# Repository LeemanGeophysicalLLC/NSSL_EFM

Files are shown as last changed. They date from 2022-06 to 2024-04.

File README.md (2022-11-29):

# Balloon Borne Electric Field Meter

This repository contains all files and relevant information for the electric field meter
(EFM) designed for NSSL. This instrument has been in existance for many years, but beginning
in approximatley 2019/2020 Leeman Geophysical was contracted to help design and implement the
next generation of the device. This README should be a living document keeping the most
current and relevant information on the assembly, operation, and programming of the
instrument.

Where there are other system components that are not directly part of the instrument (such as
the cutdown system), we will link to the relevant documentation.

## Mechanical Parts

A current version of the Fusion 360 project is [here](Mechanical/EFM%20v92.f3z), but be
careful as it is quite a bear with lots of older artifacts from previous revisions and
the assembly isn't completed as that just wasn't necessary to machine the parts.
Please update any changes made!

### Fiberglass Body and Spheres
These are provided by NSSL and we believed to be made by the OU Physics machine shop at some
time in the past. When more are needed we can evaluate the design and manufacturing options
at that time.

### Foams
The electronics for the EFM are protected from the environment (water, wind, and cold) by the
foam paddles that also serve to direct airflow to make the instrument rotate about the Earth
perpendicular axis. The foams are machined from 1" thick blue insulation foam such as
[item 14615](https://www.lowes.com/pd/Dow-Common-1-in-x-4-ft-x-8-ft-Actual-1-in-x-4-ft-x-8-ft-SCOREBOARD-1-R-5-Faced-Polystyrene-Garage-Door-Foam-Board-Insulation-with-Sound-Barr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) from Lowe's. We machine these on a
large format router and find that screwing the foam down to the base with drywall screws and
using a downcutting bit result in the best cuts. The foams are still difficult to machine well
as they still try to slide around, pull up, and generate massive amounts of static which can
sometimes cause false trips of the router's limit switch system.

Each end of the instrument has four foam plates. The solid models for the control end foams are
[here](Mechanical/Control_Foam/). The solid models for the motor end foams are
[here](Mechanical/Motor_Foam/).

### Machined Parts
We have tried to keep the number of custom machined parts to a minimum to make field repairs
as easy as possible, but there are a few necessary parts. Namely the "hub" which inserts into
the fiberglass tube body and provides driving force and a place for the fiber optic cable to
exit the tube. This hub is made from 6061 Aluminium and has as much material as possible
removed to make it light. This is very similar to the original design from the machine shop,
but with a much simplified bearing setup. A 2D drawing of the hub is available
[here](Mechanical/Machined_Parts/Hub%20Drawing.pdf).

An aluminium shaft screws into the hubs and passes through bearings to provide a low friction
suspension for the tube. The hub shaft 2D drawing is
[here](Mechanical/Machined_Parts/Hub%20Shaft%20Drawing.pdf). This should be secured into the
hubs with Loctite 242 blue thread locker. The other end has M8 washers (like McMaster
[98689A116](https://www.mcmaster.com/98689A116/)) and nuts (like McMaster
[90592A022](https://www.mcmaster.com/90592A022/)). Use Locktite 272 on the nuts.

The motor driver is a socket-like device that turns the rotating assembly by driving the
nut on the end of the hub shaft. It is secured to the motor shaft with #4 set screws such
as McMaster [98637A105](https://www.mcmaster.com/98637A105/). Use Locktite 272 on the set
screws. A drawing of the part is [here](Mechanical/Machined_Parts/Motor%20Driver%20Drawing.pdf).

### End Caps and Bearings
The end caps that support the rotating load are 3D printed for weight, cost, and simplicity.
The original sets were printed in PLA, but those have proven to be somewhat brittle and NSSL
is testing alternatives. The STL file to print the caps is
[here](Mechanical/3D_Prints/endcap.stl). Be sure to print with supports so that the bearing
pockets on the bottom accept the bearing nicely!

We chose easy to find skateboard bearings (8x22x7 size) such as [these](https://amzn.to/3GVvaEM)
and press them in gently with a socket on the outer bearing race and small hammer. There are
two bearings per endcap. End caps are bolted through the foam to either the fiber optic or
motor plates with nylon hardware #6 size.

* Screws McMaster [95868A312](https://www.mcmaster.com/catalog/128/3430/)
* Washers McMaster [90295A380](https://www.mcmaster.com/catalog/128/3546)
* Nuts McMaster [94812A300](https://www.mcmaster.com/catalog/128/3502/)

### Fiber Optic Plate
The [fiber optic coupler (PN 51 0241)](https://i-fiberoptics.com/connector-detail-mating.php?id=825&cat=mating) is inserted through this plate (use the threaded side and included nut).
The coupler is then cutoff flush with the nut, clearnace drilled, and chambered to allow the
fiberoptic cable to slip and turn in the coupler, but still be aligned with the pigtail
running to the control PCBA.

### Motor Mount Plate
The [motor](https://www.digikey.com/en/products/detail/dfrobot/FIT0441/6588579) mounts
to this simple 3D printed plate and is held onto the foam. The motor mounts
with M3 screws that are 5mm long, such as McMaster
[92000A114](https://www.mcmaster.com/92000a114/). The STL file is
[here](Mechanical/3D_Prints/motor_mount_plate.stl).

### Fiber Optic Cable
We use the plastic cable from Industrial Fiberoptics, part [GH4001](https://www.digikey.com/en/products/detail/industrial-fiber-optics/GH4001/1855657) or similar.

## Circuit Boards
### Analog PCBA
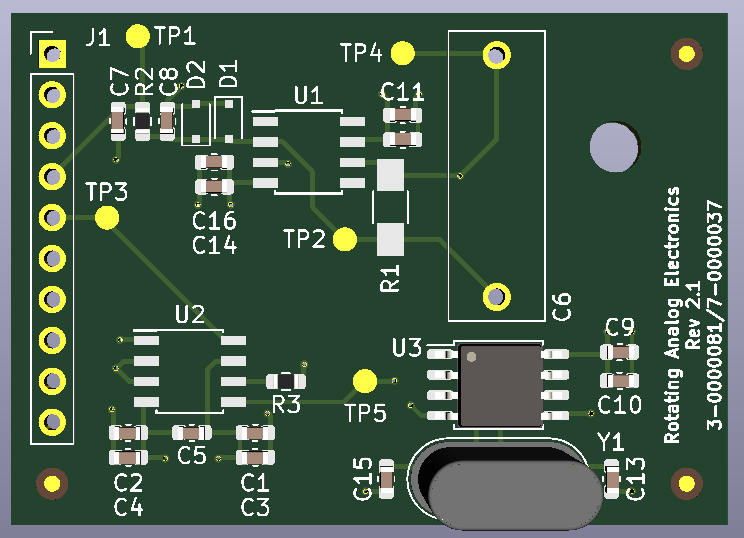
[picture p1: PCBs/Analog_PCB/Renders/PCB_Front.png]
Analog PCBA


The analog PCBA is really the heart of the EFM and what everything else is in service of. It is
a simple charge amplifier and filter. This design is basically a direct copy of the old EFM
as the charge amplifeir and filter were working just fine. We did some pretty extensive
comparisons between the old and new charge amps as well as testing for any temperature
dependence of the amplifier and filter. 

* [KiCAD Project](PCBs/Analog_PCB/KiCAD_Project)
* [PDF schematic](PCBs/Analog_PCB/PDFs/schematic.pdf)
* [Mechancial Drawing](PCBs/Analog_PCB/PDFs/pcb.pdf)

### Control PCBA
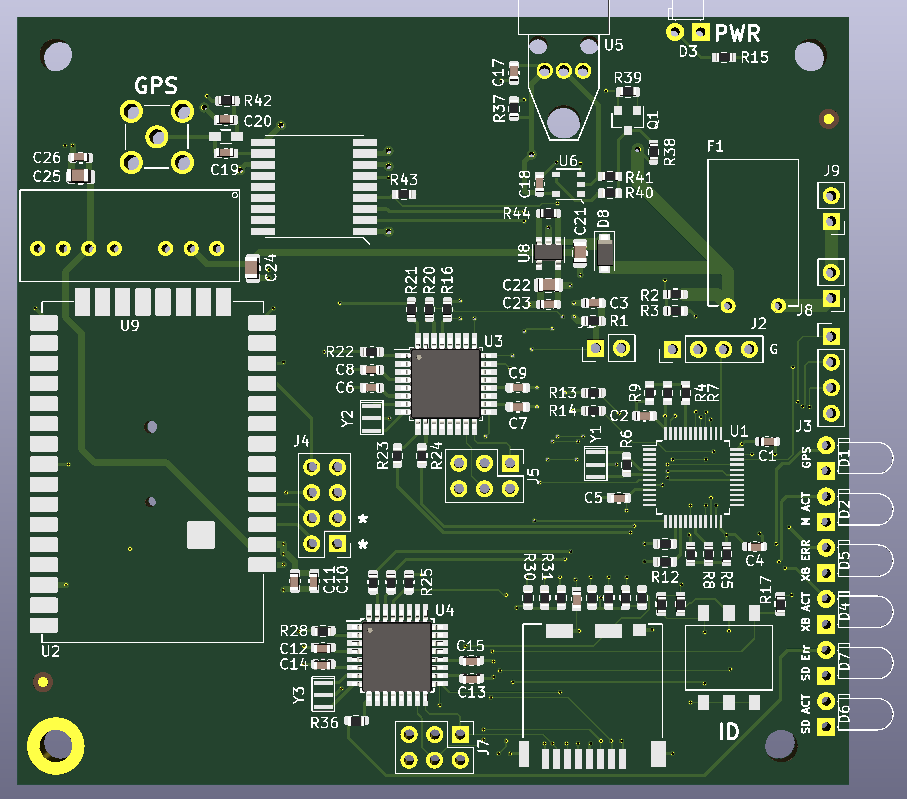
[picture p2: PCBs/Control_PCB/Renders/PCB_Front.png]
Control PCBA


The control PCBA manages the GPS, data logging, and transmitter. This board is easily the most
complex and expensive of the entire unit. There are three processors on the board. While this
is gross overkill, it allows us to easily modify the behavior, move workload, and change
functionality with three relatively simple bits of firmware instead of one more complex bit
that deals with a scheduler. The three functions are receiving fiber/GPS data, writing to the
SD card, and transmitting data. We do plan on moving transmit off the board to its own board
in the future so we can more easily change transmitters. We also need a transmitter evaluation
from NSSL to decide if we stay with XBee, go back to the 433MHz system, or do something
entirely different.

There are indicator lights for the status of the board along the edge
* SD ACT (green) - indicates write activity to the SD Card
* SD Err (red) - blinks at boot, then indicates problems with the SD card system
* XB ACT (green) - indicates write activity to the SD Card
* XB Err (red) - blinks at boot, then indicates problems with the XBee system. It also indicates
when the radio is locked out at startup waiting for the GPS to lock (it is on a timer)
* M ACT (green) - blinks with received data over the fiberoptic link
* GPS (green) - toggles on/off with the receiption of NMEA packets
* PWR (green) - On when battery power is applied

Note, we do not enable the transmitter for some time after boot to allow the GPS to get a lock.
We observed the XBee being active before the GPS locks can greatly increase lock times or in
a few cases even prevent lock.

The two sets of pins with * by the on J4 should be jumpered for the XBee radio to transmit.
You can un-jumper and connect a USB to 3.3V logic cable here to program the XBee radio.

* [KiCAD Project](PCBs/Control_PCB/KiCAD_Project)
* [PDF schematic](PCBs/Control_PCB/PDFs/schematic.pdf)
* [Mechancial Drawing](PCBs/Control_PCB/PDFs/pcb.pdf)

### CR123 Battery PCBA
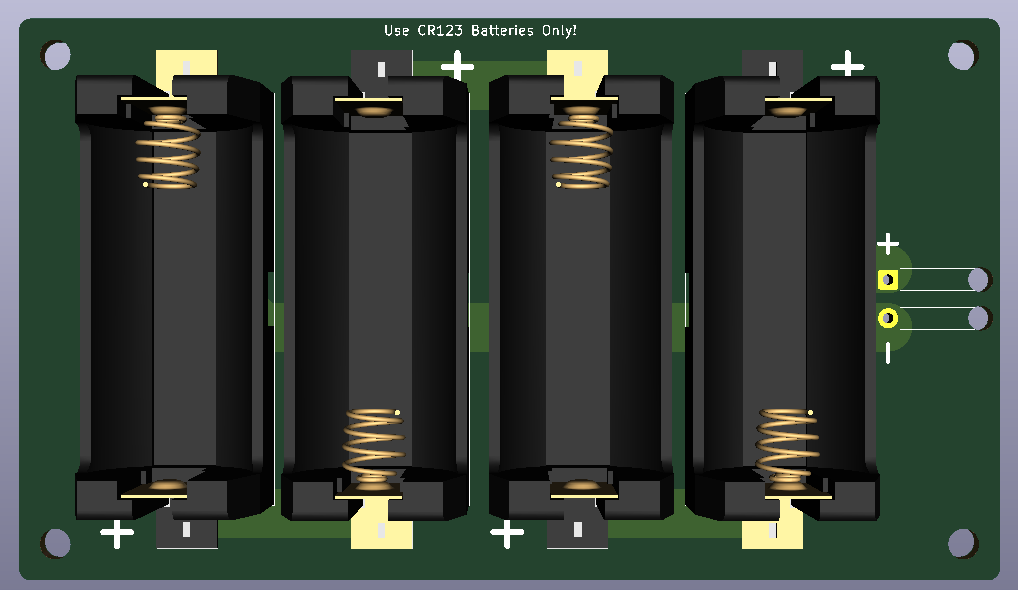
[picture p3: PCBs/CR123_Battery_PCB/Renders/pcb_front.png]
CR123 PCBA


This PCB is used for power of most items in the EFM for convenience. We tried CR2 batteries
and there is a CR2 board in the repository history, but they didn't have the capacity for all
applications and we didn't want to have yet another battery type on-board. There isn't much
to this board.

* [KiCAD Project](PCBs/CR123_Battery_PCB/KiCAD_Project)
* [PDF schematic](PCBs/CR123_Battery_PCB/PDFs/schematic.pdf)
* [Mechancial Drawing](PCBs/CR123_Battery_PCB/PDFs/pcb.pdf)

### Digital PCBA
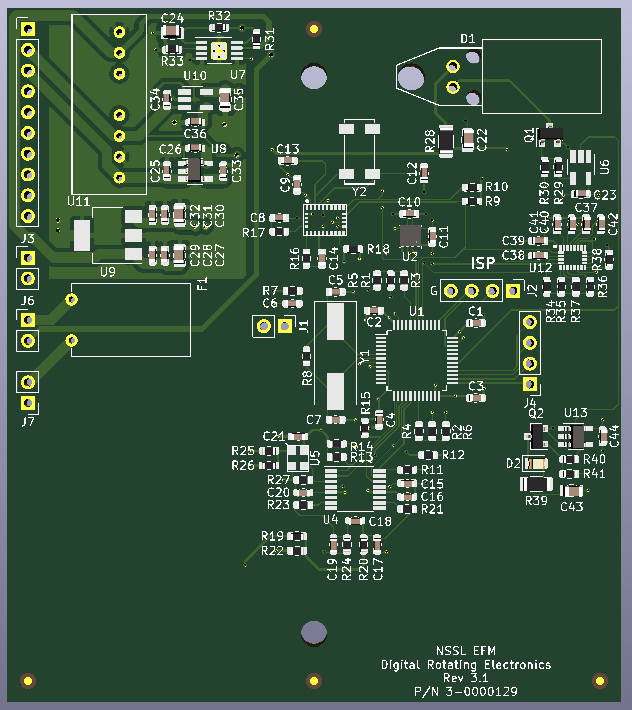
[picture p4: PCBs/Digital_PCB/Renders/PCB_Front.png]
Digital PCBA


The digital PCBA provides power to the analog PCBA, digitizes the charge amplifier, collects
IMU data, temperature, pressure, humidity, and sends it all down the fiber to the control
PCBA in the end foam. This PCB is relatively complex and has multiple IMU footprints as
the supply chain in 2022 has made it difficult to get any IMU, much less the same one over
and over. There is also a delay turn on circuit to help debounce the switch, but it was not
populated in the November 2022 batch as the parts were not available. Performance did not
appear to be impacted. There is an LED (D2) that mirrors the fiber sender for easy visual
confirmatino that data are being sent.

* [KiCAD Project](PCBs/Digital_PCB/KiCAD_Project)
* [PDF schematic](PCBs/Digital_PCB/PDFs/schematic.pdf)
* [Mechancial Drawing](PCBs/Digital_PCB/PDFs/pcb.pdf)

### Motor Control PCBA
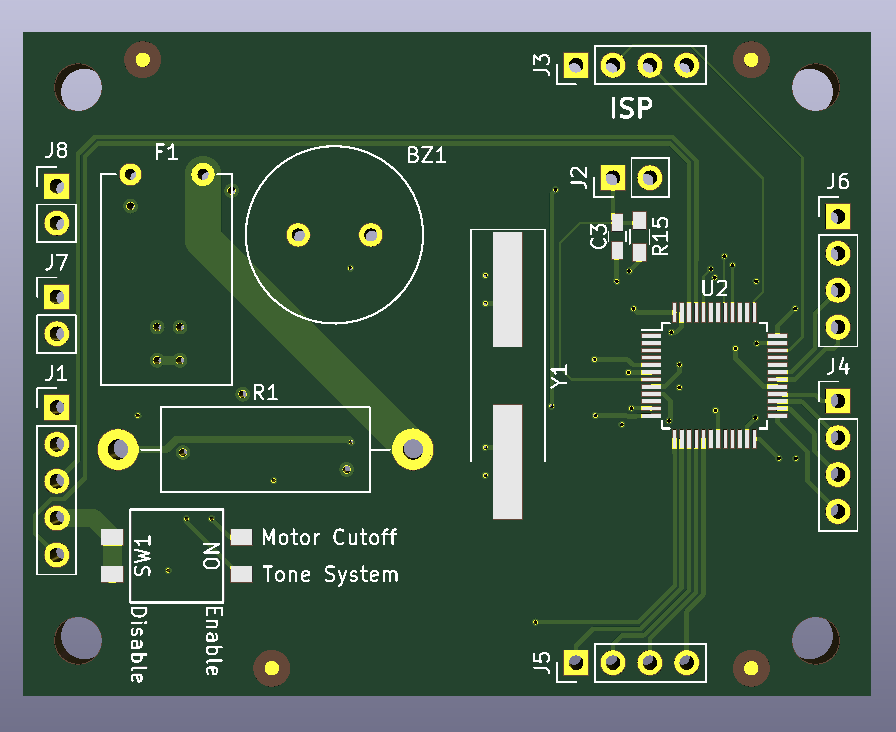
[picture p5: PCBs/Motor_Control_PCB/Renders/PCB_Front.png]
Motor Control PCBA


The motor control PCBA controls the PWM speed signal to the motor, which is a [DFRobot
FIT0441](https://www.digikey.com/en/products/detail/dfrobot/FIT0441/6588579), by reading
the motor's built in encoder. We target 120 RPM for the motor speed. In the November 2022
run we had to modify the PID coefficients with the newest motors and NSSL reports a slower
rotation rate, making meaning they changed the encoders in the motors. This requires further
investigation.

This board also houses a tone system which can be turned on to play a series of tones after
the motor has been detected as stalled. The motor cutoff on stall can be enabled or disabled.
At NSSL's request, if enabled, the motor will attempt to restart after approximately 1 minute.

* [KiCAD Project](PCBs/Motor_Control_PCB/KiCAD_Project)
* [PDF schematic](PCBs/Motor_Control_PCB/PDFs/schematic.pdf)
* [Mechancial Drawing](PCBs/Motor_Control_PCB/PDFs/pcb.pdf)

### Tracker PCBA
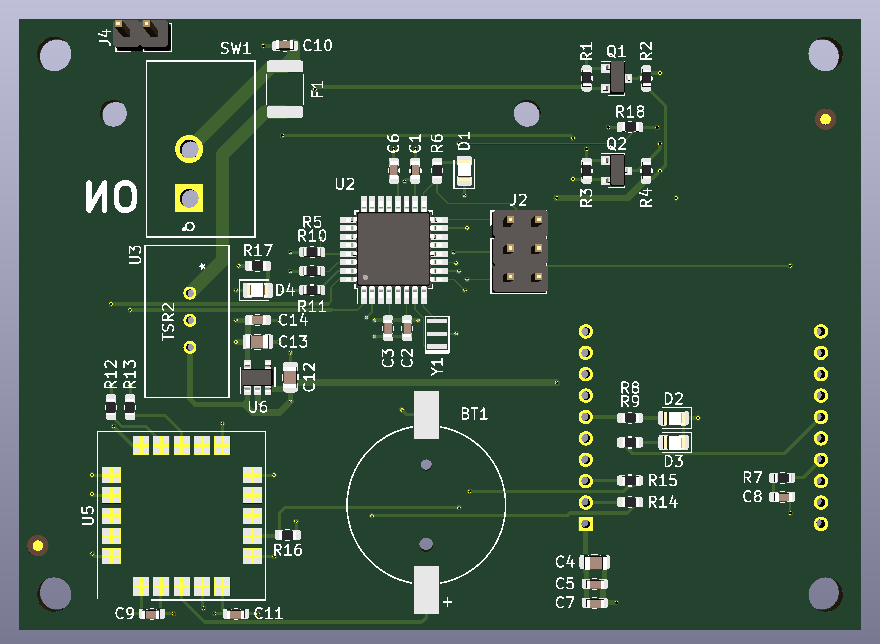
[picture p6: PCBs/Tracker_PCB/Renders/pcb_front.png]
Tracker PCBA


The tracker is designed to radio a GPS position and altitude to the Rock7 satellite network
to help with getting the instrument back. It also passes cutdown messages to the cutdown
module from satellite via a short-range XBee link.

* [KiCAD Project](PCBs/Tracker_PCB/KiCAD_Project)
* [PDF schematic](PCBs/Tracker_PCB/PDFs/schematic.pdf)
* [Mechancial Drawing](PCBs/Tracker_PCB/PDFs/pcb.pdf)

# Design Decisions Captured
* NSSL requested the tracker be independent from the rest of the instrument to allow it to be
used on other instruments and as a fully independent system.
* NSSL requested the cutdown be entire sepearte and as low cost as possible as these are not
always retreived. Hence the decision to NOT put a sat modem on it and/or combine it with the
tracker. There were also concerns of the train becoming seperated and not having a tracker
directly embedded with the expensive EFM or other instrument.

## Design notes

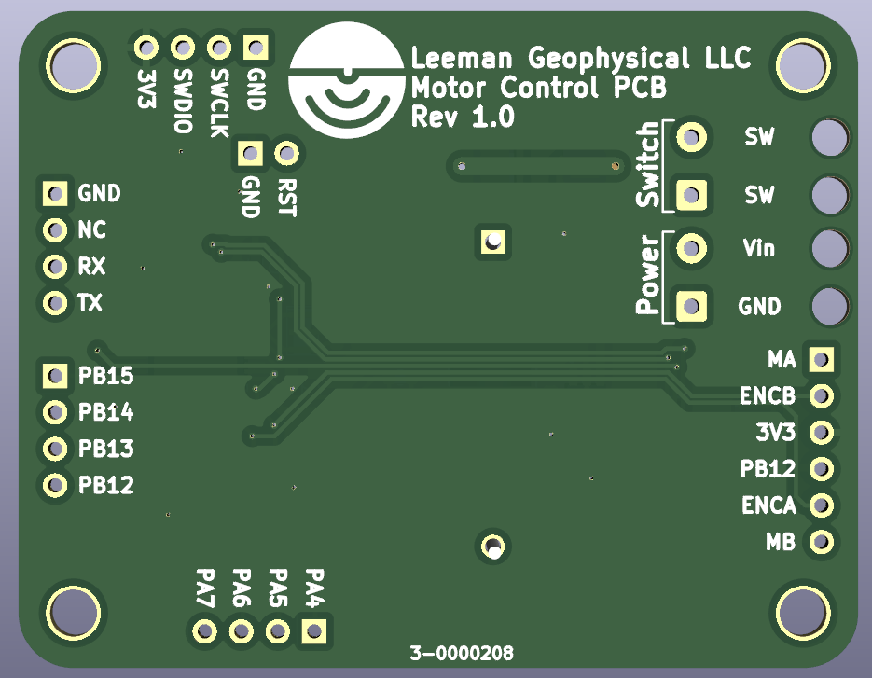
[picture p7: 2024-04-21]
PCBs/Motor_Control_PCB/Renders/pcb_back.png

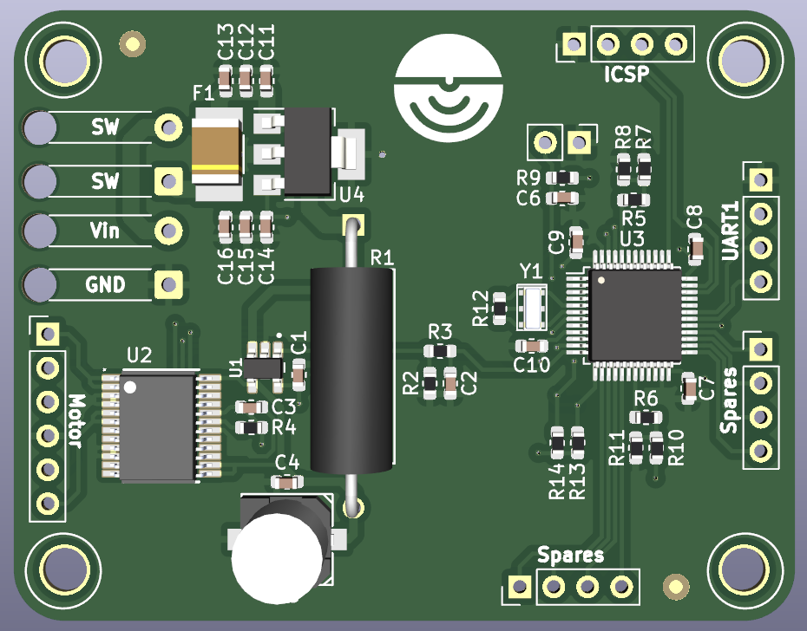
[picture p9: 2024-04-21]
PCBs/Motor_Control_PCB/Renders/pcb_front.png

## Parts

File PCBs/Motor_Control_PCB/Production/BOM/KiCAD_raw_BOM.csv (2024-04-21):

Reference | Value | Datasheet | Footprint | Qty | Internal Part Number | PValue | Populated
C1 | 1-0000007 | ~ | capacitors_0603:1-0000007 | 1 | 1-0000007 | 0.1uF | 1
C2 | 1-0000007 | ~ | capacitors_0603:1-0000007 | 1 | 1-0000007 | 0.1uF | 1
C3 | 1-0000007 | ~ | capacitors_0603:1-0000007 | 1 | 1-0000007 | 0.1uF | 1
C4 | 1-0000007 | ~ | capacitors_0603:1-0000007 | 1 | 1-0000007 | 0.1uF | 1
C5 | 1-0000176 | ~ | capacitors:1-0000176 | 1 | 1-0000176 | 10µF | 1
C6 | 1-0000018 | ~ | capacitors_0603:1-0000018 | 1 | 1-0000018 | 1uF | 1
C7 | 1-0000007 | ~ | capacitors_0603:1-0000007 | 1 | 1-0000007 | 0.1uF | 1
C8 | 1-0000007 | ~ | capacitors_0603:1-0000007 | 1 | 1-0000007 | 0.1uF | 1
C9 | 1-0000007 | ~ | capacitors_0603:1-0000007 | 1 | 1-0000007 | 0.1uF | 1
C10 | 1-0000007 | ~ | capacitors_0603:1-0000007 | 1 | 1-0000007 | 0.1uF | 1
C11 | 1-0000005 | ~ | capacitors_0603:1-0000005 | 1 | 1-0000005 | 10uF | 1
C12 | 1-0000018 | ~ | capacitors_0603:1-0000018 | 1 | 1-0000018 | 1uF | 1
C13 | 1-0000007 | ~ | capacitors_0603:1-0000007 | 1 | 1-0000007 | 0.1uF | 1
C14 | 1-0000007 | ~ | capacitors_0603:1-0000007 | 1 | 1-0000007 | 0.1uF | 1
C15 | 1-0000018 | ~ | capacitors_0603:1-0000018 | 1 | 1-0000018 | 1uF | 1
C16 | 1-0000005 | ~ | capacitors_0603:1-0000005 | 1 | 1-0000005 | 10uF | 1
F1 | 1-0001547 | ~ | fuses:1-0001547 | 1 | 1-0001547 | 5A | 1
FID1 | Fiducial_1mm_2mm | ~ | mechanical:Fiducial_1mm_Mask2mm | 1 | 0-0000000 | Fiducial | 0
FID2 | Fiducial_1mm_2mm | ~ | mechanical:Fiducial_1mm_Mask2mm | 1 | 0-0000000 | Fiducial | 0
H1 | Imperial4 | None | mechanical:MountingHole_imperial4 | 1 | 0-0000000 | #4 | 0
H2 | Imperial4 | None | mechanical:MountingHole_imperial4 | 1 | 0-0000000 | #4 | 0
H3 | Imperial4 | None | mechanical:MountingHole_imperial4 | 1 | 0-0000000 | #4 | 0
H4 | Imperial4 | None | mechanical:MountingHole_imperial4 | 1 | 0-0000000 | #4 | 0
J1 | NP_Conn_01x06 | ~ | np_connectors:PinHeader_1x06_P2.54mm_Vertical | 1 | 0-0000000 | 01x06 | 0
J2 | NP_Conn_01x02 | ~ | np_connectors:PinHeader_1x02_P2.54mm_Vertical | 1 | 0-0000000 | NP_Conn_01x02 | 0
J3 | NP_Conn_01x04 | ~ | np_connectors:PinHeader_1x04_P2.54mm_Vertical | 1 | 0-0000000 | NP_Conn_01x04 | 0
J4 | NP_Conn_01x04 | ~ | np_connectors:PinHeader_1x04_P2.54mm_Vertical | 1 | 0-0000000 | NP_Conn_01x04 | 0
J5 | NP_Conn_01x04 | ~ | np_connectors:PinHeader_1x04_P2.54mm_Vertical | 1 | 0-0000000 | NP_Conn_01x04 | 0
J6 | NP_Conn_01x04 | ~ | np_connectors:PinHeader_1x04_P2.54mm_Vertical | 1 | 0-0000000 | NP_Conn_01x04 | 0
J7 | NP_Conn_01x02_Relief | ~ | np_connectors:SolderWire_1x02_Relief | 1 | 0-0000000 | NP_Conn_01x02 | 0
J8 | NP_Conn_01x02_Relief | ~ | np_connectors:SolderWire_1x02_Relief | 1 | 0-0000000 | NP_Conn_01x02 | 0
PCB1 | barepcb |  | misc:barepcb | 1 | 3-0000208 | Bare PCB | 1
R1 | 1-0001546 | ~ | resistors:1-0001546 | 1 | 1-0001546 | 100m | 1
R2 | 1-0000010 | ~ | resistors_0603:1-0000010 | 1 | 1-0000010 | 10k | 1
R3 | 1-0000009 | ~ | resistors_0603:1-0000009 | 1 | 1-0000009 | 1M | 1
R4 | 1-0000010 | ~ | resistors_0603:1-0000010 | 1 | 1-0000010 | 10k | 1
R5 | 1-0000174 | ~ | resistors_0603:1-0000174 | 1 | 1-0000174 | 100k | 1
R6 | 1-0000174 | ~ | resistors_0603:1-0000174 | 1 | 1-0000174 | 100k | 1
R7 | 1-0000006 | ~ | resistors_0603:1-0000006 | 1 | 1-0000006 | NP | 0
R8 | 1-0000006 | ~ | resistors_0603:1-0000006 | 1 | 1-0000006 | 0R0 | 1
R9 | 1-0000010 | ~ | resistors_0603:1-0000010 | 1 | 1-0000010 | 10k | 1
R10 | 1-0000006 | ~ | resistors_0603:1-0000006 | 1 | 1-0000006 | NP | 0
R11 | 1-0000006 | ~ | resistors_0603:1-0000006 | 1 | 1-0000006 | 0R0 | 1
R12 | 1-0000006 | ~ | resistors_0603:1-0000006 | 1 | 1-0000006 | NP | 0
R13 | 1-0000010 | ~ | resistors_0603:1-0000010 | 1 | 1-0000010 | 10k | 1
R14 | 1-0000010 | ~ | resistors_0603:1-0000010 | 1 | 1-0000010 | 10k | 1
U1 | 1-0000452 |  | others:1-0000452 | 1 | 1-0000452 | INA169 | 1
U2 | 1-0001532 |  | motor_drivers:1-0001532 | 1 | 1-0001532 | TB6612 | 1
U3 | 1-0000207 |  | microcontrollers:1-0000207 | 1 | 1-0000207 | STM32F103 | 1
U4 | 1-0000196 |  | regulators:1-0000196 | 1 | 1-0000196 | LT1521 | 1
Y1 | 1-0000721 | ~ | crystals_resonators:1-0000721 | 1 | 1-0000721 | 8MHz | 1

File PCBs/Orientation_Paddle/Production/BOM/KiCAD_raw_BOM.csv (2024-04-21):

Reference | Value | Datasheet | Footprint | Qty | Internal Part Number | PValue | Populated
BT1 | 1-0000246 |  | batteries:1-0000246 | 1 | 1-0000246 | CR1220 | 1
C1 | 1-0000007 | ~ | capacitors_0603:1-0000007 | 1 | 1-0000007 | 0.1uF | 1
C2 | 1-0000136 | ~ | capacitors_1206:1-0000136 | 1 | 1-0000136 | 4.7uF | 1
C3 | 1-0000018 | ~ | capacitors_0603:1-0000018 | 1 | 1-0000018 | 1uF | 1
C4 | 1-0000136 | ~ | capacitors_1206:1-0000136 | 1 | 1-0000136 | 4.7uF | 1
C5 | 1-0000019 | ~ | capacitors_0603:1-0000019 | 1 | 1-0000019 | 4.7uF | 1
C6 | 1-0000007 | ~ | capacitors_0603:1-0000007 | 1 | 1-0000007 | 0.1uF | 1
C7 | 1-0000018 | ~ | capacitors_0603:1-0000018 | 1 | 1-0000018 | 1uF | 1
C8 | 1-0000007 | ~ | capacitors_0603:1-0000007 | 1 | 1-0000007 | 0.1uF | 1
C9 | 1-0000007 | ~ | capacitors_0603:1-0000007 | 1 | 1-0000007 | 0.1uF | 1
C10 | 1-0000007 | ~ | capacitors_0603:1-0000007 | 1 | 1-0000007 | 0.1uF | 1
C11 | 1-0000007 | ~ | capacitors_0603:1-0000007 | 1 | 1-0000007 | 0.1uF | 1
C12 | 1-0000007 | ~ | capacitors_0603:1-0000007 | 1 | 1-0000007 | 0.1uF | 1
C13 | 1-0000007 | ~ | capacitors_0603:1-0000007 | 1 | 1-0000007 | 0.1uF | 1
C14 | 1-0000075 | ~ | capacitors_0805:1-0000075 | 1 | 1-0000075 | 10uF | 1
C15 | 1-0000018 | ~ | capacitors_0603:1-0000018 | 1 | 1-0000018 | 1uF | 1
C16 | 1-0000007 | ~ | capacitors_0603:1-0000007 | 1 | 1-0000007 | 0.1uF | 1
C17 | 1-0000007 | ~ | capacitors_0603:1-0000007 | 1 | 1-0000007 | 0.1uF | 1
C18 | 1-0000007 | ~ | capacitors_0603:1-0000007 | 1 | 1-0000007 | 0.1uF | 1
C19 | 1-0000007 | ~ | capacitors_0603:1-0000007 | 1 | 1-0000007 | 0.1uF | 0
C20 | 1-0000007 | ~ | capacitors_0603:1-0000007 | 1 | 1-0000007 | 0.1uF | 1
D1 | 1-0000399 |  | leds_other:1-0000399 | 1 | 1-0000399 | 1655 | 1
D2 | 1-0000599 | ~ | leds_0805:1-0000599 | 1 | 1-0000599 | Blue | 1
D3 | 1-0000601 | ~ | leds_0805:1-0000601 | 1 | 1-0000601 | Yellow | 1
F1 | 1-0001517 | ~ | fuses:1-0001517 | 1 | 1-0001517 | 1A | 1
FID1 | Fiducial_1mm_2mm | ~ | mechanical:Fiducial_1mm_Mask2mm | 1 | 0-0000000 | Fiducial | 0
FID2 | Fiducial_1mm_2mm | ~ | mechanical:Fiducial_1mm_Mask2mm | 1 | 0-0000000 | Fiducial | 0
H1 | Imperial6 | None | mechanical:MountingHole_imperial6 | 1 | 0-0000000 | M3 | 0
H2 | Imperial6 | None | mechanical:MountingHole_imperial6 | 1 | 0-0000000 | M3 | 0
H3 | Imperial6 | None | mechanical:MountingHole_imperial6 | 1 | 0-0000000 | M3 | 0
H4 | Imperial6 | None | mechanical:MountingHole_imperial6 | 1 | 0-0000000 | M3 | 0
J1 | NP_Conn_01x04_Relief | ~ | np_connectors:SolderWire_1x04_Relief | 1 | 0-0000000 | Encoder | 0
J2 | 1-0001205 | ~ | connectors:1-0001205 | 1 | 1-0001205 | Qwiic | 1
J3 | NP_Conn_01x03_Relief | ~ | np_connectors:SolderWire_1x03_Relief | 1 | 0-0000000 | AH1815 (1-1545) | 0
J4 | NP_Conn_01x02_Relief | ~ | np_connectors:SolderWire_1x02_Relief | 1 | 0-0000000 | NP_Conn_01x02 | 0
J5 | NP_Conn_01x02_Relief | ~ | np_connectors:SolderWire_1x02_Relief | 1 | 0-0000000 | NP_Conn_01x02 | 0
J6 | NP_Conn_01x04 | ~ | np_connectors:PinHeader_1x04_P2.54mm_Vertical | 1 | 0-0000000 | Debug | 0
J7 | NP_Conn_01x04 | ~ | np_connectors:PinHeader_1x04_P2.54mm_Vertical | 1 | 0-0000000 | ISP | 0
J8 | NP_Conn_01x02 | ~ | np_connectors:PinHeader_1x02_P2.54mm_Vertical | 1 | 0-0000000 | Reset | 0
J9 | 1-0000050 | ~ | connectors:1-0000050 | 1 | 1-0000050 | XBee Socket | 1
J10 | 1-0000190 |  | connectors:1-0000190 | 1 | 1-0000190 | DM3CS | 1
JP1 | SolderJumper_3_Open | ~ | Jumper:SolderJumper-3_P1.3mm_Open_RoundedPad1.0x1.5mm_NumberLabels | 1
JP2 | SolderJumper_3_Open | ~ | Jumper:SolderJumper-3_P1.3mm_Open_RoundedPad1.0x1.5mm_NumberLabels | 1
JP5 | SolderJumper_3_Open | ~ | Jumper:SolderJumper-3_P1.3mm_Open_RoundedPad1.0x1.5mm_NumberLabels | 1
JP6 | SolderJumper_3_Open | ~ | Jumper:SolderJumper-3_P1.3mm_Open_RoundedPad1.0x1.5mm_NumberLabels | 1
L1 | 1-0000931 |  | inductors:1-0000931 | 1 | 1-0000931 | 3.3uH | 1
PCB1 | barepcb |  | misc:barepcb | 1 | 3-0000205 | Bare PCB | 1
PS1 | 1-0000727 |  | dc_dc_converters:1-0000727 | 1 | 1-0000727 | TSR 0.5 | 1
R1 | 1-0000679 | ~ | resistors_0603:1-0000679 | 1 | 1-0000679 | 470 | 1
R2 | 1-0000009 | ~ | resistors_0603:1-0000009 | 1 | 1-0000009 | NP | 0
R3 | 1-0000010 | ~ | resistors_0603:1-0000010 | 1 | 1-0000010 | 10k | 1
R4 | 1-0000010 | ~ | resistors_0603:1-0000010 | 1 | 1-0000010 | 10k | 1
R5 | 1-0000010 | ~ | resistors_0603:1-0000010 | 1 | 1-0000010 | 10k | 1
R6 | 1-0000010 | ~ | resistors_0603:1-0000010 | 1 | 1-0000010 | 10k | 1
R7 | 1-0000010 | ~ | resistors_0603:1-0000010 | 1 | 1-0000010 | 10k | 1
R8 | 1-0000010 | ~ | resistors_0603:1-0000010 | 1 | 1-0000010 | 10k | 1
R9 | 1-0000006 | ~ | resistors_0603:1-0000006 | 1 | 1-0000006 | NP | 0
R10 | 1-0000174 | ~ | resistors_0603:1-0000174 | 1 | 1-0000174 | 100k | 1
R11 | 1-0000010 | ~ | resistors_0603:1-0000010 | 1 | 1-0000010 | 10k | 1
R12 | 1-0000006 | ~ | resistors_0603:1-0000006 | 1 | 1-0000006 | NP | 0
R13 | 1-0000174 | ~ | resistors_0603:1-0000174 | 1 | 1-0000174 | 100k | 1
R14 | 1-0000010 | ~ | resistors_0603:1-0000010 | 1 | 1-0000010 | 10k | 1
R15 | 1-0000008 | ~ | resistors_0603:1-0000008 | 1 | 1-0000008 | 150 | 1
R16 | 1-0000006 | ~ | resistors_0603:1-0000006 | 1 | 1-0000006 | NP | 0
R17 | 1-0000008 | ~ | resistors_0603:1-0000008 | 1 | 1-0000008 | 150 | 1
R18 | 1-0000174 | ~ | resistors_0603:1-0000174 | 1 | 1-0000174 | 100k | 1
R19 | 1-0000174 | ~ | resistors_0603:1-0000174 | 1 | 1-0000174 | 100k | 1
U1 | 1-0001232 |  | regulators:1-0001232 | 1 | 1-0001232 | LDL1117 | 1
U2 | 1-0001471 |  | sensors:1-0001471 | 1 | 1-0001471 | BME688 | 1
U3 | 1-0000207 |  | microcontrollers:1-0000207 | 1 | 1-0000207 | STM32F103 | 1
U4 | 1-0000446 |  | others:1-0000446 | 1 | 1-0000446 | SAM-M8Q-0-10 | 1
U5 | 1-0000785 |  | others:1-0000785 | 1 | 1-0000785 | XB3-24 | 1
Y1 | 1-0000721 | ~ | crystals_resonators:1-0000721 | 1 | 1-0000721 | 8MHz | 1

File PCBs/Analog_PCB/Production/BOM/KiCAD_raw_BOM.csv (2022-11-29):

Reference | Value | Footprint | Datasheet | Internal Part Number | Populated
C7 | 0.39nF | Capacitor_SMD:C_0603_1608Metric | ~ | 1-0000418 | 1
C8 | 0.39nF | Capacitor_SMD:C_0603_1608Metric | ~ | 1-0000418 | 1
R2 | 100 | Resistor_SMD:R_0603_1608Metric | ~ | 1-0000180 | 1
D1 | 1N4148 | Diodes_SMD:D_SOD-323F | ~ | 1-0000417 | 1
D2 | 1N4148 | Diodes_SMD:D_SOD-323F | ~ | 1-0000417 | 1
C6 | 0.1u | lib_fp:1-0000787 | ~ | 1-0000787 | 1
R1 | 100M | Resistors_SMD:R_1206_HandSoldering | ~ | 1-0000416 | 1
U1 | LF356 | Housings_SOIC:SOIC-8_3.9x4.9mm_Pitch1.27mm |  | 1-0000419 | 1
U2 | LTC1569-6 | Housings_SOIC:SOIC-8_3.9x4.9mm_Pitch1.27mm |  | 1-0000414 | 1
R3 | 10k | Resistor_SMD:R_0603_1608Metric | ~ | 1-0000010 | 1
C5 | 1u | Capacitor_SMD:C_0603_1608Metric | ~ | 1-0000018 | 1
C3 | 0.1u | Capacitor_SMD:C_0603_1608Metric | ~ | 1-0000007 | 1
C4 | 0.1u | Capacitor_SMD:C_0603_1608Metric | ~ | 1-0000007 | 1
C12 | 0.1u | Capacitor_SMD:C_0603_1608Metric | ~ | 1-0000007 | 1
C14 | 0.1u | Capacitor_SMD:C_0603_1608Metric | ~ | 1-0000007 | 1
C11 | 1u | Capacitor_SMD:C_0603_1608Metric | ~ | 1-0000018 | 1
C16 | 1u | Capacitor_SMD:C_0603_1608Metric | ~ | 1-0000018 | 1
C2 | 1u | Capacitor_SMD:C_0603_1608Metric | ~ | 1-0000018 | 1
C1 | 1u | Capacitor_SMD:C_0603_1608Metric | ~ | 1-0000018 | 1
J1 | Board to Board | Pin_Headers:Pin_Header_Straight_1x10_Pitch2.54mm | ~ | 0-0000000 | 1
TP3 | TestPoint | Measurement_Points:Measurement_Point_Round-SMD-Pad_Small | ~ | 0-0000000 | 0
TP4 | TestPoint | Measurement_Points:Measurement_Point_Round-SMD-Pad_Small | ~ | 0-0000000 | 0
TP2 | TestPoint | Measurement_Points:Measurement_Point_Round-SMD-Pad_Small | ~ | 0-0000000 | 0
TP1 | TestPoint | Measurement_Points:Measurement_Point_Round-SMD-Pad_Small | ~ | 0-0000000 | 0
TP5 | TestPoint | Measurement_Points:Measurement_Point_Round-SMD-Pad_Small | ~ | 0-0000000 | 0
H1 | MountingHole | Mounting_Holes:MountingHole_3.2mm_M3_ISO7380 | ~ | 0-0000000 | 0
FID1 | Fiducial | Fiducials:Fiducial_1mm_Dia_2mm_Outer | ~ | 0-0000000 | 0
FID2 | Fiducial | Fiducials:Fiducial_1mm_Dia_2mm_Outer | ~ | 0-0000000 | 0
FID3 | Fiducial | Fiducials:Fiducial_1mm_Dia_2mm_Outer | ~ | 0-0000000 | 0
U3 | ATtiny45-20SU | Package_SO:SOIC-8_5.275x5.275mm_P1.27mm | http://ww1.microchip.com/downloads/en/DeviceDoc/atmel-2586-avr-8-bit-microcontroller-attiny25-attiny45-attiny85_datasheet.pdf | 1-0000758 | 1
C9 | 1u | Capacitor_SMD:C_0603_1608Metric | ~ | 1-0000018 | 1
C10 | 0.1u | Capacitor_SMD:C_0603_1608Metric | ~ | 1-0000007 | 1
Y1 | 20MHz | Crystal:Crystal_HC49-U_Vertical | ~ | 1-0000723 | 1
C13 | 20p | Capacitor_SMD:C_0603_1608Metric | ~ | 1-0000204 | 1
C15 | 20p | Capacitor_SMD:C_0603_1608Metric | ~ | 1-0000204 | 1
PCB1 | barepcb | misc:barepcb |  | 3-0000081 | 1

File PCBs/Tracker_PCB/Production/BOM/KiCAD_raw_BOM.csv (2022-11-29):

Reference | Value | Footprint | Datasheet | Internal Part Number | Populated | PValue
J1 | RockBlock9603 | lib_fp:picoblade | ~ | 1-0000790 | 1
U5 | ublox_SAM-M8Q | RF_GPS:ublox_SAM-M8Q | https://www.u-blox.com/sites/default/files/SAM-M8Q_DataSheet_%28UBX-16012619%29.pdf | 1-0000446 | 1
BT1 | CR1220 | lib_fp:S8411-45R | ~ | 1-0000246 | 1
C11 | 1-0000007 | capacitors_0603:1-0000007 | ~ | 1-0000007 | 1 | 0.1uF
C9 | 1-0000007 | capacitors_0603:1-0000007 | ~ | 1-0000007 | 1 | 0.1uF
U1 | XBee | lib_fp:XBee |  | 1-0000785 | 1
U3 | TSR2 | lib_fp:TSR 2-2450 |  | 1-0000748 | 1
J4 | Battery | Connector_PinHeader_2.54mm:PinHeader_1x02_P2.54mm_Vertical | ~ | 0-0000000 | 0
SW1 | SW_SPST | lib_fp:SW_GF-123-0054 | ~ | 1-0000786 | 1
J3 | Switch | Connector_PinHeader_2.54mm:PinHeader_1x02_P2.54mm_Vertical | ~ | 0-0000000 | 0
U6 | MIC5219-3.3YM5 | Package_TO_SOT_SMD:SOT-23-5 | http://ww1.microchip.com/downloads/en/DeviceDoc/MIC5219-500mA-Peak-Output-LDO-Regulator-DS20006021A.pdf | 1-0000658 | 1
F1 | Polyfuse | Fuse:Fuse_1812_4532Metric | ~ | 1-0000002 | 1
C10 | 1-0000007 | capacitors_0603:1-0000007 | ~ | 1-0000007 | 1 | 0.1uF
C14 | 1-0000007 | capacitors_0603:1-0000007 | ~ | 1-0000007 | 1 | 0.1uF
J2 | ICSP | Connector_PinHeader_2.54mm:PinHeader_2x03_P2.54mm_Vertical | ~ | 0-0000000 | 0
C5 | 1-0000018 | capacitors_0603:1-0000018 | ~ | 1-0000018 | 1 | 1uF
C7 | 1-0000007 | capacitors_0603:1-0000007 | ~ | 1-0000007 | 1 | 0.1uF
U2 | ATmega328P-AU | Package_QFP:TQFP-32_7x7mm_P0.8mm |  | 1-0000566 | 1
C6 | 1-0000007 | capacitors_0603:1-0000007 | ~ | 1-0000007 | 1 | 0.1uF
Y1 | 16MHz | lib_fp:Resonator | ~ | 1-0000569 | 1
R5 | 1-0000010 | resistors_0603:1-0000010 | ~ | 1-0000010 | 1 | 10k
C1 | 1-0000007 | capacitors_0603:1-0000007 | ~ | 1-0000007 | 1 | 0.1uF
C2 | 1-0000007 | capacitors_0603:1-0000007 | ~ | 1-0000007 | 1 | 0.1uF
C3 | 1-0000007 | capacitors_0603:1-0000007 | ~ | 1-0000007 | 1 | 0.1uF
R10 | 1-0000006 | resistors_0603:1-0000006 | ~ | 1-0000006 | 1 | 0R0
R11 | 1-0000006 | resistors_0603:1-0000006 | ~ | 1-0000006 | 1 | 0R0
R12 | 1-0000006 | resistors_0603:1-0000006 | ~ | 1-0000006 | 1 | 0R0
R13 | 1-0000006 | resistors_0603:1-0000006 | ~ | 1-0000006 | 1 | 0R0
R14 | 1-0000006 | resistors_0603:1-0000006 | ~ | 1-0000006 | 1 | 0R0
R15 | 1-0000006 | resistors_0603:1-0000006 | ~ | 1-0000006 | 1 | 0R0
R8 | 1-0000008 | resistors_0603:1-0000008 | ~ | 1-0000008 | 1 | 150
D2 | Blue | LED_SMD:LED_0805_2012Metric | ~ | 1-0000599 | 1
R9 | 1-0000008 | resistors_0603:1-0000008 | ~ | 1-0000008 | 1 | 150
D3 | Yellow | LED_SMD:LED_0805_2012Metric | ~ | 1-0000601 | 1
R7 | 1-0000006 | resistors_0603:1-0000006 | ~ | 1-0000006 | 0 | NP
C8 | 1-0000007 | capacitors_0603:1-0000007 | ~ | 1-0000007 | 0 | 0.1uF
R16 | 1-0000010 | resistors_0603:1-0000010 | ~ | 1-0000010 | 0 | NP
R18 | 1-0000010 | resistors_0603:1-0000010 | ~ | 1-0000010 | 0 | NP
R17 | 1-0000008 | resistors_0603:1-0000008 | ~ | 1-0000008 | 1 | 150
D4 | Green | LED_SMD:LED_0805_2012Metric | ~ | 1-0000598 | 1
R6 | 1-0000008 | resistors_0603:1-0000008 | ~ | 1-0000008 | 1 | 150
D1 | Blue | LED_SMD:LED_0805_2012Metric | ~ | 1-0000599 | 1
Q1 | BSS138 | Package_TO_SOT_SMD:SOT-23 | https://www.onsemi.com/pub/Collateral/BSS138-D.PDF | 1-0000340 | 1
R1 | 1-0000013 | resistors_0603:1-0000013 | ~ | 1-0000013 | 1 | 1k
R2 | 1-0000013 | resistors_0603:1-0000013 | ~ | 1-0000013 | 1 | 1k
Q2 | BSS138 | Package_TO_SOT_SMD:SOT-23 | https://www.onsemi.com/pub/Collateral/BSS138-D.PDF | 1-0000340 | 1
R3 | 1-0000013 | resistors_0603:1-0000013 | ~ | 1-0000013 | 1 | 1k
R4 | 1-0000013 | resistors_0603:1-0000013 | ~ | 1-0000013 | 1 | 1k
U4 | RockBlockMechanical | lib_fp:RockBlock_Mechanical |  | 1-0000789 | 1
FID1 | Fiducial | Fiducial:Fiducial_1mm_Mask2mm | ~ | 0-0000000 | 0
FID2 | Fiducial | Fiducial:Fiducial_1mm_Mask2mm | ~ | 0-0000000 | 0
H1 | MountingHole | MountingHole:MountingHole_3.2mm_M3_DIN965 | ~ | 0-0000000 | 0
H2 | MountingHole | MountingHole:MountingHole_3.2mm_M3_DIN965 | ~ | 0-0000000 | 0
H3 | MountingHole | MountingHole:MountingHole_3.2mm_M3_DIN965 | ~ | 0-0000000 | 0
H4 | MountingHole | MountingHole:MountingHole_3.2mm_M3_DIN965 | ~ | 0-0000000 | 0
C13 | 1-0000075 | capacitors_0805:1-0000075 | ~ | 1-0000075 | 1 | 10uF
C12 | 1-0000075 | capacitors_0805:1-0000075 | ~ | 1-0000075 | 1 | 10uF
C4 | 1-0000075 | capacitors_0805:1-0000075 | ~ | 1-0000075 | 1 | 10uF
PCB1 | barepcb | lib_fp:BarePCB |  | 3-0000068 | 1

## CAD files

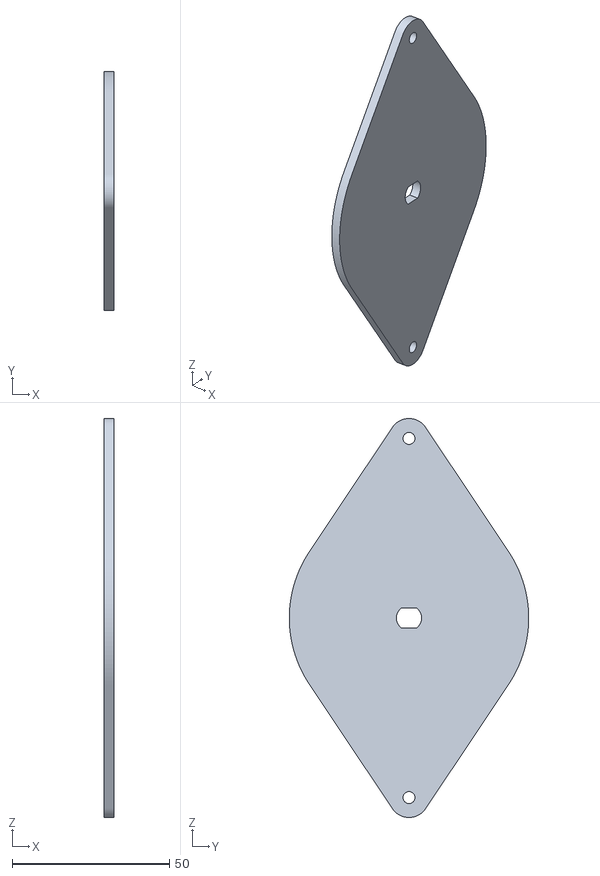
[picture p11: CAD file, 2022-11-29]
Mechanical/3D_Prints/fiber_mount_plate.stl
3.17 x 76.2 x 127.0

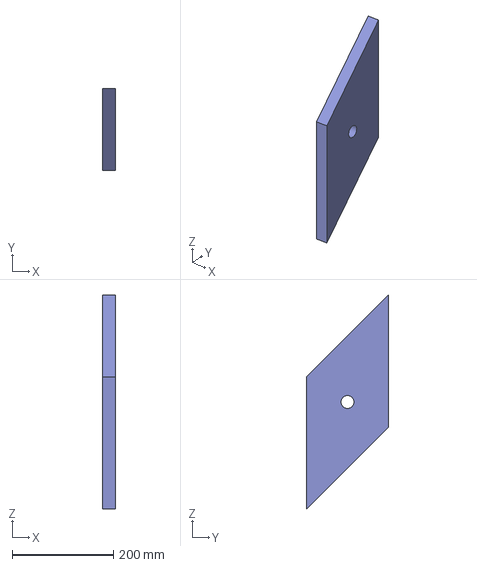
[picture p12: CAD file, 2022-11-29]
Mechanical/Control_Foam/Control Foam 3.step
25.4 x 161.6 x 422.0 mm

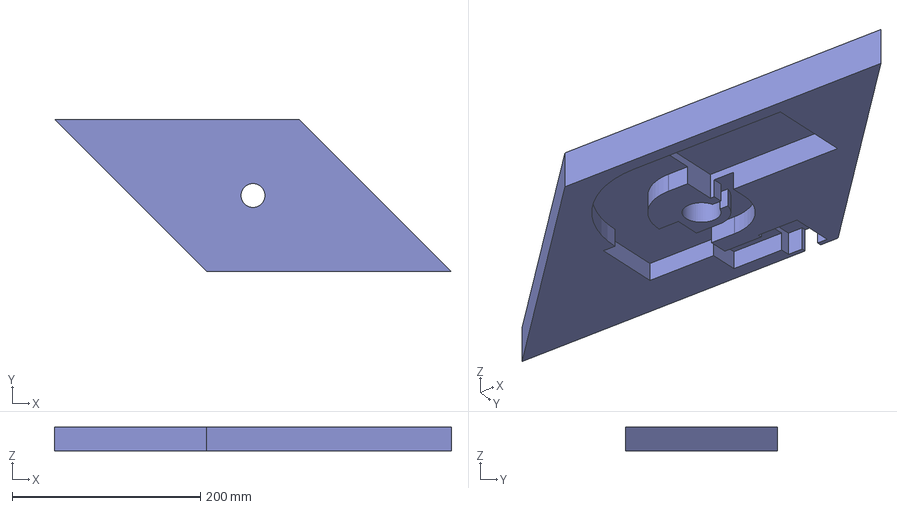
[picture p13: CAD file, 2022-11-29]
Mechanical/Motor_Foam/foam motor 2.step
422.0 x 161.6 x 25.4 mm

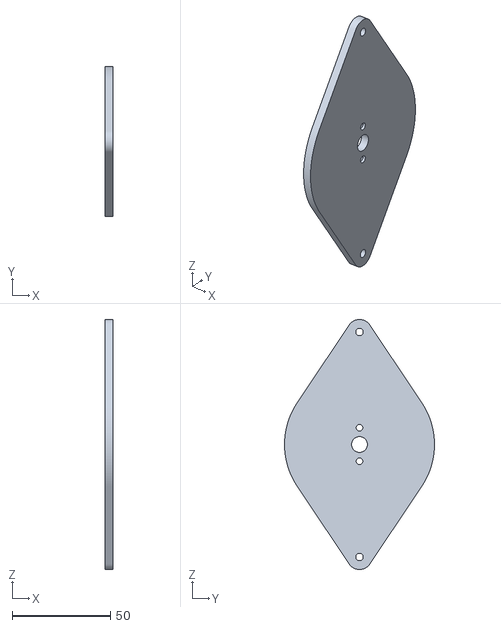
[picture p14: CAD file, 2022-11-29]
Mechanical/3D_Prints/motor_mount_plate.stl
3.94 x 76.2 x 127.0

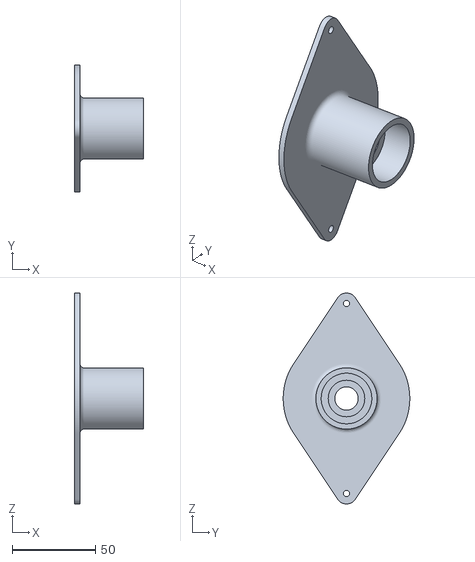
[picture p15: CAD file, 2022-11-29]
Mechanical/3D_Prints/endcap.stl
41.3 x 76.2 x 127.0

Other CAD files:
Mechanical/Control_Foam/Control Foam 4.step
Mechanical/Motor_Foam/foam motor 1.step
Mechanical/Control_Foam/Control Foam 1.step
Mechanical/Motor_Foam/foam motor 3.step
Mechanical/Control_Foam/Control Foam 2.step
Mechanical/Motor_Foam/foam motor 4.step
Mechanical/EFM v92.f3z

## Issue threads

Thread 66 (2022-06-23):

Remove Testpoints from Cutdown

jrleeman, 2022-06-23:
Test points 1-0000952 didn't work to hold the cable, so we can remove them.

jrleeman, 2022-11-29:
Moved issue to the cutdown repo

Closed 2022-11-29.

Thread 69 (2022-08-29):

Rotating Firmware Circular Buffer

jrleeman, 2022-08-29:
I thought we may need to implement a buffered setup for the rotating firmware. Turns out we didn't need it, but here is a draft incase it becomes useful. NOTE THIS STILL HAS AN IMU ERROR WE HAVE SINCE FIXED.

```c

/*
 * NSSL EFM Rotating Module Firmware
 *
 * This board and firmware read the electric field, temperature/humidity,
 * and orientation information and reports it via the fiber optic link to
 * the control paddle electronics.
 */

#include <Arduino.h>
#include <Wire.h>
#include "Adafruit_Sensor.h"
#include <Adafruit_LSM9DS1.h>
#include <Adafruit_BME280.h>
#include "ADS1220.h"
#include "pins.h"
#include "utility/imumaths.h"
#include <CircularBuffer.h>
//#include <SoftwareSerial.h>

#define CIRCULAR_BUFFER_INT_SAFE

struct DataPacket {
  uint8_t start_byte;
  uint32_t adc_millis;
  uint32_t adc;
  int16_t mag_x;
  int16_t mag_y;
  int16_t mag_z;
  int16_t gyro_x;
  int16_t gyro_y;
  int16_t gyro_z;
  int16_t acc_x;
  int16_t acc_y;
  int16_t acc_z;
  int16_t temperature;
  int16_t rel_hum;
  int16_t pressure;
  uint8_t end_byte;
};

Adafruit_BME280 bme;
Adafruit_LSM9DS1 lsm = Adafruit_LSM9DS1();
ADS1220 adc;
CircularBuffer<DataPacket, 40> DataBuffer;
//SoftwareSerial debugSerial(PB12, PB13); // RX, TX

volatile int16_t temperature;
volatile int16_t humidity;
volatile int16_t pressure;

void adc_isr()
{
  /*
   * ISR for the ADC DRDY pin
   */
  DataPacket dp;
  dp.adc_millis = millis();
  lsm.read(); // Read as close to millis as possible
  dp.start_byte = 0xBE;
  dp.adc = adc.readADC();
  dp.mag_x = (int16_t)lsm.magData.x;
  dp.mag_y = (int16_t)lsm.magData.y;
  dp.mag_z = (int16_t)lsm.magData.z;
  dp.acc_x = (int16_t)lsm.accelData.x;
  dp.acc_y = (int16_t)lsm.accelData.y;
  dp.acc_z = (int16_t)lsm.accelData.z;
  dp.gyro_x = (int16_t)lsm.gyroData.x;
  dp.gyro_y = (int16_t)lsm.gyroData.y;
  dp.gyro_z = (int16_t)lsm.gyroData.z;
  dp.temperature = temperature;
  dp.rel_hum = humidity;
  dp.pressure = pressure;
  dp.end_byte = 0xEF;
  DataBuffer.push(dp);
}

void setup()
{
  // Setup serial communications
  Serial.begin(38400);
  while(1)
  {
    Serial.println("HELLO WORLD!");
    delay(5);
  }
  //debugSerial.begin(19200);

  //debugSerial.println("NSSL Rotating Electronics");

  // Setup the IMU
  lsm.setupAccel(lsm.LSM9DS1_ACCELRANGE_4G);
  lsm.setupMag(lsm.LSM9DS1_MAGGAIN_4GAUSS);
  lsm.setupGyro(lsm.LSM9DS1_GYROSCALE_2000DPS);
  if(!lsm.begin())
  {
    //debugSerial.println("Error starting IMU.");
  }

  // Setup the Temperature/Humidity sensor
  if(!bme.begin(0x76, &Wire))
  {
    //debugSerial.println("Error starting BME280 sensor.");
  }

  // Setup the ADC
  adc.begin(PIN_ADC_CS, PIN_ADC_DRDY);
  // Set to normal operating mode
  adc.setOpMode(0);
  // Set to continuous conversion mode
  adc.setConversionMode(1);
  // Set to 20 Hz data rate
  adc.setDataRate(0x00);
  // Set 45 Hz data rate
  //adc.setDataRate(0x01);
  // Use the internal 2.048V reference
  adc.setVoltageRef(0);
  // Turn off the FIR filters
  adc.setFIR(0);
  // Set gain to 1 (000)
  adc.setGain(1);
  // AIN1 is positive signal, AIN2 is negative signal
  adc.setMultiplexer(0x03);
  // Disable the PGA
  adc.setPGAbypass(1);

  attachInterrupt(digitalPinToInterrupt(PIN_ADC_DRDY), adc_isr, FALLING);
}

void serialWrite32(uint32_t data)
{
  byte buf[4];
  buf[0] = data & 255;
  buf[1] = (data >> 8) & 255;
  buf[2] = (data >> 16) & 255;
  buf[3] = (data >> 24) & 255;
  Serial.write(buf, sizeof(buf));
}

void serialWriteint16(int16_t data)
{
  byte buf[2];
  buf[0] = data & 255;
  buf[1] = (data >> 8) & 255;
  Serial.write(buf, sizeof(buf));
}

void loop()
{
  static uint8_t loop_counter = 0;

  // Read the temperature or humidity - this is a very primitive scheduler that keeps things
  // fast enough that we can sample as fast as we want.
  if (loop_counter == 0)
  {
    humidity = (int16_t)bme.readHumidity();
  }

  if (loop_counter == 25)
  {
    pressure = (int16_t)(bme.readPressure() / 10);
  }

  if (loop_counter == 50)
  {
    temperature = (int16_t)(bme.readTemperature() * 10);
    //debugSerial.println(temperature);
    //debugSerial.println(bme.readTemperature());
  }

  loop_counter += 1;
  if (loop_counter == 100)
  {
    loop_counter = 0;
  }

  // Send data
  while (!DataBuffer.isEmpty())
  {
    DataPacket packet = DataBuffer.pop();

    // Thought this would work, but compiler optimization didn't help
    //Serial.write((byte*)&packet, sizeof(packet));

    Serial.write(packet.start_byte);
    serialWrite32(packet.adc_millis);
    serialWrite32(packet.adc);
    serialWriteint16(packet.mag_x);
    serialWriteint16(packet.mag_y);
    serialWriteint16(packet.mag_z);
    serialWriteint16(packet.gyro_x);
    serialWriteint16(packet.gyro_y);
    serialWriteint16(packet.gyro_z);
    serialWriteint16(packet.acc_x);
    serialWriteint16(packet.acc_y);
    serialWriteint16(packet.acc_z);
    serialWriteint16(packet.temperature);
    serialWriteint16(packet.rel_hum);
    serialWriteint16(packet.pressure);
    Serial.write(packet.end_byte);
  }
}

```

Closed 2022-08-29.

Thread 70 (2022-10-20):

Tracker PCB Crystal

Jdbailey7, 2022-10-20:
Schematic IPN Is correct but the Ibom is incorrect

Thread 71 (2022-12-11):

Coordinate convention for IMU

deeplycloudy, 2022-12-11:
The LSM9DS1 has a right-handed convention for the magnetometer coordinate system and left-handed for the accelerometer and gyro. This results in x pointing in different directions, while
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

If I’m locating pin one correctly, it looks like -y always points to the top of the card for all three sensors.
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

Is this common to all IMUs? I’d like to put the right cautionary language in the signal processing code should the IMU change some day.

Suggest noting these facts in the readme or another doc location.

jrleeman, 2023-01-08:
Based on other IMU datasheets (I just picked a few) I don't think it is universal. It appears to be pseudo-random. Goodie.

## BNO08X
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

## ISM330DHCX, MMC5983MA Combo
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

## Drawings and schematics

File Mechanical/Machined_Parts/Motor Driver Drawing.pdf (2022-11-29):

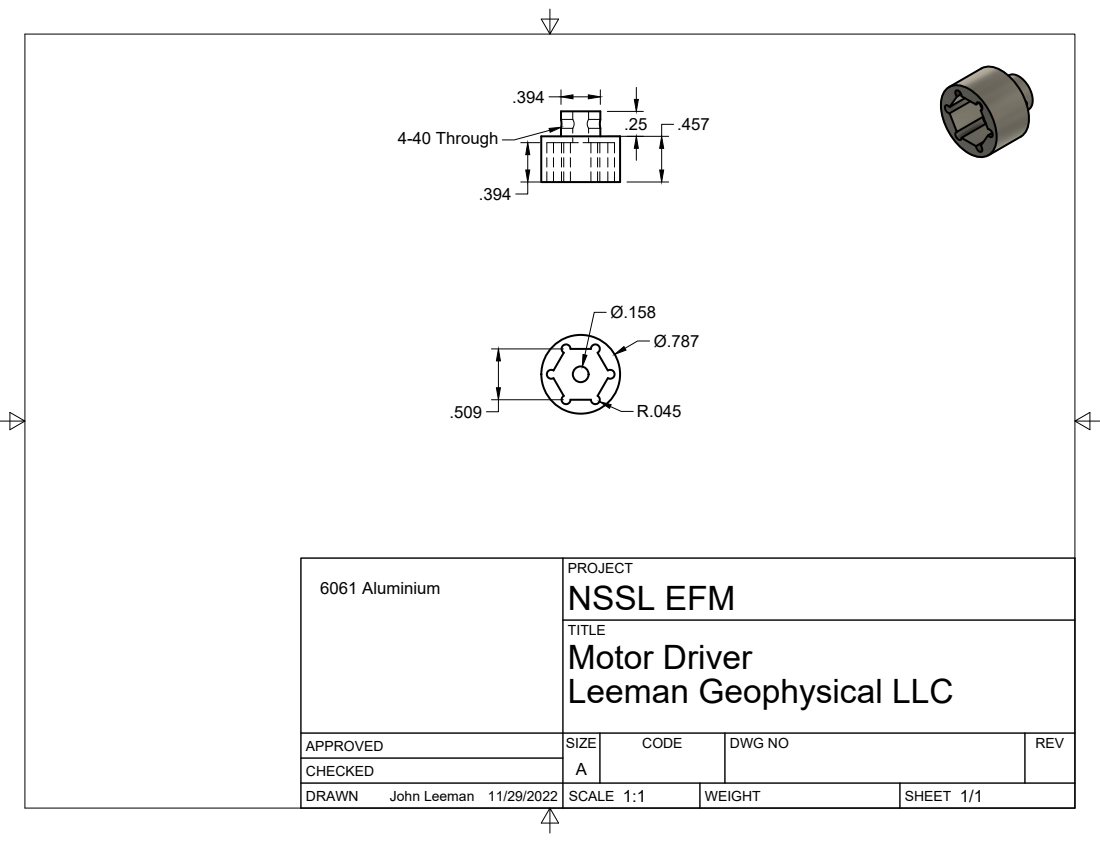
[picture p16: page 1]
SIZE; CODE; DWG NO; REV; John Leeman 11/29/2022; 6061 Aluminium; 4-40 Through

PROJECT
NSSL EFM
Motor Driver
Leeman Geophysical LLC

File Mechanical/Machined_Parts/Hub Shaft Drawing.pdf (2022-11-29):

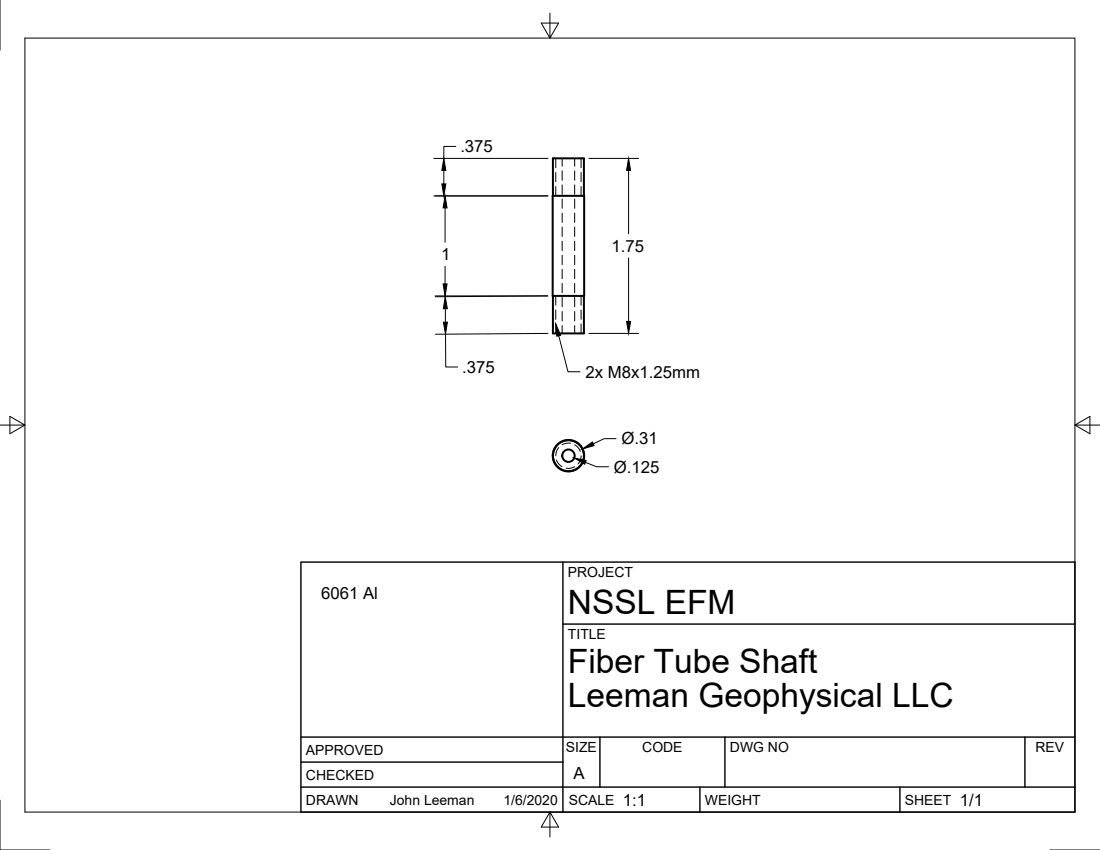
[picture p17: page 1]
SIZE; CODE; DWG NO; REV; John Leeman

PROJECT
NSSL EFM
Fiber Tube Shaft
Leeman Geophysical LLC

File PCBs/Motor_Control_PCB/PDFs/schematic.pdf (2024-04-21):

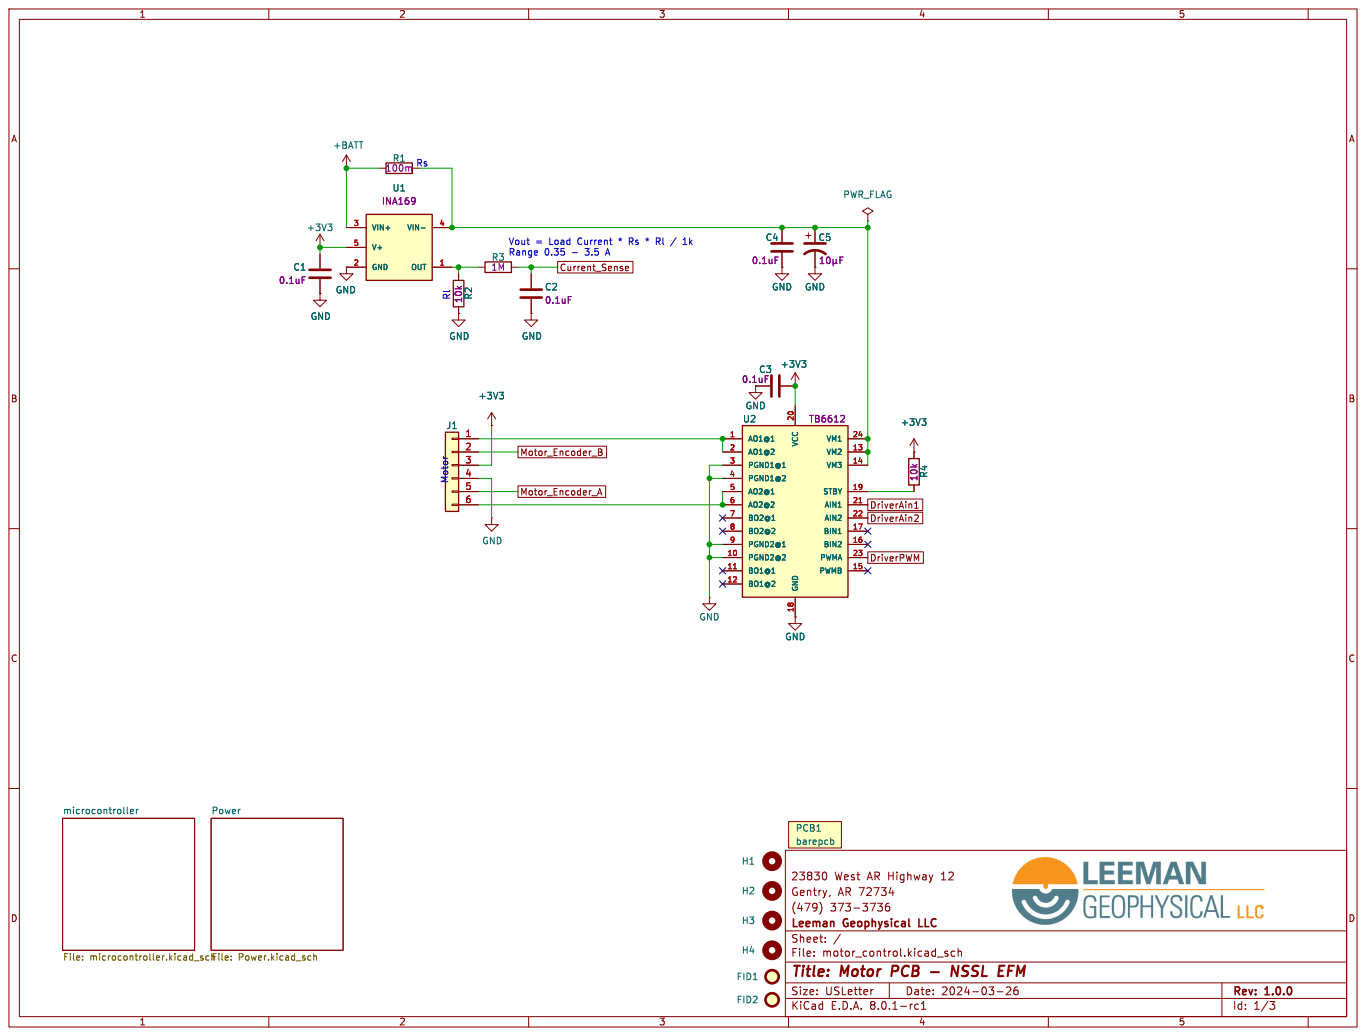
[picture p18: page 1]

Id: 1/3 Title: Motor PCB - NSSL EFM

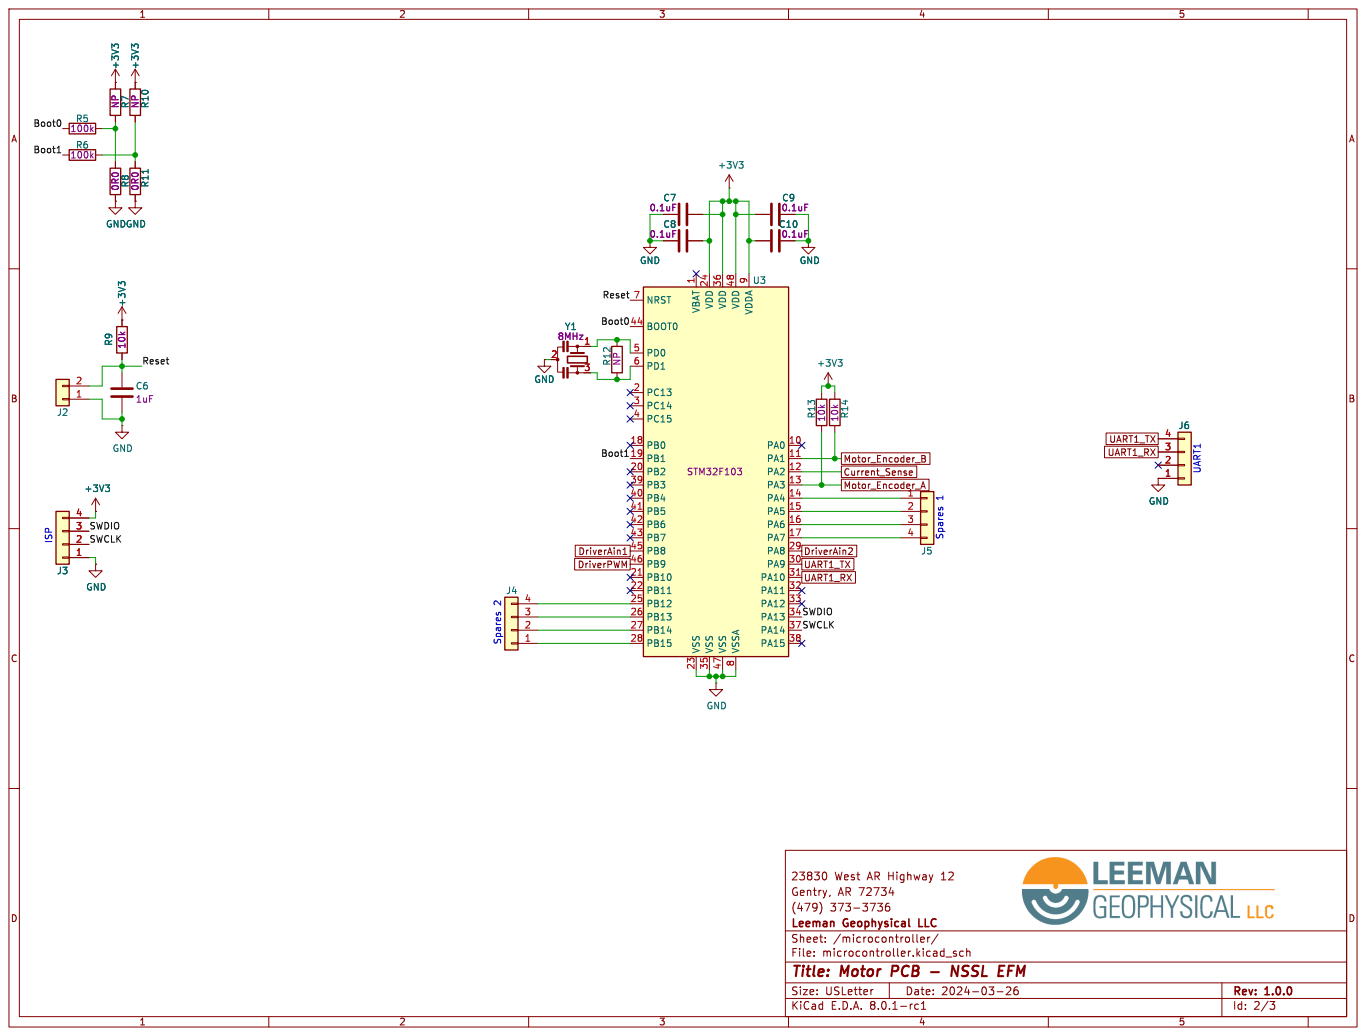
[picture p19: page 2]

Id: 2/3 Title: Motor PCB - NSSL EFM

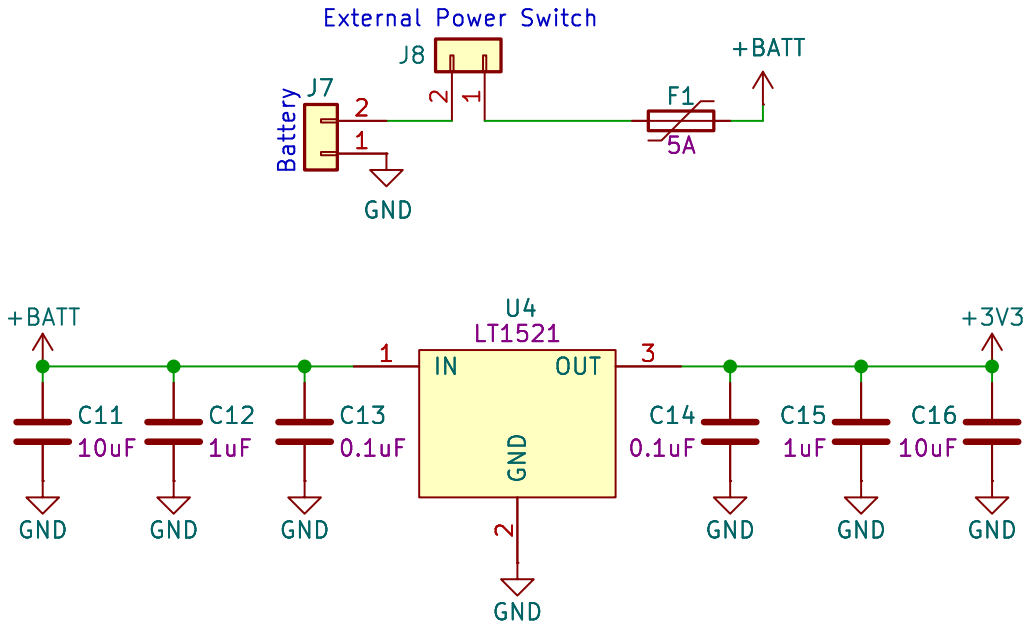
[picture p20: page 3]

0.1uF External Power Switch Battery C11

Id: 3/3 Title: Motor PCB - NSSL EFM

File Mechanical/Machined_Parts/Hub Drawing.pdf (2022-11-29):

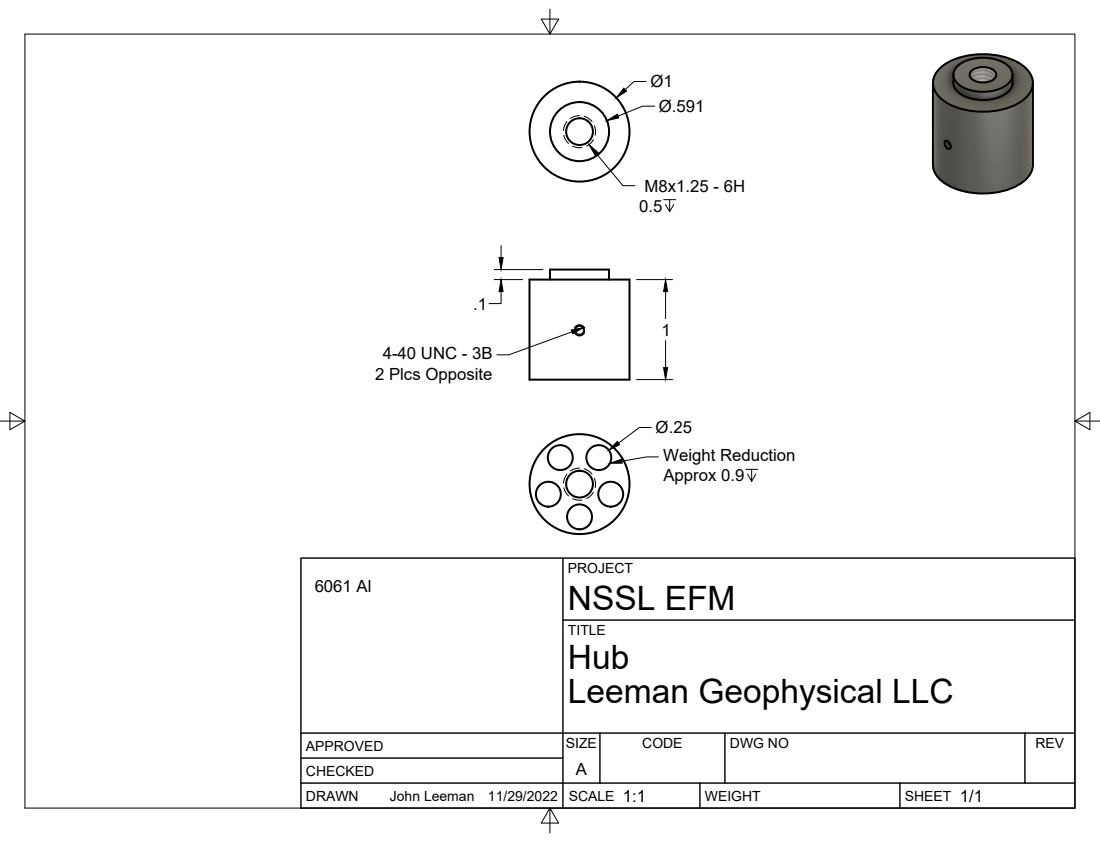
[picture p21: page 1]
SIZE; CODE; DWG NO; REV; John Leeman 11/29/2022; Weight Reduction Approx 0.9; 4-40 UNC - 3B 2 Plcs Opposite

PROJECT
NSSL EFM
Hub
Leeman Geophysical LLC

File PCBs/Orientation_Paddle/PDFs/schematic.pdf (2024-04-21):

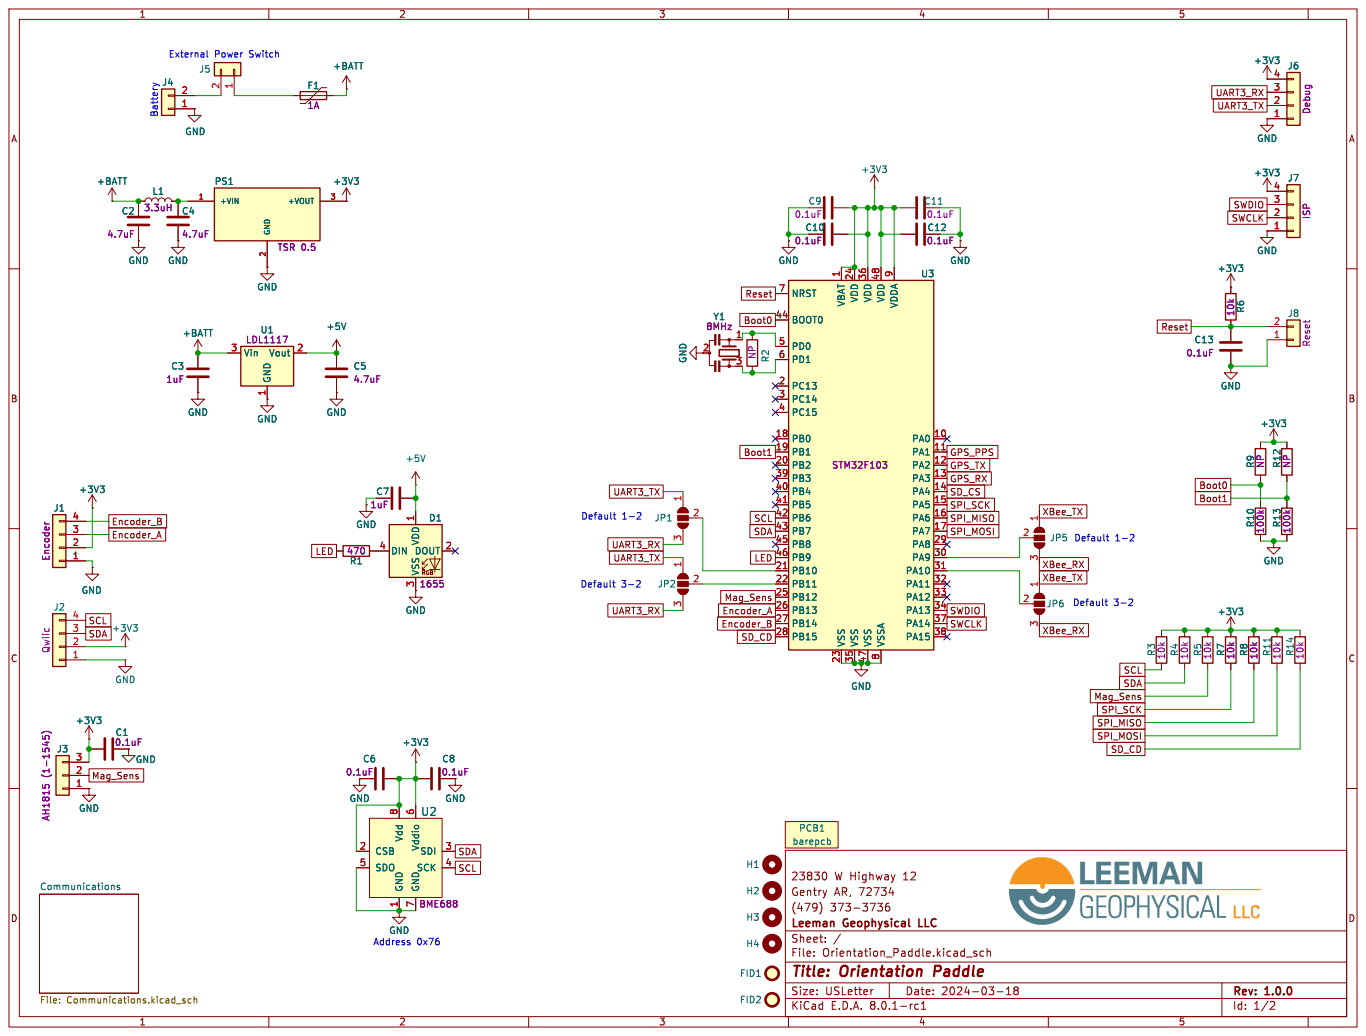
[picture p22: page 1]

1 PA0 10 PA1 11 PA2 12 PA3 13 PA4 14 PA5 15 PA6 16 PA7 17 PB0 18 PB1 19 PC13 2 PB2 20 PB10 21 PB11 22 VSS 23 VDD 24 PB12 25 PB13 26 PB14 27 PB15 28 PA8 29 PC14 3 PA9 30 PA10 31 PA11 32 PA12 33 PA13 34 VSS 35 VDD 36 PA14 37 PA15 38 PB3 39 PC15 4 PB4 40 PB5 41 PB6 42 PB7 43 BOOT0 44 PB8 45 PB9 46 VSS 47 VDD 48 PD0 5 PD1 6 NRST 7 VSSA

1 CSB 2 SDI 3 SCK 4 SDO 5 Vddio

Id: 1/2 Title: Orientation Paddle

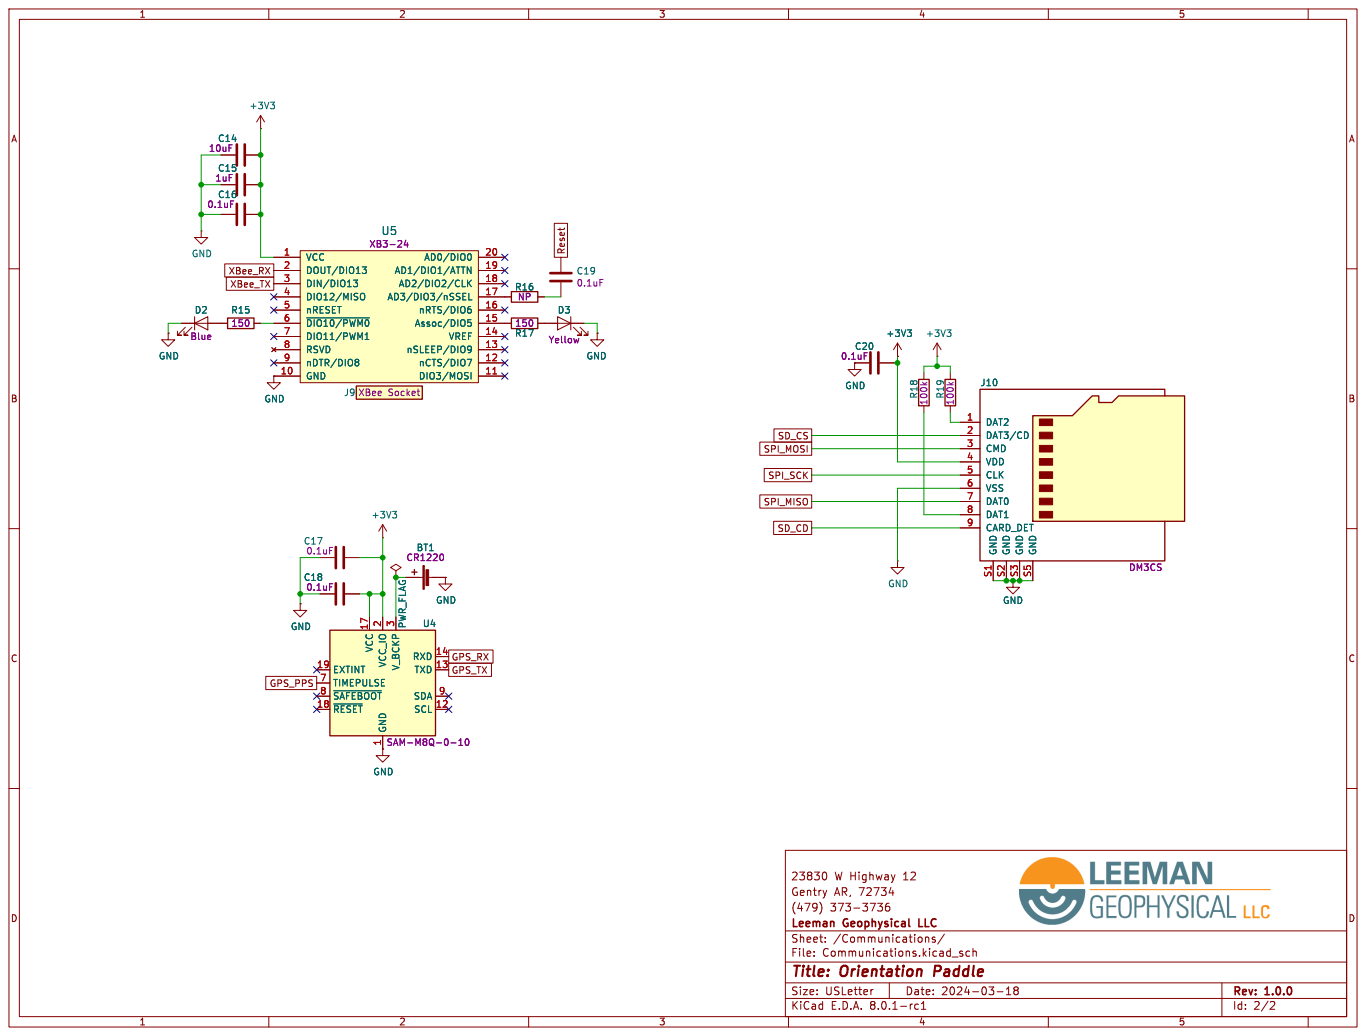
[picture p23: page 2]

Id: 2/2 Title: Orientation Paddle

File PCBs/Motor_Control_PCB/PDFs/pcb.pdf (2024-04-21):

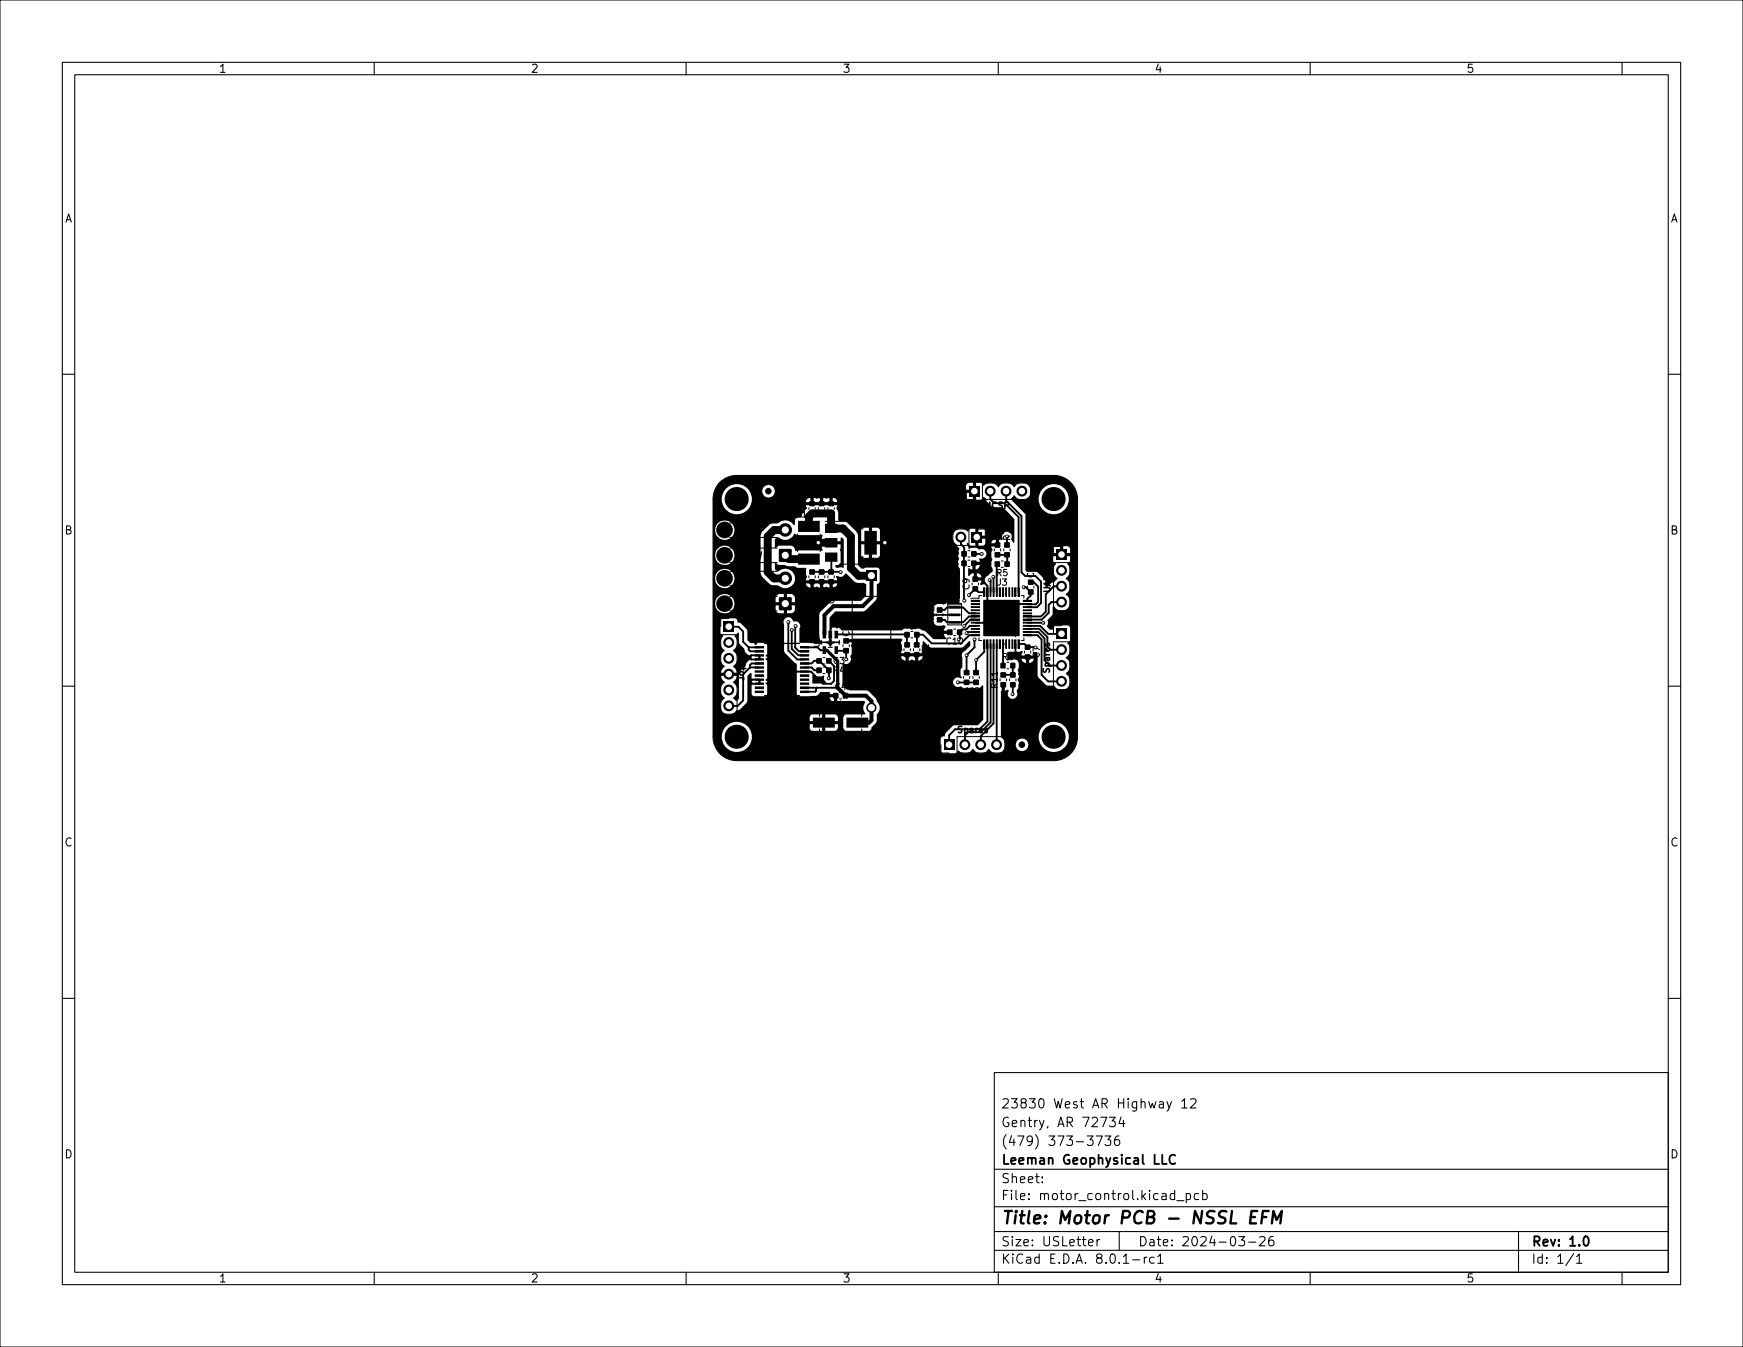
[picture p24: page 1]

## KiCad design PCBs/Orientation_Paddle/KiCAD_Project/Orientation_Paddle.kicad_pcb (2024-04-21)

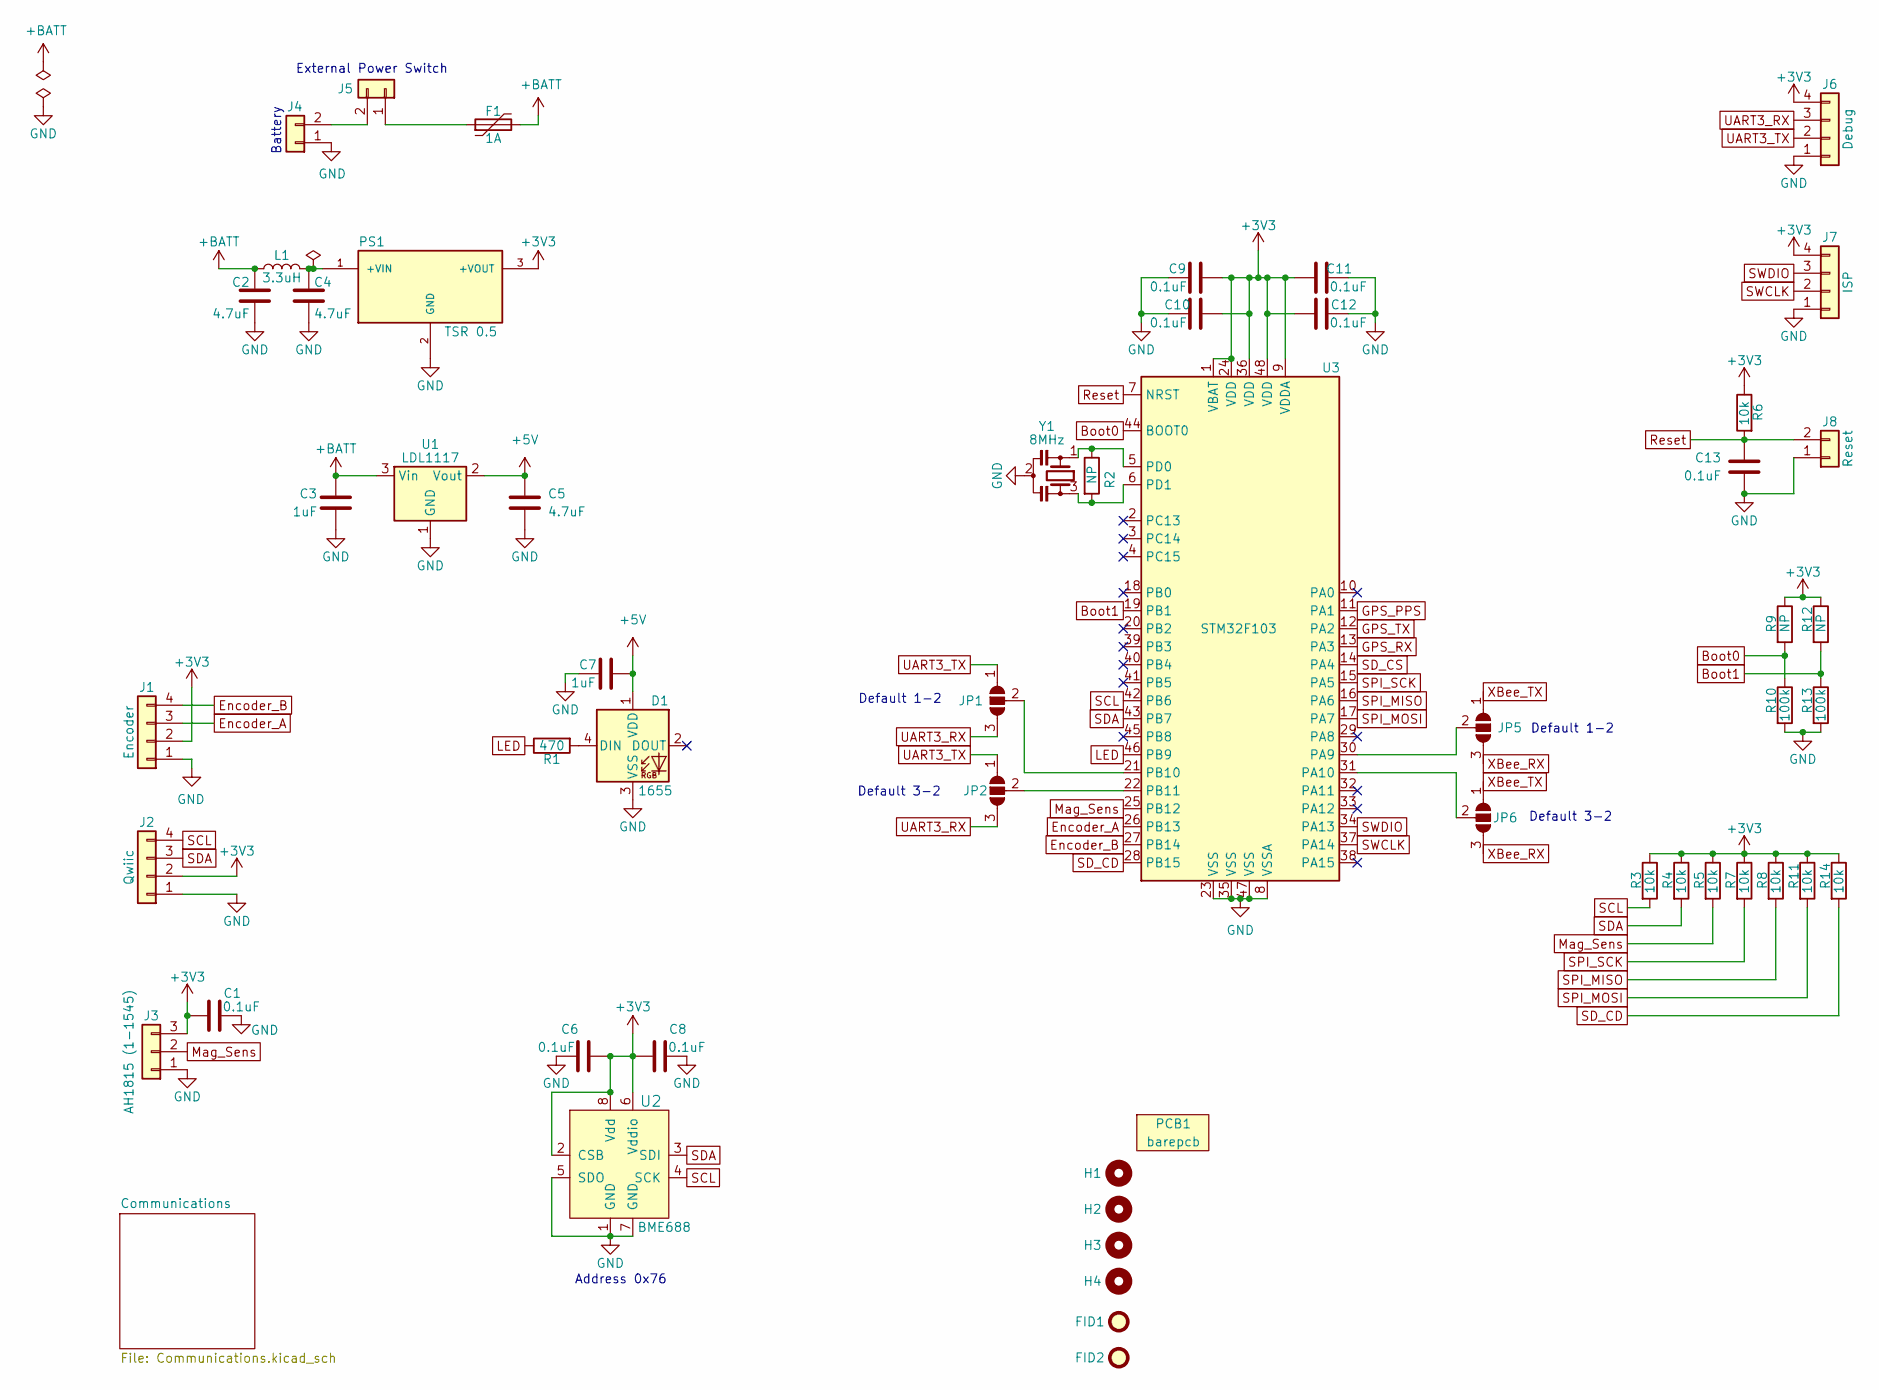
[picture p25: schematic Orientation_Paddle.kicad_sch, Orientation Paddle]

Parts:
C1, C6, C8, C9, C10, C11, C12, C13: 1-0000007
C2, C4: 1-0000136
C3, C7: 1-0000018
C5: 1-0000019
D1: 1-0000399
F1: 1-0001517
FID1, FID2: Fiducial_1mm_2mm; Fiducial_1mm_Mask2mm
H1, H2, H3, H4: Imperial6; MountingHole_imperial6
J1: NP_Conn_01x04_Relief; SolderWire_1x04_Relief
J2: 1-0001205
J3: NP_Conn_01x03_Relief; SolderWire_1x03_Relief
J4, J5: NP_Conn_01x02_Relief; SolderWire_1x02_Relief
J6, J7: NP_Conn_01x04; PinHeader_1x04_P2.54mm_Vertical
J8: NP_Conn_01x02; PinHeader_1x02_P2.54mm_Vertical
JP1, JP2, JP5, JP6: SolderJumper_3_Open; SolderJumper-3_P1.3mm_Open_RoundedPad1.0x1.5mm_NumberLabels
L1: 1-0000931
PCB1: barepcb
PS1: 1-0000727
R1: 1-0000679
R2: 1-0000009
R3, R4, R5, R6, R7, R8, R11, R14: 1-0000010
R9, R12: 1-0000006
R10, R13: 1-0000174
U1: 1-0001232
U2: 1-0001471
U3: 1-0000207
Y1: 1-0000721

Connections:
+3V3: C1.1, C6.2, C8.1, C9.1, C10.1, C11.1, C12.1, J1.2, J2.2, J3.3, J6.4, J7.4, PS1.3 (+VOUT), R3.1, R4.1, R5.1, R6.1, R7.1, R8.1, R9.1, R11.1, R12.1, R14.1, U2.2 (CSB), U2.6 (Vddio), U2.8 (Vdd), U3.1 (VBAT), U3.9 (VDDA), U3.24 (VDD), U3.36 (VDD), U3.48 (VDD); also elsewhere on the board
+5V: C5.1, C7.1, D1.1 (VDD), U1.2 (Vout)
+BATT: C2.1, C3.1, F1.2, L1.1, U1.3 (Vin)
Boot0: R9.2, R10.1, U3.44 (BOOT0)
Boot1: R12.2, R13.1, U3.19 (PB1)
Encoder_A: J1.3, U3.26 (PB13)
Encoder_B: J1.4, U3.27 (PB14)
GND: C1.2, C2.2, C3.2, C4.2, C5.2, C6.1, C7.2, C8.2, C9.2, C10.2, C11.2, C12.2, C13.2, D1.3 (VSS), J1.1, J2.1, J3.1, J4.1, J6.1, J7.1, J8.1, PS1.2 (GND), R10.2, R13.2, U1.1 (GND), U2.1 (GND), U2.5 (SDO), U2.7 (GND), U3.8 (VSSA), U3.23 (VSS), U3.35 (VSS), U3.47 (VSS), Y1.2; also elsewhere on the board
GPS_PPS: U3.11 (PA1); also elsewhere on the board
GPS_RX: U3.13 (PA3); also elsewhere on the board
GPS_TX: U3.12 (PA2); also elsewhere on the board
LED: R1.1, U3.46 (PB9)
Mag_Sens: J3.2, R5.2, U3.25 (PB12)
unnamed: D1.4 (DIN), R1.2
unnamed: J4.2, J5.2
unnamed: F1.1, J5.1
unnamed: JP1.2 (C), U3.21 (PB10)
unnamed: JP2.2 (C), U3.22 (PB11)
unnamed: JP5.2 (C), U3.30 (PA9)
unnamed: JP6.2 (C), U3.31 (PA10)
unnamed: C4.1, L1.2, PS1.1 (+VIN)
unnamed: R2.1, U3.5 (PD0), Y1.1
unnamed: R2.2, U3.6 (PD1), Y1.3
Reset: C13.1, J8.2, R6.2, U3.7 (NRST); also elsewhere on the board
SCL: J2.4, R3.2, U2.4 (SCK), U3.42 (PB6)
SDA: J2.3, R4.2, U2.3 (SDI), U3.43 (PB7)
SD_CD: R14.2, U3.28 (PB15); also elsewhere on the board
SD_CS: U3.14 (PA4); also elsewhere on the board
SPI_MISO: R8.2, U3.16 (PA6); also elsewhere on the board
SPI_MOSI: R11.2, U3.17 (PA7); also elsewhere on the board
SPI_SCK: R7.2, U3.15 (PA5); also elsewhere on the board
SWCLK: J7.2, U3.37 (PA14)
SWDIO: J7.3, U3.34 (PA13)
UART3_RX: J6.3, JP1.3 (B), JP2.3 (B)
UART3_TX: J6.2, JP1.1 (A), JP2.1 (A)
XBee_RX: JP5.3 (B), JP6.3 (B); also elsewhere on the board
XBee_TX: JP5.1 (A), JP6.1 (A); also elsewhere on the board

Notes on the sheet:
Default 1-2
Battery
Address 0x76
External Power Switch
Default 3-2

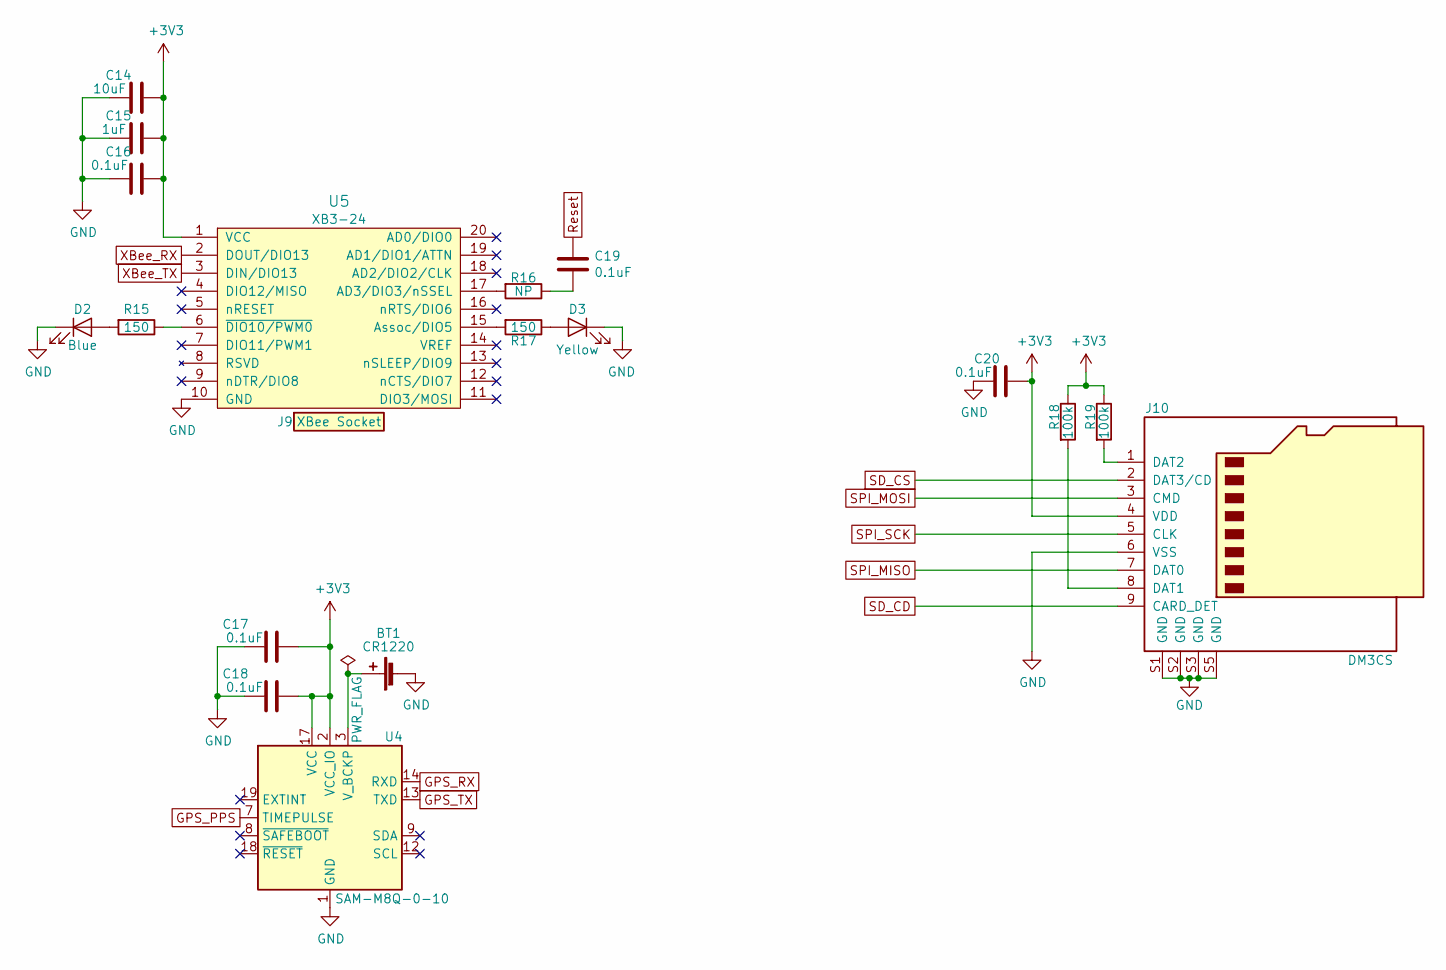
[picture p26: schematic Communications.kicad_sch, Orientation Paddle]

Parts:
BT1: 1-0000246
C14: 1-0000075
C15: 1-0000018
C16, C17, C18, C19, C20: 1-0000007
D2: 1-0000599
D3: 1-0000601
J9: 1-0000050
J10: 1-0000190
R15, R17: 1-0000008
R16: 1-0000006
R18, R19: 1-0000174
U4: 1-0000446
U5: 1-0000785

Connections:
+3V3: C14.1, C15.1, C16.1, C17.1, C18.1, C20.2, J10.4 (VDD), R18.1, R19.1, U4.2 (VCC_IO), U4.17 (VCC), U5.1 (VCC); also elsewhere on the board
GND: BT1.2 (-), C14.2, C15.2, C16.2, C17.2, C18.2, C20.1, D2.1 (K), D3.1 (K), J10.6 (VSS), J10.S1 (GND), J10.S2 (GND), J10.S3 (GND), J10.S5 (GND), U4.1 (GND), U4.4 (GND), U4.5 (GND), U4.6 (GND), U4.10 (GND), U4.11 (GND), U4.15 (GND), U4.16 (GND), U4.20 (GND), U5.10 (GND); also elsewhere on the board
GPS_PPS: U4.7 (TIMEPULSE); also elsewhere on the board
GPS_RX: U4.14 (RXD); also elsewhere on the board
GPS_TX: U4.13 (TXD); also elsewhere on the board
unnamed: BT1.1 (+), U4.3 (V_BCKP)
unnamed: C19.2, R16.1
unnamed: D2.2 (A), R15.2
unnamed: D3.2 (A), R17.1
unnamed: J10.8 (DAT1), R18.2
unnamed: J10.1 (DAT2), R19.2
unnamed: R16.2, U5.17 (AD3/DIO3/nSSEL)
unnamed: R17.2, U5.15 (Assoc/DIO5)
unnamed: R15.1, U5.6 (~DIO10/PWM0)
Reset: C19.1; also elsewhere on the board
SD_CD: J10.9 (CARD_DET); also elsewhere on the board
SD_CS: J10.2 (DAT3/CD); also elsewhere on the board
SPI_MISO: J10.7 (DAT0); also elsewhere on the board
SPI_MOSI: J10.3 (CMD); also elsewhere on the board
SPI_SCK: J10.5 (CLK); also elsewhere on the board
XBee_RX: U5.2 (DOUT/DIO13); also elsewhere on the board
XBee_TX: U5.3 (DIN/DIO13); also elsewhere on the board

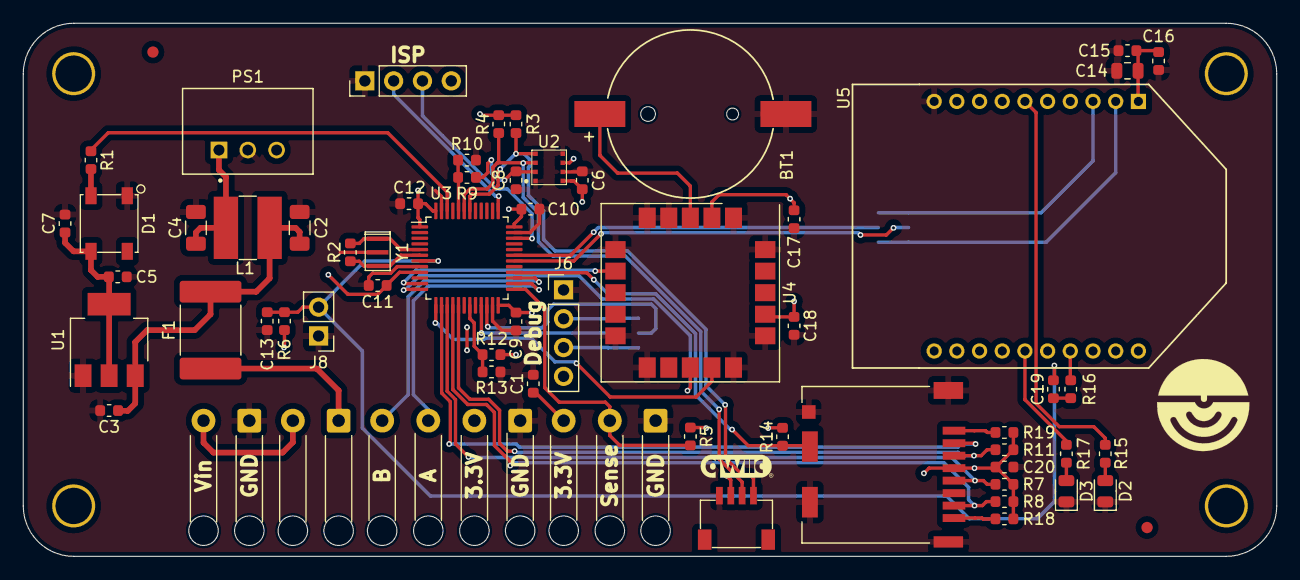
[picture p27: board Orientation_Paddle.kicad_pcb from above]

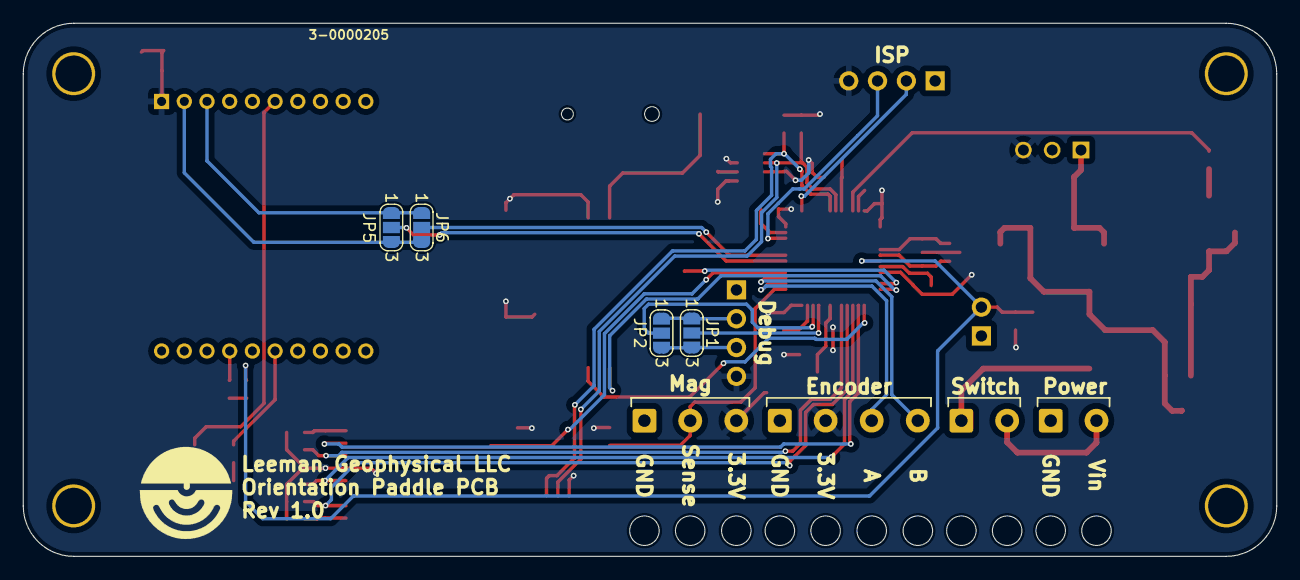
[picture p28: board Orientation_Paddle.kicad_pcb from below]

Board: 2 copper layers, 110.5 x 47.0 mm, 73 parts (4 on the bottom side), 46 nets.

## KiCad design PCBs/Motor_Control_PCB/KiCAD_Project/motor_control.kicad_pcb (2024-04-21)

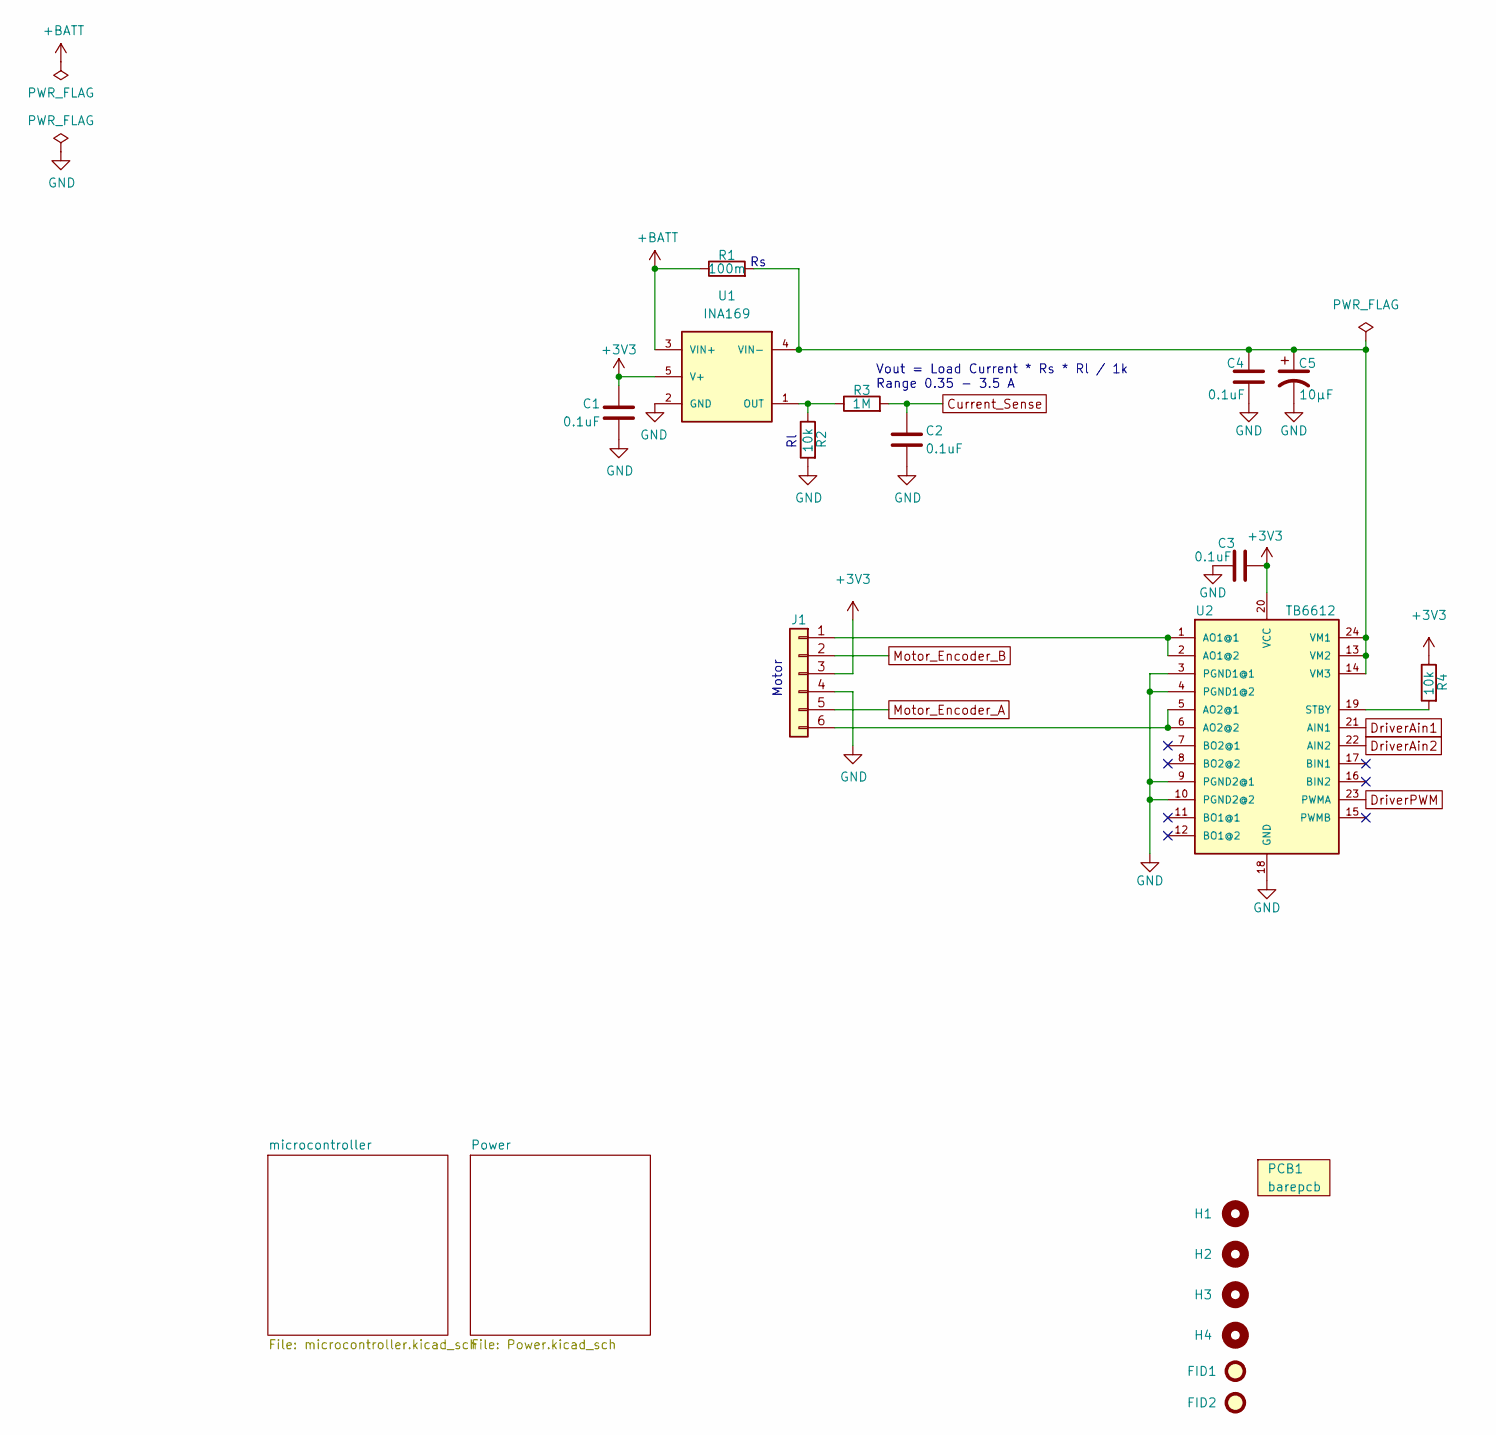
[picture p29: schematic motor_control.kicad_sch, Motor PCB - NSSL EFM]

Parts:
C1, C2, C3, C4: 1-0000007
C5: 1-0000176
FID1, FID2: Fiducial_1mm_2mm; Fiducial_1mm_Mask2mm
H1, H2, H3, H4: Imperial4; MountingHole_imperial4
J1: NP_Conn_01x06; PinHeader_1x06_P2.54mm_Vertical
PCB1: barepcb
R1: 1-0001546
R2, R4: 1-0000010
R3: 1-0000009
U1: 1-0000452
U2: 1-0001532

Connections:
+3V3: C1.1, C3.2, J1.3, R4.1, U1.5 (V+), U2.20 (VCC); also elsewhere on the board
+BATT: R1.1, U1.3 (VIN+); also elsewhere on the board
Current_Sense: C2.1, R3.2; also elsewhere on the board
DriverAin1: U2.21 (AIN1); also elsewhere on the board
DriverAin2: U2.22 (AIN2); also elsewhere on the board
DriverPWM: U2.23 (PWMA); also elsewhere on the board
GND: C1.2, C2.2, C3.1, C4.1, C5.2, J1.4, R2.2, U1.2 (GND), U2.3 (PGND1@1), U2.4 (PGND1@2), U2.9 (PGND2@1), U2.10 (PGND2@2), U2.18 (GND); also elsewhere on the board
Motor_Encoder_A: J1.5; also elsewhere on the board
Motor_Encoder_B: J1.2; also elsewhere on the board
unnamed: J1.1, U2.1 (AO1@1), U2.2 (AO1@2)
unnamed: J1.6, U2.5 (AO2@1), U2.6 (AO2@2)
unnamed: R2.1, R3.1, U1.1 (OUT)
unnamed: C4.2, C5.1, R1.2, U1.4 (VIN-), U2.13 (VM2), U2.14 (VM3), U2.24 (VM1)
unnamed: R4.2, U2.19 (STBY)

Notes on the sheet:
Motor
Vout = Load Current * Rs * Rl / 1k Range 0.35 - 3.5 A

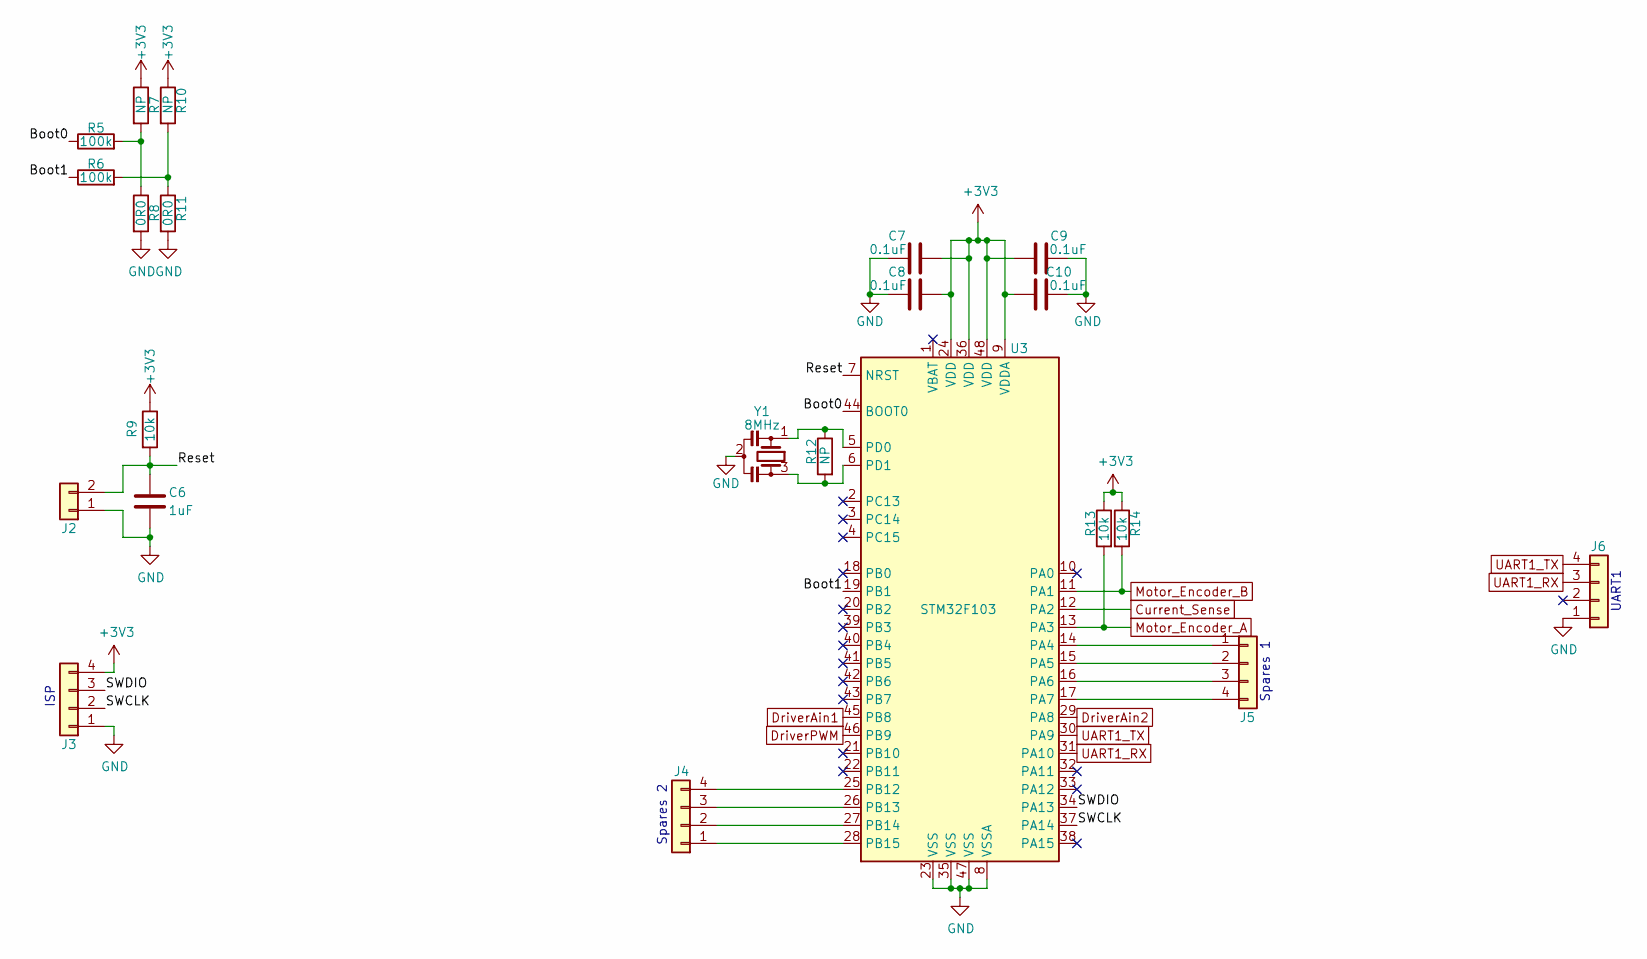
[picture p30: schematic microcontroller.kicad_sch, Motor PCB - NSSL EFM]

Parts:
C6: 1-0000018
C7, C8, C9, C10: 1-0000007
J2: NP_Conn_01x02; PinHeader_1x02_P2.54mm_Vertical
J3, J4, J5, J6: NP_Conn_01x04; PinHeader_1x04_P2.54mm_Vertical
R5, R6: 1-0000174
R7, R8, R10, R11, R12: 1-0000006
R9, R13, R14: 1-0000010
U3: 1-0000207
Y1: 1-0000721

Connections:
+3V3: C7.1, C8.1, C9.1, C10.1, J3.4, R7.1, R9.1, R10.1, R13.1, R14.1, U3.9 (VDDA), U3.24 (VDD), U3.36 (VDD), U3.48 (VDD); also elsewhere on the board
/microcontroller/Boot0: R5.1, U3.44 (BOOT0)
/microcontroller/Boot1: R6.1, U3.19 (PB1)
/microcontroller/Reset: C6.1, J2.2, R9.2, U3.7 (NRST)
/microcontroller/SWCLK: J3.2, U3.37 (PA14)
/microcontroller/SWDIO: J3.3, U3.34 (PA13)
Current_Sense: U3.12 (PA2); also elsewhere on the board
DriverAin1: U3.45 (PB8); also elsewhere on the board
DriverAin2: U3.29 (PA8); also elsewhere on the board
DriverPWM: U3.46 (PB9); also elsewhere on the board
GND: C6.2, C7.2, C8.2, C9.2, C10.2, J2.1, J3.1, J6.1, R8.2, R11.2, U3.8 (VSSA), U3.23 (VSS), U3.35 (VSS), U3.47 (VSS), Y1.2; also elsewhere on the board
Motor_Encoder_A: R13.2, U3.13 (PA3); also elsewhere on the board
Motor_Encoder_B: R14.2, U3.11 (PA1); also elsewhere on the board
unnamed: J4.1, U3.28 (PB15)
unnamed: J4.2, U3.27 (PB14)
unnamed: J4.3, U3.26 (PB13)
unnamed: J4.4, U3.25 (PB12)
unnamed: J5.1, U3.14 (PA4)
unnamed: J5.2, U3.15 (PA5)
unnamed: J5.3, U3.16 (PA6)
unnamed: J5.4, U3.17 (PA7)
unnamed: R5.2, R7.2, R8.1
unnamed: R6.2, R10.2, R11.1
unnamed: R12.1, U3.5 (PD0), Y1.1
unnamed: R12.2, U3.6 (PD1), Y1.3
UART1_RX: J6.3, U3.31 (PA10)
UART1_TX: J6.4, U3.30 (PA9)

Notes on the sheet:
Spares 1
UART1
Spares 2
ISP

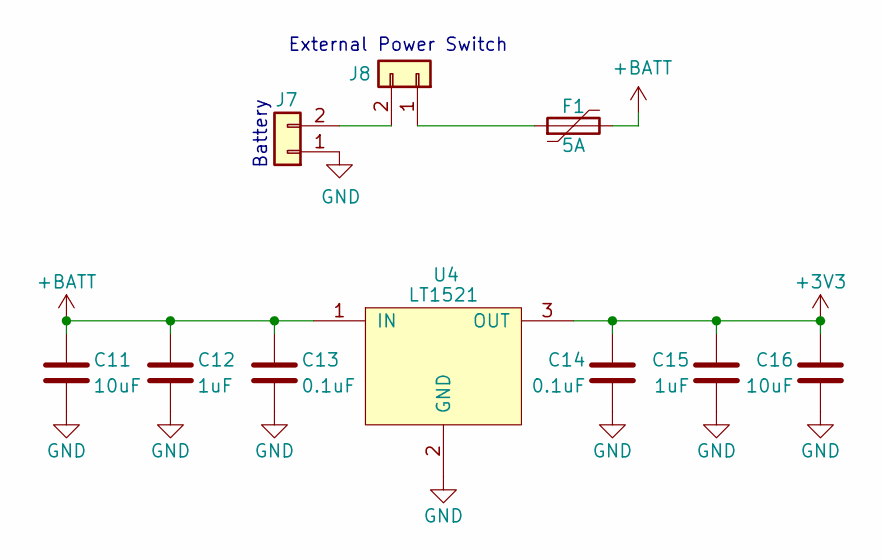
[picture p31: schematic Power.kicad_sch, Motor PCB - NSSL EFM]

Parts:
C11, C16: 1-0000005
C12, C15: 1-0000018
C13, C14: 1-0000007
F1: 1-0001547
J7, J8: NP_Conn_01x02_Relief; SolderWire_1x02_Relief
U4: 1-0000196

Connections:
+3V3: C14.1, C15.1, C16.1, U4.3 (OUT); also elsewhere on the board
+BATT: C11.1, C12.1, C13.1, F1.2, U4.1 (IN); also elsewhere on the board
GND: C11.2, C12.2, C13.2, C14.2, C15.2, C16.2, J7.1, U4.2 (GND); also elsewhere on the board
unnamed: J7.2, J8.2
unnamed: F1.1, J8.1

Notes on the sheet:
Battery
External Power Switch

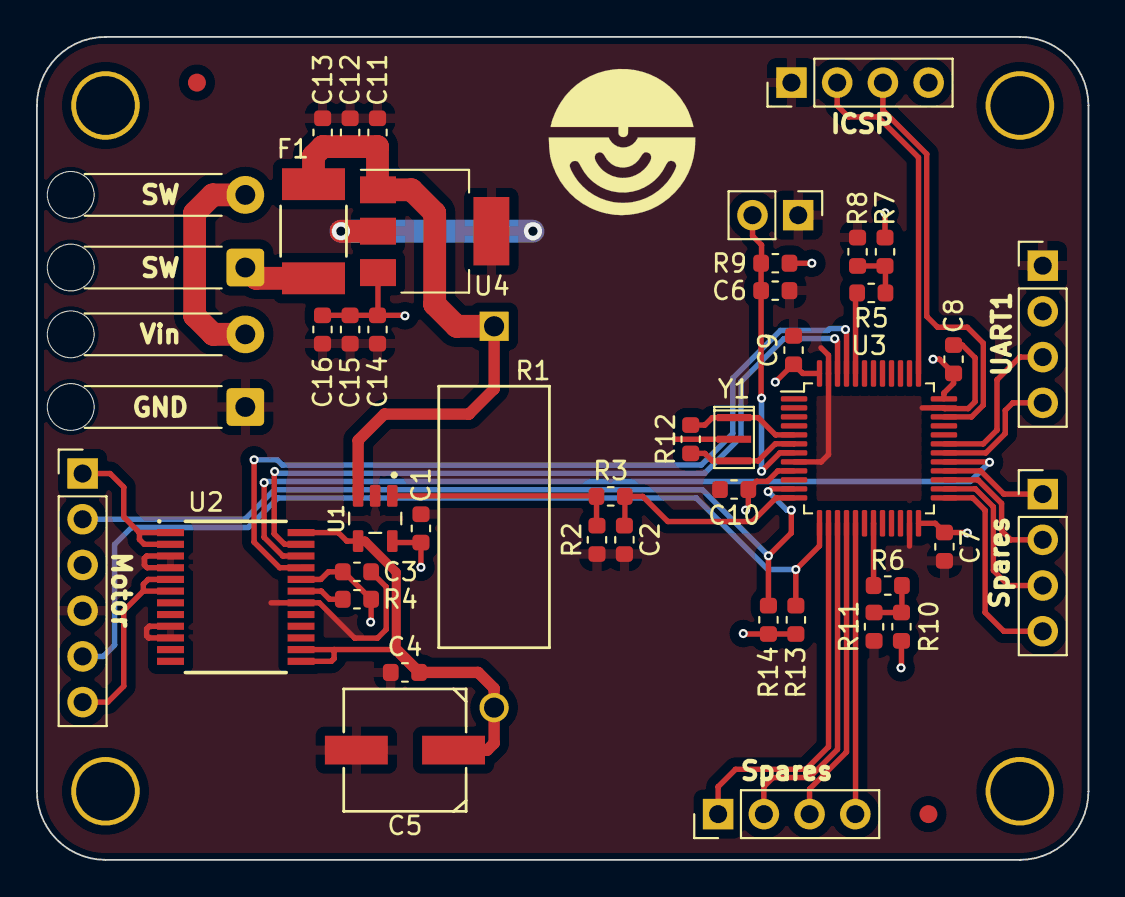
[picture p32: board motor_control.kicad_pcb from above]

Board: 4 copper layers, 58.4 x 45.7 mm, 51 parts (0 on the bottom side), 35 nets.

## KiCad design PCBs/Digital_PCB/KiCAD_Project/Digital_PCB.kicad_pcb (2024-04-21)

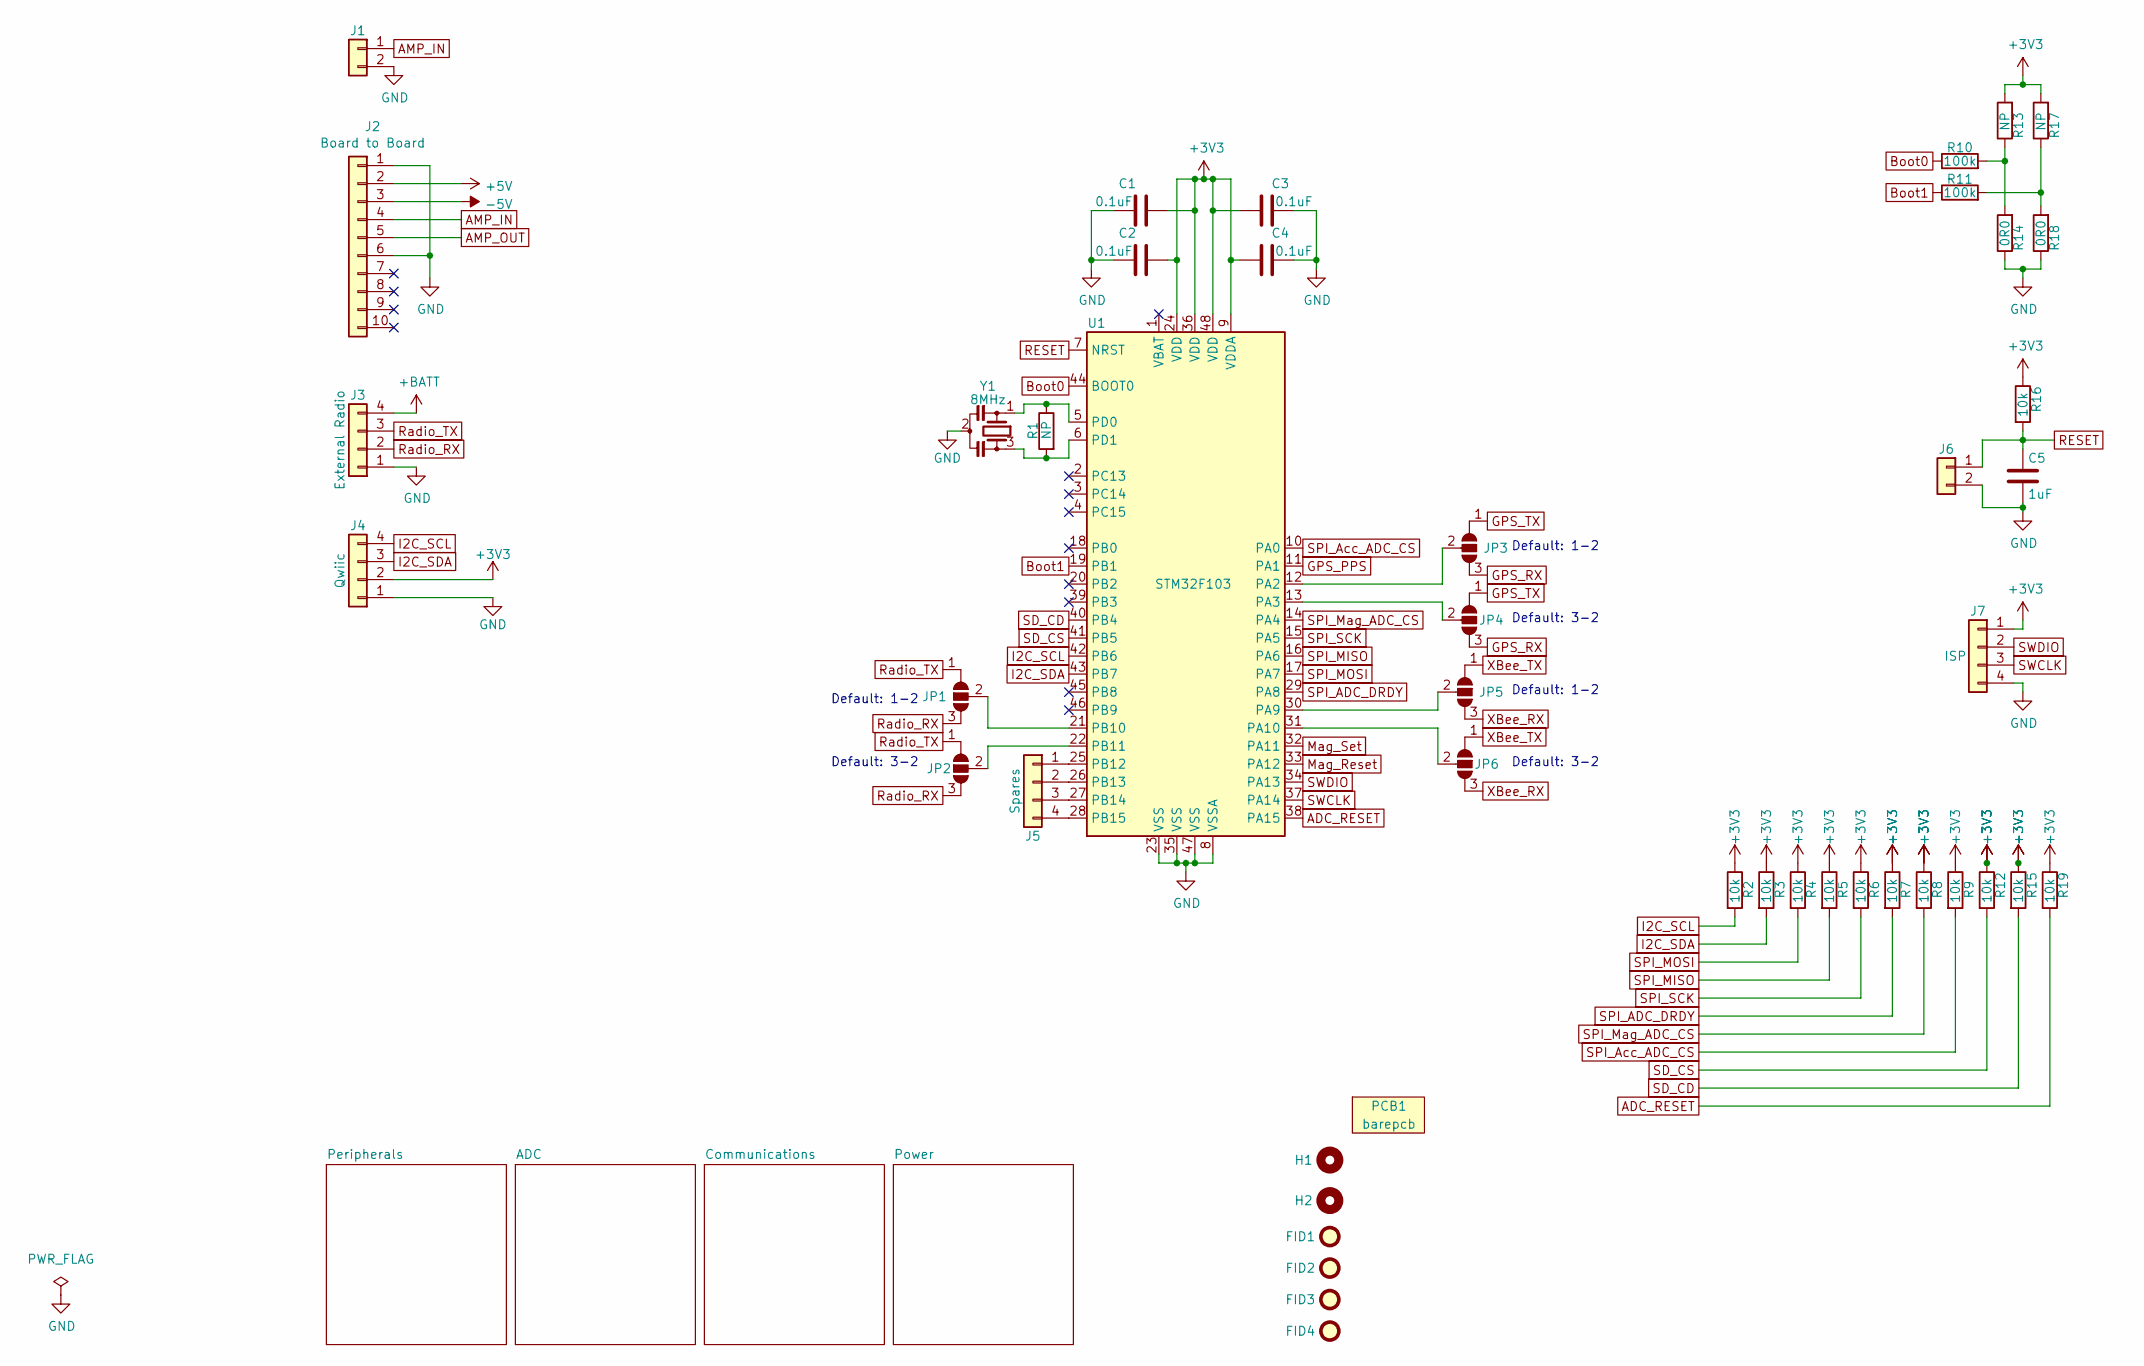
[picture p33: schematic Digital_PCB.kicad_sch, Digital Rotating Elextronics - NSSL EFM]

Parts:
C1, C2, C3, C4: 1-0000007
C5: 1-0000018
FID1, FID2, FID3, FID4: Fiducial_1mm_2mm; Fiducial_1mm_Mask2mm
H1, H2: Imperial6; MountingHole_imperial6
J1: NP_Conn_01x02_Relief; SolderWire_1x02_Relief
J2: Board to Board; PinHeader_1x10_P2.54mm_Vertical
J3: NP_Conn_01x04_Relief; SolderWire_1x04_Relief
J4: 1-0001205
J5, J7: NP_Conn_01x04; PinHeader_1x04_P2.54mm_Vertical
J6: NP_Conn_01x02_Relief; PinHeader_1x02_P2.54mm_Vertical
JP1, JP2, JP3, JP4, JP5, JP6: SolderJumper_3_Open; SolderJumper-3_P1.3mm_Open_RoundedPad1.0x1.5mm_NumberLabels
PCB1: barepcb
R1, R13, R14, R17, R18: 1-0000006
R2, R3, R4, R5, R6, R7, R8, R9, R12, R15, R16, R19: 1-0000010
R10, R11: 1-0000174
U1: 1-0000207
Y1: 1-0000721

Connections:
+3V3: C1.2, C2.2, C3.2, C4.2, J4.2, J7.1, R2.1, R3.1, R4.1, R5.1, R6.1, R7.1, R8.1, R9.1, R12.1, R13.2, R15.1, R16.1, R17.2, R19.1, U1.9 (VDDA), U1.24 (VDD), U1.36 (VDD), U1.48 (VDD); also elsewhere on the board
+5V: J2.2; also elsewhere on the board
+BATT: J3.4; also elsewhere on the board
-5V: J2.3; also elsewhere on the board
ADC_RESET: R19.2, U1.38 (PA15); also elsewhere on the board
AMP_IN: J1.1, J2.4
AMP_OUT: J2.5; also elsewhere on the board
Boot0: R10.1, U1.44 (BOOT0)
Boot1: R11.1, U1.19 (PB1)
GND: C1.1, C2.1, C3.1, C4.1, C5.2, J1.2, J2.1, J2.6, J3.1, J4.1, J6.2, J7.4, R14.1, R18.1, U1.8 (VSSA), U1.23 (VSS), U1.35 (VSS), U1.47 (VSS), Y1.2; also elsewhere on the board
GPS_PPS: U1.11 (PA1); also elsewhere on the board
GPS_RX: JP3.3 (B), JP4.3 (B); also elsewhere on the board
GPS_TX: JP3.1 (A), JP4.1 (A); also elsewhere on the board
I2C_SCL: J4.4, R2.2, U1.42 (PB6); also elsewhere on the board
I2C_SDA: J4.3, R3.2, U1.43 (PB7); also elsewhere on the board
Mag_Reset: U1.33 (PA12); also elsewhere on the board
Mag_Set: U1.32 (PA11); also elsewhere on the board
unnamed: J5.1, U1.25 (PB12)
unnamed: J5.2, U1.26 (PB13)
unnamed: J5.3, U1.27 (PB14)
unnamed: J5.4, U1.28 (PB15)
unnamed: JP1.2 (C), U1.21 (PB10)
unnamed: JP2.2 (C), U1.22 (PB11)
unnamed: JP3.2 (C), U1.12 (PA2)
unnamed: JP4.2 (C), U1.13 (PA3)
unnamed: JP5.2 (C), U1.30 (PA9)
unnamed: JP6.2 (C), U1.31 (PA10)
unnamed: R10.2, R13.1, R14.2
unnamed: R11.2, R17.1, R18.2
unnamed: R1.1, U1.5 (PD0), Y1.1
unnamed: R1.2, U1.6 (PD1), Y1.3
RESET: C5.1, J6.1, R16.2, U1.7 (NRST); also elsewhere on the board
Radio_RX: J3.2, JP1.3 (B), JP2.3 (B)
Radio_TX: J3.3, JP1.1 (A), JP2.1 (A)
SD_CD: R15.2, U1.40 (PB4); also elsewhere on the board
SD_CS: R12.2, U1.41 (PB5); also elsewhere on the board
SPI_ADC_DRDY: R7.2, U1.29 (PA8); also elsewhere on the board
SPI_Acc_ADC_CS: R9.2, U1.10 (PA0); also elsewhere on the board
SPI_MISO: R5.2, U1.16 (PA6); also elsewhere on the board
SPI_MOSI: R4.2, U1.17 (PA7); also elsewhere on the board
SPI_Mag_ADC_CS: R8.2, U1.14 (PA4); also elsewhere on the board
SPI_SCK: R6.2, U1.15 (PA5); also elsewhere on the board
SWCLK: J7.3, U1.37 (PA14)
SWDIO: J7.2, U1.34 (PA13)
XBee_RX: JP5.3 (B), JP6.3 (B); also elsewhere on the board
XBee_TX: JP5.1 (A), JP6.1 (A); also elsewhere on the board

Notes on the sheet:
Default: 3-2
Default: 1-2

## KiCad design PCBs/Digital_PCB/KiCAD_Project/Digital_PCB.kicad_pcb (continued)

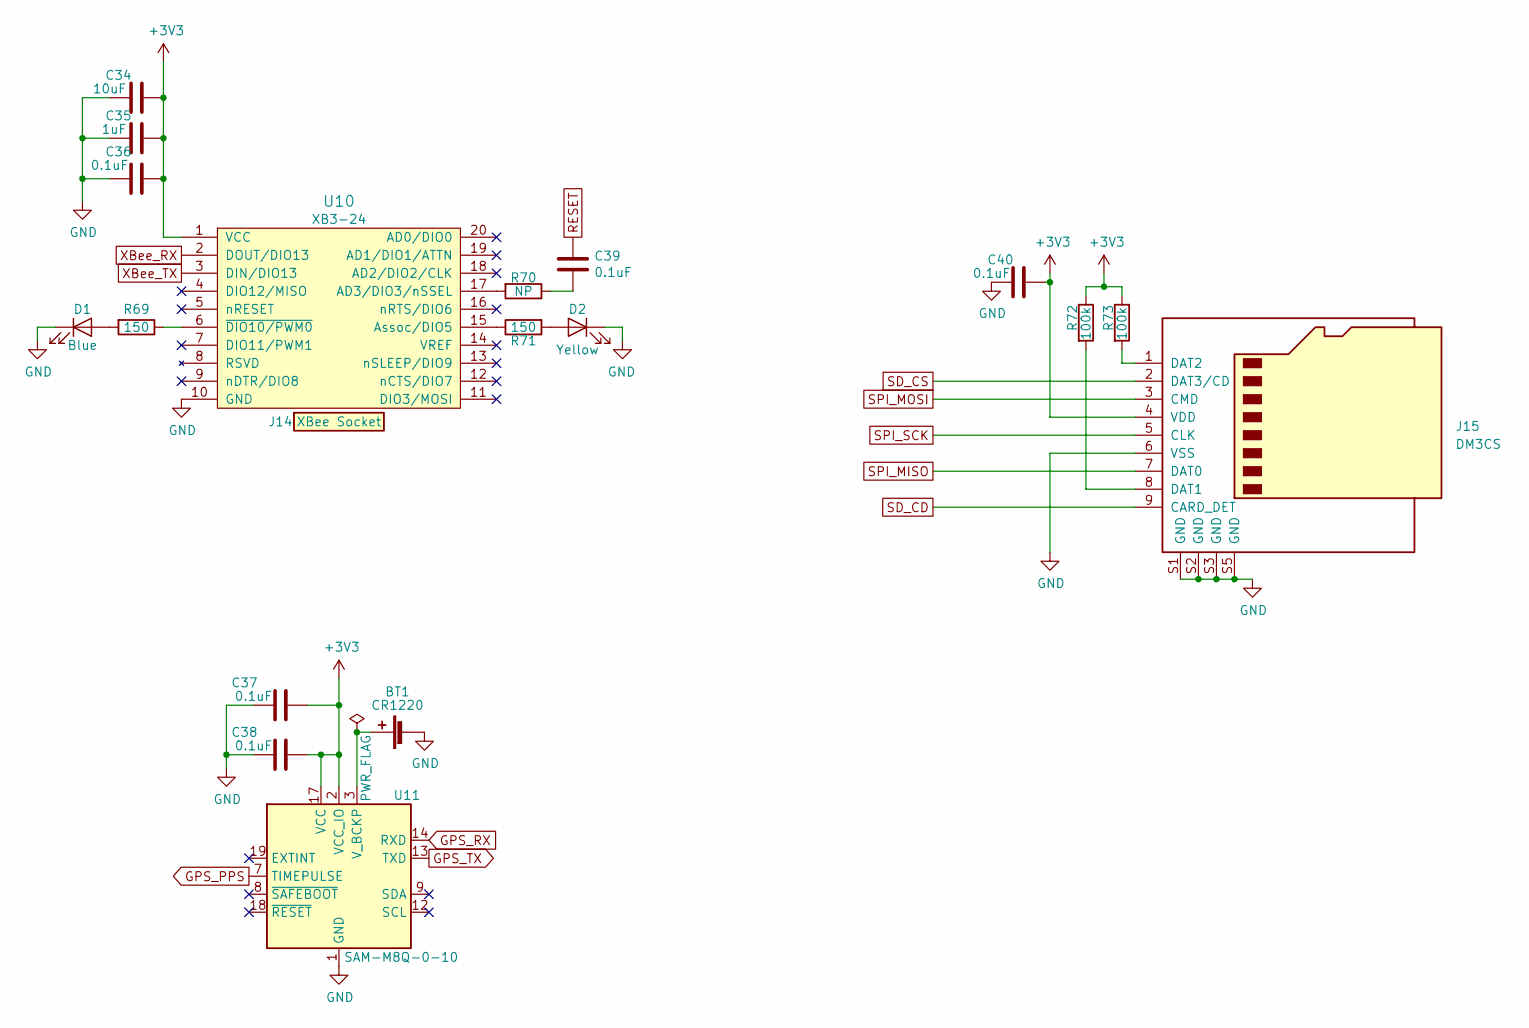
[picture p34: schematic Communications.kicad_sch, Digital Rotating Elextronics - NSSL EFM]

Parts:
BT1: 1-0000246
C34: 1-0000075
C35: 1-0000018
C36, C37, C38, C39, C40: 1-0000007
D1: 1-0000599
D2: 1-0000601
J14: 1-0000050
J15: 1-0000190
R69, R71: 1-0000008
R70: 1-0000006
R72, R73: 1-0000174
U10: 1-0000785
U11: 1-0000446

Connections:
+3V3: C34.1, C35.1, C36.1, C37.1, C38.1, C40.2, J15.4 (VDD), R72.1, R73.1, U10.1 (VCC), U11.2 (VCC_IO), U11.17 (VCC); also elsewhere on the board
GND: BT1.2 (-), C34.2, C35.2, C36.2, C37.2, C38.2, C40.1, D1.1 (K), D2.1 (K), J15.6 (VSS), J15.S1 (GND), J15.S2 (GND), J15.S3 (GND), J15.S5 (GND), U10.10 (GND), U11.1 (GND), U11.4 (GND), U11.5 (GND), U11.6 (GND), U11.10 (GND), U11.11 (GND), U11.15 (GND), U11.16 (GND), U11.20 (GND); also elsewhere on the board
GPS_PPS: U11.7 (TIMEPULSE); also elsewhere on the board
GPS_RX: U11.14 (RXD); also elsewhere on the board
GPS_TX: U11.13 (TXD); also elsewhere on the board
unnamed: BT1.1 (+), U11.3 (V_BCKP)
unnamed: C39.2, R70.1
unnamed: D1.2 (A), R69.2
unnamed: D2.2 (A), R71.2
unnamed: J15.8 (DAT1), R72.2
unnamed: J15.1 (DAT2), R73.2
unnamed: R70.2, U10.17 (AD3/DIO3/nSSEL)
unnamed: R71.1, U10.15 (Assoc/DIO5)
unnamed: R69.1, U10.6 (~DIO10/PWM0)
RESET: C39.1; also elsewhere on the board
SD_CD: J15.9 (CARD_DET); also elsewhere on the board
SD_CS: J15.2 (DAT3/CD); also elsewhere on the board
SPI_MISO: J15.7 (DAT0); also elsewhere on the board
SPI_MOSI: J15.3 (CMD); also elsewhere on the board
SPI_SCK: J15.5 (CLK); also elsewhere on the board
XBee_RX: U10.2 (DOUT/DIO13); also elsewhere on the board
XBee_TX: U10.3 (DIN/DIO13); also elsewhere on the board

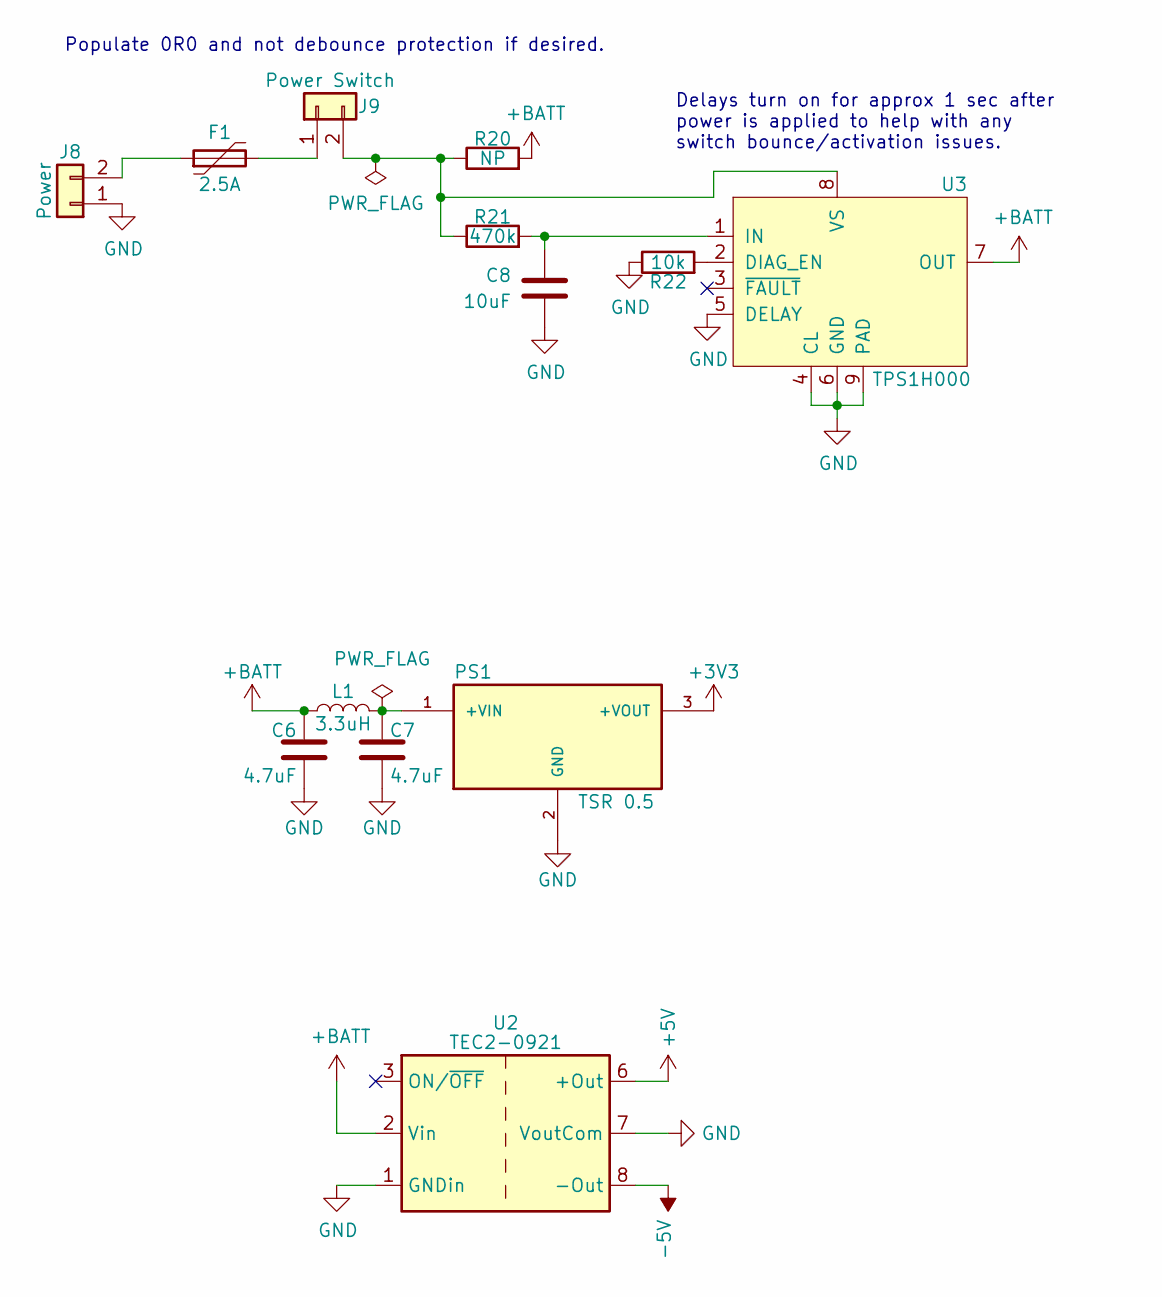
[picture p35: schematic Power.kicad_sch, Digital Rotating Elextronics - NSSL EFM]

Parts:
C6, C7: 1-0000136
C8: 1-0000075
F1: 1-0000269
J8, J9: NP_Conn_01x02_Relief; SolderWire_1x02_Relief
L1: 1-0000931
PS1: 1-0000727
R20: 1-0000006
R21: 1-0000068
R22: 1-0000010
U2: 1-0000465
U3: 1-0000576

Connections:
+3V3: PS1.3 (+VOUT); also elsewhere on the board
+5V: U2.6 (+Out); also elsewhere on the board
+BATT: C6.1, L1.1, R20.2, U2.2 (Vin), U3.7 (OUT); also elsewhere on the board
-5V: U2.8 (-Out); also elsewhere on the board
GND: C6.2, C7.2, C8.1, J8.1, PS1.2 (GND), R22.1, U2.1 (GNDin), U2.7 (VoutCom), U3.4 (CL), U3.5 (DELAY), U3.6 (GND), U3.9 (PAD); also elsewhere on the board
unnamed: F1.1, J8.2
unnamed: F1.2, J9.1
unnamed: J9.2, R20.1, R21.1, U3.8 (VS)
unnamed: C7.1, L1.2, PS1.1 (+VIN)
unnamed: R22.2, U3.2 (DIAG_EN)
unnamed: C8.2, R21.2, U3.1 (IN)

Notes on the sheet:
Populate 0R0 and not debounce protection if desired.
Delays turn on for approx 1 sec after power is applied to help with any switch bounce/activation issues.

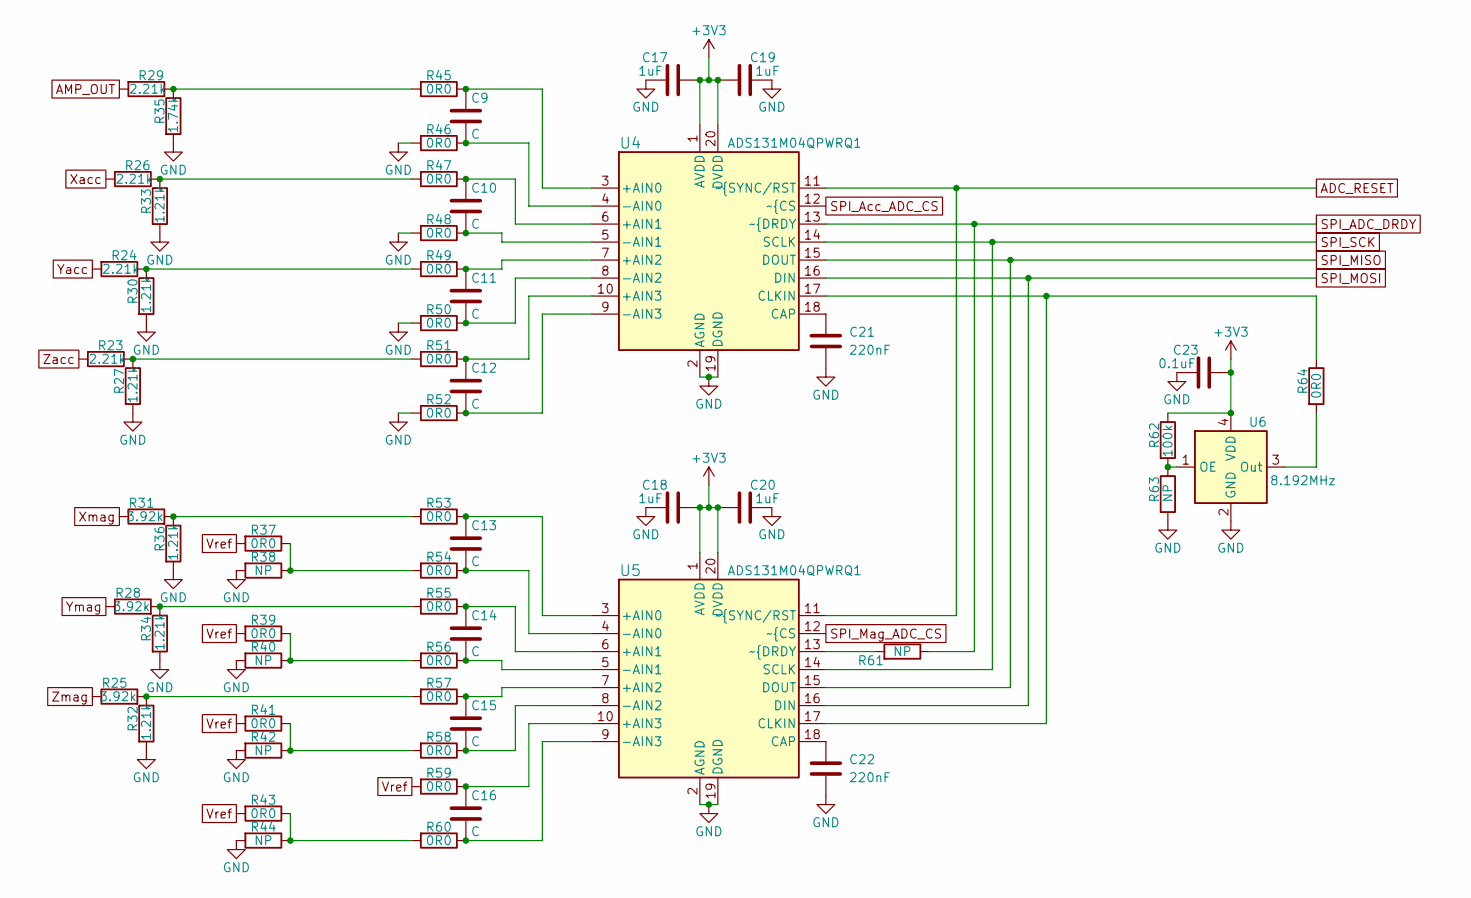
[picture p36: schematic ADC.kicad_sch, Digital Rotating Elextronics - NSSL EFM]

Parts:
C9, C10, C11, C12, C13, C14, C15, C16: C; C_0603_1608Metric
C17, C18, C19, C20: 1-0000018
C21, C22: 1-0000926
C23: 1-0000007
R23, R24, R26, R29: 1-0001551
R25, R28, R31: 1-0001554
R27, R30, R32, R33, R34, R36: 1-0001553
R35: 1-0001552
R37, R38, R39, R40, R41, R42, R43, R44, R45, R46, R47, R48, R49, R50, R51, R52, R53, R54, R55, R56, R57, R58, R59, R60, R61, R63, R64: 1-0000006
R62: 1-0000174
U4, U5: 1-0001530
U6: 1-0001542

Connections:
+3V3: C17.1, C18.1, C19.1, C20.1, C23.2, R62.1, U4.1 (AVDD), U4.20 (DVDD), U5.1 (AVDD), U5.20 (DVDD), U6.4 (VDD); also elsewhere on the board
ADC_RESET: U4.11 (~{SYNC/RST), U5.11 (~{SYNC/RST); also elsewhere on the board
AMP_OUT: R29.2; also elsewhere on the board
GND: C17.2, C18.2, C19.2, C20.2, C21.2, C22.2, C23.1, R27.2, R30.2, R32.2, R33.2, R34.2, R35.2, R36.2, R38.2, R40.2, R42.2, R44.2, R46.2, R48.2, R50.2, R52.2, R63.2, U4.2 (AGND), U4.19 (DGND), U5.2 (AGND), U5.19 (DGND), U6.2 (GND); also elsewhere on the board
unnamed: R23.1, R27.1, R51.2
unnamed: R24.1, R30.1, R49.2
unnamed: R25.2, R32.1, R57.2
unnamed: R26.1, R33.1, R47.2
unnamed: R28.2, R34.1, R55.2
unnamed: R29.1, R35.1, R45.2
unnamed: R31.2, R36.1, R53.2
unnamed: R37.1, R38.1, R54.2
unnamed: R39.1, R40.1, R56.2
unnamed: R41.1, R42.1, R58.2
unnamed: R43.1, R44.1, R60.2
unnamed: C9.1, R45.1, U4.3 (+AIN0)
unnamed: C10.1, R47.1, U4.6 (+AIN1)
unnamed: C11.1, R49.1, U4.7 (+AIN2)
unnamed: C12.1, R51.1, U4.10 (+AIN3)
unnamed: C9.2, R46.1, U4.4 (-AIN0)
unnamed: C10.2, R48.1, U4.5 (-AIN1)
unnamed: C11.2, R50.1, U4.8 (-AIN2)
unnamed: C12.2, R52.1, U4.9 (-AIN3)
unnamed: C21.1, U4.18 (CAP)
unnamed: R64.1, U4.17 (CLKIN), U5.17 (CLKIN)
unnamed: C13.1, R53.1, U5.3 (+AIN0)
unnamed: C14.1, R55.1, U5.6 (+AIN1)
unnamed: C15.1, R57.1, U5.7 (+AIN2)
unnamed: C16.1, R59.1, U5.10 (+AIN3)
unnamed: C13.2, R54.1, U5.4 (-AIN0)
unnamed: C14.2, R56.1, U5.5 (-AIN1)
unnamed: C15.2, R58.1, U5.8 (-AIN2)
unnamed: C16.2, R60.1, U5.9 (-AIN3)
unnamed: C22.1, U5.18 (CAP)
unnamed: R61.2, U5.13 (~{DRDY)
unnamed: R62.2, R63.1, U6.1 (OE)
unnamed: R64.2, U6.3 (Out)
SPI_ADC_DRDY: R61.1, U4.13 (~{DRDY); also elsewhere on the board
SPI_Acc_ADC_CS: U4.12 (~{CS); also elsewhere on the board
SPI_MISO: U4.15 (DOUT), U5.15 (DOUT); also elsewhere on the board
SPI_MOSI: U4.16 (DIN), U5.16 (DIN); also elsewhere on the board
SPI_Mag_ADC_CS: U5.12 (~{CS); also elsewhere on the board
SPI_SCK: U4.14 (SCLK), U5.14 (SCLK); also elsewhere on the board
Vref: R37.2, R39.2, R41.2, R43.2, R59.2; also elsewhere on the board
Xacc: R26.2; also elsewhere on the board
Xmag: R31.1; also elsewhere on the board
Yacc: R24.2; also elsewhere on the board
Ymag: R28.1; also elsewhere on the board
Zacc: R23.2; also elsewhere on the board
Zmag: R25.1; also elsewhere on the board


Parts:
C24, C26, C27, C28, C29, C32, C33: 1-0000007
C25: 1-0000075
C30: 1-0000322
C31: 1-0000136
J10, J13: HMC Breakout Pins; PinHeader_1x10_P2.54mm_Vertical
J11, J12: 1-0001555
Q1: 1-0001548
Q2: 1-0001214
R65: 1-0000006
R66, R68: 1-0001549
R67: 1-0001528
U7: 1-0001535
U8: 1-0001471
U9: 1-0001543

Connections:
+3V3: C24.2, C25.1, C26.1, U7.14 (VS), U7.15 (VS), U8.2 (CSB), U8.6 (Vddio), U8.8 (Vdd); also elsewhere on the board
+BATT: C32.1, J13.10, R67.1, U9.10 (V+); also elsewhere on the board
/Peripherals/HMC1: J13.1, R65.1, U9.1 (SR-)
/Peripherals/HMC2: J13.2, U9.2 (Xoff-)
/Peripherals/HMC3: J13.3, U9.3 (Ztrim)
/Peripherals/HMC4: J13.4, U9.4 (Xtrim)
/Peripherals/HMC5: J13.5, U9.5 (Yoff-)
/Peripherals/HMC11: J10.1, U9.11 (Vsense)
/Peripherals/HMC12: J10.2, U9.12 (Vbridge)
/Peripherals/HMC13: J10.3, U9.13 (Vbais)
/Peripherals/HMC15: J10.5, U9.15 (Ytrim)
/Peripherals/HMC16: J10.6, U9.16 (Yoff+)
/Peripherals/HMC17: C30.1, J10.7, U9.17 (SR+)
/Peripherals/HMC18: J10.8, U9.18 (Xoff+)
/Peripherals/HMC19: J10.9, U9.19 (Zoff-)
/Peripherals/HMC20: J10.10, U9.20 (Zoff+)
GND: C24.1, C25.2, C26.2, C27.2, C28.2, C29.2, C31.2, C32.2, J13.9, Q1.1 (S1), Q2.1 (E), R65.2, U7.2 (ST), U7.3 (COM), U7.5 (COM), U7.6 (COM), U7.7 (COM), U8.1 (GND), U8.5 (SDO), U8.7 (GND), U9.9 (GND); also elsewhere on the board
I2C_SCL: U8.4 (SCK); also elsewhere on the board
I2C_SDA: U8.3 (SDI); also elsewhere on the board
Mag_Reset: Q1.2 (G1); also elsewhere on the board
Mag_Set: Q2.2 (B); also elsewhere on the board
unnamed: C30.2, Q1.5 (D2), Q1.6 (D2), Q1.7 (D1), Q1.8 (D1)
unnamed: C33.1, Q1.4 (G2), R66.2
unnamed: C31.1, Q1.3 (S2), R66.1, R67.2, R68.1
unnamed: C33.2, Q2.3 (C), R68.2
Vref: J13.8, U9.8 (Vref); also elsewhere on the board
Xacc: C27.1, U7.12 (XOUT); also elsewhere on the board
Xmag: J13.7, U9.7 (Xout); also elsewhere on the board
Yacc: C28.1, U7.10 (YOUT); also elsewhere on the board
Ymag: J10.4, U9.14 (Yout); also elsewhere on the board
Zacc: C29.1, U7.8 (ZOUT); also elsewhere on the board
Zmag: J13.6, U9.6 (Zout); also elsewhere on the board

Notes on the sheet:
Address 0x76



Board: 4 copper layers, 75.0 x 84.8 mm, 161 parts (6 on the bottom side), 119 nets.

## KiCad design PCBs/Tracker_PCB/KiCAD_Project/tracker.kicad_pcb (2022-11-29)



Board: 4 copper layers, 78.7 x 57.2 mm, 58 parts (3 on the bottom side), 38 nets.

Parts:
BT1: CR1220; S8411-45R
C1, C2, C3, C6, C7, C8, C9, C10, C11, C14: 1-0000007
C4, C12, C13: 1-0000075
C5: 1-0000018
D1, D2: Blue; LED_0805_2012Metric
D3: Yellow; LED_0805_2012Metric
D4: Green; LED_0805_2012Metric
F1: Polyfuse; Fuse_1812_4532Metric
FID1, FID2: Fiducial; Fiducial_1mm_Mask2mm
H1, H2, H3, H4: MountingHole; MountingHole_3.2mm_M3_DIN965
J1: RockBlock9603; picoblade
J2: ICSP; PinHeader_2x03_P2.54mm_Vertical
J4: Battery; PinHeader_1x02_P2.54mm_Vertical
PCB1: barepcb; BarePCB
Q1, Q2: BSS138; SOT-23
R1, R2, R3, R4: 1-0000013
R5, R16, R18: 1-0000010
R6, R8, R9, R17: 1-0000008
R7, R10, R11, R12, R13, R14, R15: 1-0000006
SW1: SW_SPST; SW_GF-123-0054
U1: XBee
U2: ATmega328P-AU; TQFP-32_7x7mm_P0.8mm
U3: TSR2; TSR 2-2450
U4: RockBlockMechanical; RockBlock_Mechanical
U5: ublox_SAM-M8Q
U6: MIC5219-3.3YM5; SOT-23-5
Y1: 16MHz; Resonator

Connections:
+3V3: C1.1, C2.1, C3.1, C4.1, C5.1, C7.1, C9.1, C11.1, C13.1, C14.1, J2.6, Q1.1, Q2.1, R1.1, R3.1, R5.1, R16.1, R17.1, R18.1, U1.1, U2.4, U2.6, U2.18, U5.2, U5.17, U6.5
GPS_PPS: R16.2, U2.10, U5.7
GPS_RX: R12.1, U5.14
GPS_TX: R13.1, U5.13
MISO: J2.1, U2.16
MOSI: J2.5, U2.15
unnamed: BT1.1, U5.3
unnamed: C6.1, U2.20
unnamed: C8.2, R7.1
unnamed: C10.1, F1.2, SW1.2
unnamed: D1.2, R6.2
unnamed: D2.2, R8.2
unnamed: D3.2, R9.2
unnamed: D4.2, R17.2
unnamed: F1.1, U3.1
unnamed: J4.2, SW1.1
unnamed: R7.2, U1.17
unnamed: R8.1, U1.6
unnamed: R9.1, U1.15
unnamed: R10.2, U2.30
unnamed: R11.2, U2.31
unnamed: R12.2, U2.32
unnamed: R13.2, U2.1
unnamed: R14.2, U2.2
unnamed: R15.2, U2.9
unnamed: U2.7, Y1.1
unnamed: U2.8, Y1.3
RB_5V: C12.1, J1.8, R2.1, R4.1, U3.3, U6.1, U6.3
RB_GND: BT1.2, C1.2, C2.2, C3.2, C4.2, C5.2, C6.2, C7.2, C9.2, C10.2, C11.2, C12.2, C13.2, C14.2, D1.1, D2.1, D3.1, D4.1, J1.10, J2.4, J4.1, U1.10, U2.3, U2.5, U2.21, U3.2, U5.1, U5.4, U5.5, U5.6, U5.10, U5.11, U5.15, U5.16, U5.20, U6.2, Y1.2
RB_NetAv: J1.4, R18.2, U2.11
RB_RXI: J1.6, Q2.3, R4.2
RB_RXI_3V3: Q2.2, R3.2, R11.1
RB_TXO: J1.1, Q1.3, R2.2
RB_TXO_3V3: Q1.2, R1.2, R10.1
RESET: C8.1, J2.3, R5.2, U2.29
SCK: J2.2, R6.1, U2.17
XBee_from_Uc: R15.1, U1.3
XBee_to_Uc: R14.1, U1.2

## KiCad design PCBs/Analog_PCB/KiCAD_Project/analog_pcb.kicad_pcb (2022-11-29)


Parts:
C1, C2, C5, C9, C11, C16: 1u; C_0603_1608Metric
C3, C4, C10, C12, C14: 0.1u; C_0603_1608Metric
C6: 0.1u; 1-0000787
C7, C8: 0.39nF; C_0603_1608Metric
C13, C15: 20p; C_0603_1608Metric
D1, D2: 1N4148; D_SOD-323F
FID1, FID2, FID3: Fiducial; Fiducial_1mm_Dia_2mm_Outer
H1: MountingHole; MountingHole_3.2mm_M3_ISO7380
J1: Board to Board; Pin_Header_Straight_1x10_Pitch2.54mm
PCB1: barepcb
R1: 100M; R_1206_HandSoldering
R2: 100; R_0603_1608Metric
R3: 10k; R_0603_1608Metric
TP1, TP2, TP3, TP4, TP5: TestPoint; Measurement_Point_Round-SMD-Pad_Small
U1: LF356; SOIC-8_3.9x4.9mm_Pitch1.27mm
U2: LTC1569-6; SOIC-8_3.9x4.9mm_Pitch1.27mm
U3: ATtiny45-20SU; SOIC-8_5.275x5.275mm_P1.27mm
Y1: 20MHz; Crystal_HC49-U_Vertical

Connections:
+5V: C1.1, C3.1, C5.1, C9.1, C10.1, C11.1, C12.1, J1.2, U1.7 (V+), U2.7 (V+), U3.8 (VCC)
-5V: C2.2, C4.2, C5.2, C14.1, C16.1, J1.3, R3.1, U1.4 (V-), U2.4 (V-)
FCLK: TP5.1, U2.5 (Div/Clk), U3.5 (AREF/PB0)
GND: C1.2, C2.1, C3.2, C4.1, C7.2, C8.2, C9.2, C10.2, C11.2, C12.2, C13.1, C14.2, C15.1, C16.2, D1.1 (K), D2.2 (A), J1.1, J1.6, U1.3 (+), U2.2 (-In), U2.3 (GND), U3.4 (GND)
In: C7.1, J1.4, R2.2, TP1.1
unnamed: C6.1, R1.1, TP4.1, U1.6, U2.1 (+In)
unnamed: C6.2, C8.1, D1.2 (A), D2.1 (K), R1.2, R2.1, TP2.1, U1.2 (-)
unnamed: C13.2, U3.2 (XTAL1/PB3), Y1.1
unnamed: C15.2, U3.3 (XTAL2/PB4), Y1.2
unnamed: R3.2, U2.6 (Rx)
Out: J1.5, TP3.1, U2.8 (Out)

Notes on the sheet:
Populate with standard header with pins pointing downward from the bottom of the PCBA.


Board: 4 copper layers, 44.4 x 31.8 mm, 36 parts (0 on the bottom side), 11 nets.

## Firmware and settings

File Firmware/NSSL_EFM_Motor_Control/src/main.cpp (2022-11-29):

/*
 * NSSL EFM Motor Control Board
 * 
 * This board and firmware are responsible for controlling the motor speed
 * to keep the motor running at a constant RPM even as the batteries run down.
 * The rate of rotation is monitored via a hall effect sensor and magnet on the
 * rotating shaft. The average RPM over several seconds is maintained with new
 * readings being rejected a spurious if they fall outside the average.
 * 
 * The loop runs the PID controller that updates the PWM to the motor every 200ms.
 * Pulses from the hall-effect sensor trigger an ISR that determines the time that
 * revolution took at adds it to the moving average of RPM assuming that it is not
 * more than 10% different from the average. This should help eliminate any signals
 * from discharges or other random events.
 */

#include <Arduino.h>
#include <FIR.h>
#include <PID_v1.h>
#include <IWatchdog.h>
#include "pins.h"

// Globals
volatile uint16_t encoder_pulses = 0; // Counts pulses for the encoder 
char motor_cutoff_enable = 1;
char tone_system_enable = 1;
double setpoint = 120; // Target RPM for the motor
double feedback = 0; // Feedback for the motor PID
double pwm_output = 80; // Output from the PID
double pid_kp=0.5;
double pid_ki=0.07;
double pid_kd=0.0;
uint16_t motor_current_limit = 300; // mA limit before motor cutoff

// Instances
FIR<float, 4> fir;  // Since we are shooting for about 120 RPM this is a 10 second average.
PID motor_pid(&feedback, &pwm_output, &setpoint, pid_kp, pid_ki, pid_kd, REVERSE);

void EncoderISR()
{
  /*
   * Encoder ISR
   * 
   * This ISR encrements encoder pulse counts.
   */
  encoder_pulses += 1;
}

void PlayTones()
{
  /*
   * Play Tones
   * 
   * Play tones to aid in location of the instrument.
   */
    tone(PIN_BUZZER, 1000);
    delay(1000);
    tone(PIN_BUZZER, 2000);
    delay(1000);
    tone(PIN_BUZZER, 3000);
    delay(1000);
    tone(PIN_BUZZER, 4000);
    delay(1000);
    tone(PIN_BUZZER, 5000);
    delay(1000);
    noTone(PIN_BUZZER);
}

void Shutdown()
{
  /*
   * Shutdown
   * 
   * Turns off the motor, plays tones, then tries a restart of everything after ~1 minute.
   */
  analogWrite(PIN_MOTOR_PWM, 255);
  Serial.println("Shutting down.");
  if (tone_system_enable)
  {
    PlayTones();
  }
  for (uint8_t i=0; i<2; i++)
  {
    IWatchdog.reload();
    delay(20000);
  }
  IWatchdog.reload();
  while(1){} // Spin until the watchdog catches us!
}

uint16_t CurrentSafetyCheck(uint16_t current_limit_milliamps)
{
  /*
   * Current Safety Check
   * 
   * Checks the current draw of the motor and if it is over the given threshold we
   * go to the shutdown state if enabled. Otherwise return to where we were.
   */
  uint16_t voltage = 0;
  for (int i=0; i<10; i++)
  {
    voltage += analogRead(PIN_CURRENT_SENSE);
  }
  voltage /= 10;
  // Current = voltage / (Rs * Rl)
  uint16_t current = voltage * 322 / 1000;
  if ((current >= current_limit_milliamps) && motor_cutoff_enable)
  {
    Serial.print("Current limit encountered: ");
    Serial.print(current);
    Serial.println(" mA");
    Shutdown();
  }
  return current;
}

uint16_t ReadBatteryVoltage()
{
  /*
   * Read Battery Voltage
   * 
   * Check the battery voltage and return it as a number in millivolts.
   * Second multiplier is to account for the hardware voltage divider.
   */
  return analogRead(PIN_VBAT_SENSE) * 3.22656 * 3.7037;
}

void AttachEncoderInterrupt()
{
  /*
   * Start the encoder pulse counting ISR.
   */
  attachInterrupt(digitalPinToInterrupt(PIN_MOTOR_ENCODER), EncoderISR, FALLING);
}


void DetachEncoderInterrupt()
{
  /*
   * Stop the encoder pulse counting ISR.
   */
  detachInterrupt(digitalPinToInterrupt(PIN_MOTOR_ENCODER));
}


float_t CalculateRPM(uint16_t count, uint32_t start_time, uint32_t end_time)
{
  /*
   * Calculate the RPM of the motor given 6 pulses/rev and the start/end times.
   */
  return (count / 6.0) / ((end_time - start_time) / 60000);
}

float RPMCheck(uint32_t count_interval_ms)
{
  /* Checks on the RPM of the motor - if we are counting, see if we should keep counting.
   * If we are still counting, return -1. If time has elapsed, we stop counting,
   * calculate RPM, restart counting, return the RPM.
   */
  static uint32_t start_counting = millis();
  static uint32_t stop_counting = millis();

  // If it's time to do the RPM update
  if ((millis() - start_counting) >= count_interval_ms)
  {
    // Stop the interrupt, do the math
    DetachEncoderInterrupt();
    stop_counting = millis();
    float rpm = (encoder_pulses / 6.0) * ((stop_counting - start_counting) / 60000.0);
    encoder_pulses = 0;

    // Restart the interrupt
    AttachEncoderInterrupt();
    start_counting = millis();

    return rpm;
  }

  // Not time to do the update yet
  return -1;
}

void VerifyRotation()
{
  // Verify that the motor is rotating at least a little (1 pulse/100ms). Blocking.
  if (motor_cutoff_enable)
  {
   uint16_t encoder_initial = encoder_pulses;
   delay(100);
   uint16_t encoder_final = encoder_pulses;
   if ((encoder_final - encoder_initial) <= 0)
   {
     Shutdown();
   }
  }
}

void setup()
{
  /*
   * Setup
   * 
   * This runs once at boot and sets up all of the pin states, classes we'll need, etc.
   */

  IWatchdog.begin(26000000); //max 26208000

  delay(2000);  // Wait incase a user is starting a terminal
  Serial.begin(115200); // Start a serial port
  Serial.println("NSSL EFM Motor Controller");
  Serial.println("Leeman Geophysical LLC");
  Serial.println("Setting up controller...");

  // Pin Setup
  pinMode(PIN_MOTOR_ENCODER, INPUT);
  pinMode(PIN_MOTOR_DIRECTION, OUTPUT);
  pinMode(PIN_TONE_SYSTEM_ENABLE, INPUT);
  pinMode(PIN_MOTOR_CUTOFF_ENABLE, INPUT);

  
  // PID Setup
  motor_pid.SetSampleTime(9000);

  // Read the dip switch settings - this only happens once on boot!
  motor_cutoff_enable = !digitalRead(PIN_MOTOR_CUTOFF_ENABLE);
  tone_system_enable = !digitalRead(PIN_TONE_SYSTEM_ENABLE);
  
  if (motor_cutoff_enable){Serial.println("Motor Cutoff Enabled.");}
  else {Serial.println("Motor Cutoff Disabled.");}

  if (tone_system_enable){Serial.println("Tone System Enabled.");}
  else {Serial.println("Tone System Disabled.");}

  // Motor Controller Setup
  digitalWrite(PIN_MOTOR_DIRECTION, LOW);
  analogWrite(PIN_MOTOR_PWM, 10); // Start the motor
  delay(2000);

  // Make sure the current is okay after spinup
  CurrentSafetyCheck(motor_current_limit);

  IWatchdog.reload();

  // Get the RPM update method running by calling with a short interval
  RPMCheck(1000);
  delay(1100);
  RPMCheck(1000);
  delay(1100);
  // Turn on the PID
  motor_pid.SetMode(AUTOMATIC);
  Serial.println("Startup Complete");
  Serial.println("Milliseconds, Feedback, Setpoint, PWM_Output, Current_mA, Battery_mV");

}

void loop()
{
  /*
   * Main Loop
   * 
   * The main loop checks if a new rpm reading is available (interrupt has fired) and
   * updates our estimate of the feedback variable. It then calls compute on the PID
   * which will update every 200ms. On update the PWM value is updated and the parameters
   * are printed out on the serial port. We also check the current and if it is over our
   * threshold, we turn off the motor.
   */

  IWatchdog.reload();

  // Check the current draw
  uint16_t current_milliamps = CurrentSafetyCheck(motor_current_limit);

  // Check the battery voltage
  uint16_t battery_voltage = ReadBatteryVoltage();

  // Check that in 100ms we at least get 1 encoder pulse - otherwise stop!
  VerifyRotation();

  // Check if there is an update to the motor RPM
  feedback = RPMCheck(10000);
  feedback = int(feedback);

  if (feedback != -1)
  {
    motor_pid.Compute();  // Compute and update
    analogWrite(PIN_MOTOR_PWM, pwm_output);
    Serial.print(millis());
    Serial.print(",");
    Serial.print(feedback);
    Serial.print(",");
    Serial.print(setpoint);
    Serial.print(",");
    Serial.print(pwm_output);
    Serial.print(",");
    Serial.print(current_milliamps);
    Serial.print(",");
    Serial.println(battery_voltage);
  }
}

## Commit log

2022-03-25 R42: 1-460 -> 1-678
    [GPS.sch, control_pcb.kicad_pcb]
2022-08-08 Updates to run at 40Hz and fix IMU reading scale. Tested with Eric B. on August 6th with demo unit.
    [main.cpp]
2022-10-11 Move cutdown to a product repo as it is not EFM specific
    [KiCAD_raw_BOM.csv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]
2022-11-29 Update GERBERS to match production
    [control_pcb-B_Cu.gbr, control_pcb-B_Mask.gbr, control_pcb-B_Paste.gbr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]
2022-11-29 Restructure to add mechanical files as well
    [ADC.sch, Control Foam 1.step, Control Foam 2.step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]
2022-11-29 Add readme and mechanical files
    [Control Foam 1.step, Control Foam 2.step, Control Foam 3.step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]
2022-11-29 Fix CR123 PCBA image
2022-11-29 Remove unused CR2 PCBA
    [KiCAD_raw_BOM.csv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]
2022-11-29 Move KiCAD project files up a level
    [ADC.sch, Fiber.sch, GPS.sch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]
2024-03-22 Added Orientation Paddle Project
    [Communications.kicad_sch, Orientation_Paddle.kicad_pcb, Orientation_Paddle.kicad_sch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]
2024-03-22 Updated Ori. Paddle Schematic with Final Revisions
    [Communications.kicad_sch, Orientation_Paddle.kicad_sch]
2024-03-22 Orientation Paddle Initial PCB Layout
    [Communications.kicad_sch, Orientation_Paddle.kicad_pcb, Orientation_Paddle.kicad_sch]
2024-03-26 Initial Digtal Rotating PCB Layout
    [ADC.kicad_sch, ADC.sch, Communications.kicad_sch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]
2024-03-26 Initial Motor Control PCB Layout
    [KiCAD_raw_BOM.csv, Power.kicad_sch, Power.sch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]
2024-03-28 Make production files for new motor PCB
    [KiCAD_raw_BOM.csv, Power.kicad_sch, Power.sch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]
2024-03-28 Update with some fixes
    [Communications.kicad_sch, KiCAD_raw_BOM.csv, Orientation_Paddle.kicad_pcb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]
2024-03-28 Rearrange and remove old files
    [ADC.sch, Fiber.sch, GPS.sch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]
2024-03-28 Minor fixups
    [ADC.kicad_sch, Communications.kicad_sch, Digital_PCB.kicad_pcb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]
2024-03-28 Orientation Paddle Revisions: Board resize to nice numbers Fixed Footprint/Symbols causing ERC Errors Fixed remaining ERC Errors (Schematic and PCB)
    [Orientation_Paddle.kicad_pcb, Orientation_Paddle.kicad_sch]
2024-03-28 Add digital PCB reorganized
    [ADC.kicad_sch, Communications.kicad_sch, Digital_PCB.kicad_pcb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]
2024-03-28 Digital PCB Revisions: Fixed ERC Footprint/Symbol Errors Fixed Remaining ERC Errors Relocated U7 to bottom of PCB
    [Digital_PCB.kicad_pcb, Digital_PCB.kicad_sch, motor_control.kicad_sch]
2024-03-28 Fixed Motor PCB ERC Issues and Copper to Edge Clearence
    [motor_control.kicad_pcb, motor_control.kicad_sch]
2024-03-28 Fixed Orientation Paddle ERC Issues and Copper to Edge Clearence
    [Orientation_Paddle.kicad_pcb, Orientation_Paddle.kicad_sch]
2024-04-03 Fixed Orientation Paddle to Have only 2 layer instead of 4
    [Orientation_Paddle.kicad_pcb]

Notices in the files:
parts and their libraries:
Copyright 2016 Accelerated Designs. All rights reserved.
